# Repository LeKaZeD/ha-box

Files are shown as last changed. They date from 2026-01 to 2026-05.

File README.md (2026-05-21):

# HA Box




**HA Box** is an open-source, modular home automation hub built around a Raspberry Pi 5 and Home Assistant OS. It integrates the main smart home protocols (Zigbee, Thread, 433 MHz) into a single 3D-printed enclosure, with a custom ESP32 interface board providing a local E-Paper display, touch, environmental sensing, and physical controls.

---

## Project overview

HA Box is composed of four independent layers that work together:

```
+---------------------------------------------------------------+
|  3D-printed enclosure  (modular, FDM-printable, upgradeable)  |
|                                                               |
|  +---------------------------+   +-------------------------+  |
|  |  Raspberry Pi 5 stack     |   |  haboxesp PCB + ESP32   |  |
|  |  - Pi 5                   |   |  - E-Paper display      |  |
|  |  - M.2 SSD hat            |   |  - Touch (FT6336U)      |  |
|  |  - HDMI/USB-C extension   |   |  - BME280 sensor        |  |
|  |  - Sonoff Dongle Plus E   |   |  - Temp sensor TMP102   |  |
|  |    (Zigbee + Thread)      |   |  - Fan (PWM)            |  |
|  |  - CC1101 module (planned)|   |  - Buzzer               |  |
|  |    (433 MHz, SPI)         |   |  - Power button + J2    |  |
|  |                           |   |                         |  |
|  |  [ Home Assistant OS ]    |   |                         |  |
|  |  [ HA Box App (py) ]   <--+---+--> UART                 |  |
|  +---------------------------+   +-------------------------+  |
+---------------------------------------------------------------+
```

| Layer | Description | Location |
|---|---|---|
| **Hardware** | Pi 5 stack, haboxesp PCB, Sonoff dongle, connectors | `hardware/` |
| **3D enclosure** | Modular, printable enclosure for all components | `hardware/3D plan/` |
| **ESP32 firmware** | Drives display, sensors, touch, fan, buzzer | `ha-box-esp/` |
| **HA App** | Python app: UART bridge to HA API and Supervisor | `ha-box/` |
| **HA integration** | Custom component: groups all HA Box entities in the device registry | `ha-integration/` |

---

## Hardware

### Raspberry Pi 5 stack

| Component | Description | Protocol |
|---|---|---|
| Raspberry Pi 5 | Main compute unit, runs Home Assistant OS | — |
| M.2 SSD hat | NVMe storage via PCIe | PCIe |
| HDMI + USB-C extension | Rear panel port routing | — |
| Sonoff Zigbee 3.0 USB Dongle Plus E | Zigbee and Thread coordinator | USB |
| CC1101 module | 433 MHz radio (planned) | SPI |

### haboxesp PCB + ESP32

The haboxesp is a custom PCB designed for this project. It hosts an ESP32 module and provides connectors for all user-facing peripherals. The ESP32 communicates with the Pi exclusively over UART.

| Component | Model | Interface |
|---|---|---|
| E-Paper display | GDEY037T03-FT21 (3.7", 240×416) | SPI |
| Touch controller | FT6336U (integrated in display) | I2C |
| Environmental sensor | BME280 (temperature, humidity, pressure) | I2C |
| Case temperature | Additional sensor | I2C / analog |
| Fan | 5V PWM | PWM |
| Buzzer | Haptic feedback | GPIO |
| Power button | Wake + shutdown trigger | GPIO |
| J2 connector | Raspberry Pi J2 header (power control) | — |

PCB design files (KiCad) and manufacturing exports are in `hardware/haboxesp/`.

### 3D-printed enclosure

The enclosure is designed in Fusion 360, modular and FDM-printable. Each part can be reprinted independently to accommodate hardware upgrades.

Printable parts (STL): `Box`, `Top`, `Backplate`, `Support`, `Pied`, `Button`.

| | |
|---|---|
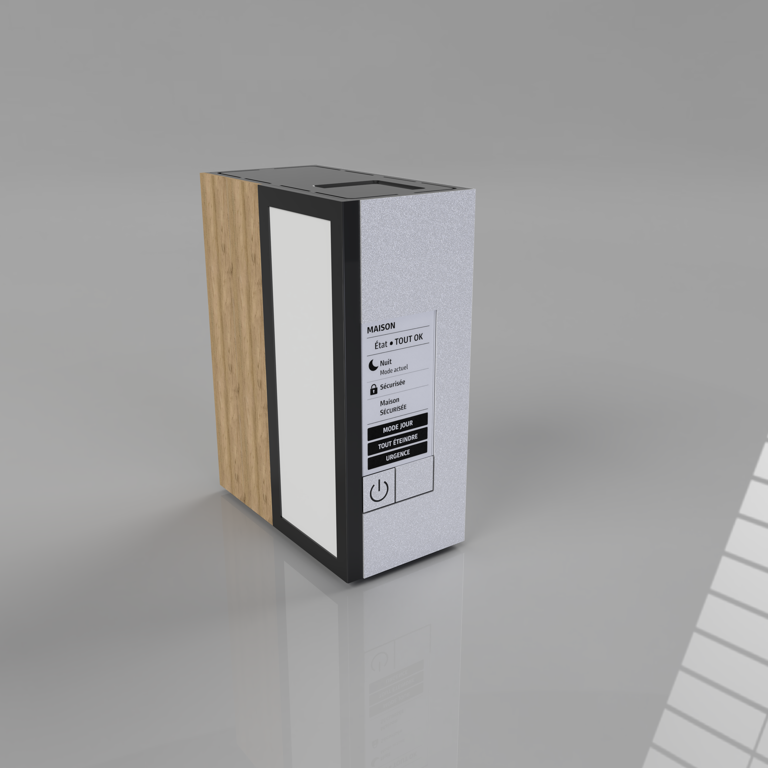
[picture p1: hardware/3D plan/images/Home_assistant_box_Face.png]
Front
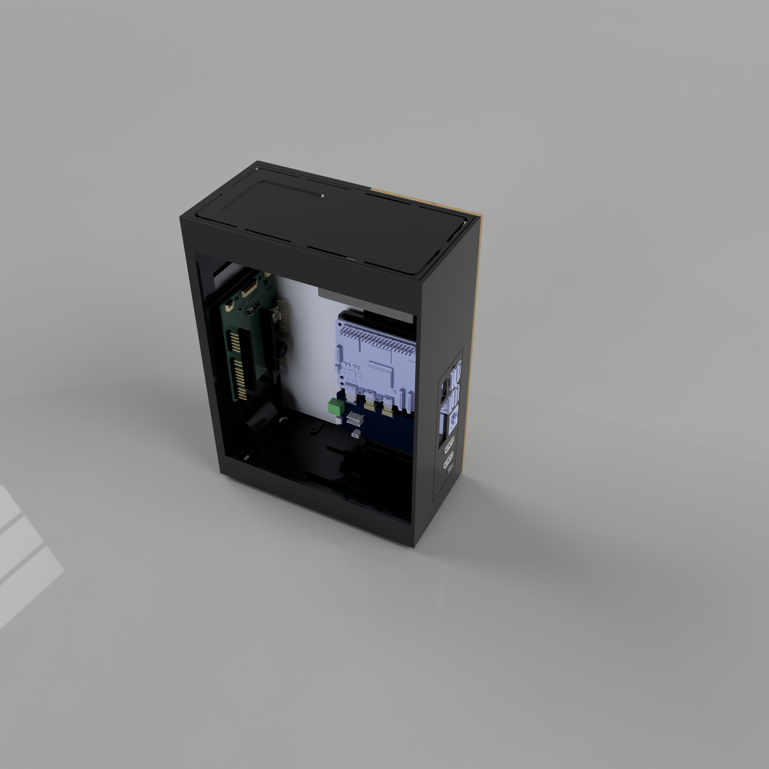
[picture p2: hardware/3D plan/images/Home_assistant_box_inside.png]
Inside
|  |  |

Fusion 360 source and STEP files: `hardware/3D plan/Fusion/`.

---

## ESP32 firmware

The ESP32 firmware (`ha-box-esp-fw/`) is a C++ application that:

- drives the E-Paper display (SPI) and front-light
- reads touch input (I2C, FT6336U)
- reads temperature/humidity/pressure (I2C, BME280)
- controls the fan (PWM, temperature-based)
- manages the power button (wake from deep sleep, shutdown request)
- controls the buzzer for haptic feedback
- communicates with the Pi App over UART using a line-based ASCII protocol

See [ha-box-esp-fw/ESPHOMEASSISTANT/ARCHITECTURE.md](ha-box-esp-fw/ESPHOMEASSISTANT/ARCHITECTURE.md) and [docs/ESP32_RASP_COM.md](docs/ESP32_RASP_COM.md) for the firmware architecture and UART protocol.

---

## HA App

The HA Box App (`ha-box/`) is a Home Assistant OS Supervisor App written in Python. It runs inside a Docker container on the Pi and acts as a bridge between the ESP32 (UART) and Home Assistant (HTTP API + Supervisor API).

It does not access display, sensors, or actuators directly. All peripherals are on the ESP32 side; the App communicates over UART0 and controls two Pi GPIOs (IO0 + EN) for OTA firmware updates.

### Raspberry Pi configuration (UART)

Edit `/mnt/boot/config.txt` physically (keyboard + screen on the Pi, or SD card / NVMe mounted on a computer). See [docs/HARDWARE.md](docs/HARDWARE.md#pi-configtxt-haos) for Pi 4 vs Pi 5 differences and SPI (CC1101) setup. Reboot after: `ha host reboot`.

### Installation

1. Add this repository to your Home Assistant Apps:

   

   Or manually: **Settings** → **App** → **App Store** → **⋮** → **Repositories** → add the URL.

2. Install **HA Box**.
3. Install the **HA Box custom integration**: copy `ha-integration/custom_components/ha_box/` to your HA `config/custom_components/` folder, then restart Home Assistant. This creates the HA Box device in the device registry.
4. Configure options according to your hardware (see below).
5. Start the App.

### Configuration

Configure options in the App UI or directly in YAML. Restart the App to apply changes.

```yaml
general:
  log_level: "info"                         # debug | info | warning | error | critical
  lang: "auto"                              # auto | fr | en

weather:
  weather_entity: "weather.forecast_home"   # HA weather entity
  update_interval: 300                      # seconds (10–3600)

bme280:
  enabled: true
  address: "auto"                           # auto | 0x76 | 0x77
  update_interval: 30                       # seconds

fan:
  enabled: false
  min_temp: 28                              # °C — fan starts
  max_temp: 60                              # °C — fan at full speed

ota:
  io0_gpio: 23                              # Pi BCM GPIO → ESP32 IO0
  en_gpio: 24                               # Pi BCM GPIO → ESP32 EN

daynight:
  update_interval: 60                       # seconds between sun.sun polls (10–3600)

clock:
  update_interval: 60                       # seconds (10–3600)

status:
  update_interval: 30                       # seconds
  exposed_addon_slugs: []                   # slugs that activate the "exposed" icon

uart:
  device: "auto"                            # auto | /dev/serial0 | /dev/ttyAMA0 | /dev/ttyUSB0

connection:
  connected_timeout: 120                    # seconds before switching to reconnecting
  reconnecting_timeout: 60                  # seconds before switching to disconnected
```

Language is auto-detected from the Home Assistant Core configuration (`/api/config` → `language`), with fallback to the container environment (`LANG`) and then English.

Fan and OTA options are sent to the ESP32 on every App startup and persisted in NVS — restart the App to apply changes.

---

## Current status (v0.2.0)

| Feature | Interface | Status |
|---|---|---|
| E-Paper display (Home, Loading, Settings pages) | SPI (ESP32) | Implemented |
| Touch navigation | I2C (ESP32) | Implemented |
| BME280 (temp, humidity, pressure) → HA entities | UART (ESP32 → Pi) | Implemented |
| TMP102 case temperature → HA entity | UART (ESP32 → Pi) | Implemented |
| Fan control (PWM, temperature-based, configurable) | PWM (ESP32) | Implemented |
| Power button (wake, soft shutdown, hard J2 stop) | UART + J2 (ESP32 ↔ Pi) | Implemented |
| Weather + clock display | UART (Pi → ESP32) | Implemented |
| HA status icons (Core, Supervisor, Net, Zigbee, Thread, Matter, External) | UART (Pi → ESP32) | Implemented |
| OTA firmware update (auto version check + flash over UART0) | UART0 + GPIO | Implemented |
| Boot failure recovery (blind OTA flash on ROM boot errors) | UART0 + GPIO | Implemented |
| Day/Night mode sync (sun.sun + manual override, HA event + binary sensor) | UART (Pi ↔ ESP32) | Implemented |
| HA Box integration (device registry, grouped entities) | HA custom component | In progress |
| CC1101 433 MHz | SPI (Pi) | Planned |

---

## Future: Compute Module board

The long-term vision is a custom carrier board built around a Raspberry Pi Compute Module, integrating the Pi, ESP32, radio modules, and all connectors on a single PCB. This would replace the current assembly of off-the-shelf boards and the haboxesp PCB with a more compact, reliable, and user-friendly product.

Early design work is in `hardware/cm5/`.

---

## Repository structure

```
ha-box/
├── hardware/
│   ├── haboxesp/          KiCad PCB project (haboxesp V0.1)
│   ├── 3D plan/           Fusion 360 enclosure + STL parts
│   └── cm5/               Compute Module carrier board (early stage)
├── ha-box-esp/         ESP32 firmware (C++)
├── ha-box/                HA App (Python)
│   ├── rootfs/            App runtime files
│   ├── config.yaml        App manifest
│   └── translations/      UI translations (en, fr)
├── ha-integration/        HA custom integration (device registry, grouped entities)
│   └── custom_components/
│       └── ha_box/
├── docs/                  Technical documentation
└── README.md
```

---

## Documentation

| Document | Description |
|---|---|
| [docs/ARCHITECTURE.md](docs/ARCHITECTURE.md) | App technical architecture |
| [docs/HARDWARE.md](docs/HARDWARE.md) | Hardware specifications (haboxesp PCB + ESP32) |
| [docs/ESP32_RASP_COM.md](docs/ESP32_RASP_COM.md) | UART protocol (Pi ↔ ESP32) |
| [docs/FEATURES_STATUS.md](docs/FEATURES_STATUS.md) | Feature status and timing reference |
| [docs/TECH_STACK.md](docs/TECH_STACK.md) | Libraries and technical stack |
| [docs/I18N.md](docs/I18N.md) | Multilingual support |
| [ROADMAP.md](ROADMAP.md) | Current status and future plans |
| [CONTRIBUTING.md](CONTRIBUTING.md) | Contribution guide |
| [ha-box/SECURITY.md](ha-box/SECURITY.md) | Security policy |
| [TESTING.md](TESTING.md) | Development and testing guide |

---

## Contributing

Contributions are welcome. See [CONTRIBUTING.md](CONTRIBUTING.md) to get started.

---

## License

Apache License 2.0. See [LICENSE](LICENSE).

---

*Project started January 17, 2026*

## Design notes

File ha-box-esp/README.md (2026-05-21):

# ha-box-esp — ESP32 Firmware

C++ firmware for the haboxesp board. Manages the E-Paper display, touch, sensors (BME280, TMP102), fan, buzzer, and power button. Communicates with the Pi App over UART0 using the ASCII protocol defined in [docs/ESP32_RASP_COM.md](../docs/ESP32_RASP_COM.md).

## Build & Flash

Uses [PlatformIO](https://platformio.org). Dependencies (GxEPD2 display driver, etc.) are fetched automatically from `platformio.ini`.

```bash
# Install PlatformIO CLI or open the project in VS Code with the PlatformIO extension
pio run --target upload
```

The OTA update is handled automatically by the App on every startup if the bundled firmware version differs from the ESP32 reported version.

## Releasing a new firmware version

1. Increment `FIRMWARE_VERSION` in [`src/config.h`](src/config.h)
2. Build: `pio run` → binary at `.pio/build/upesy_wroom/firmware.bin`
3. Copy to the App firmware folder with the version in the filename:
   ```
   cp .pio/build/upesy_wroom/firmware.bin ../ha-box/firmware/firmware-{VERSION}.bin
   ```
   The App reads the version from the filename (pattern `firmware-*.bin`) and flashes automatically on startup if it differs from the ESP32-reported version.

## Pin configuration

See [`src/config.h`](src/config.h) for all GPIO assignments and [`docs/HARDWARE.md`](../docs/HARDWARE.md) for the full pinout.

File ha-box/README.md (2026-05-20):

# HA Box – Home Assistant App



Bridges the **haboxesp** ESP32 board with Home Assistant. Drives the E-Paper display, sensors, clock, weather, day/night mode, fan control, and exposes a RFLink-compatible TCP server for the CC1101 433 MHz module.

Requires a Raspberry Pi 4 or 5 running Home Assistant OS with the haboxesp board connected via UART.

See the **Documentation** tab for installation, configuration, and setup.

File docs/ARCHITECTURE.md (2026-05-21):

# Technical Architecture - HA Box

This document describes the technical architecture of the HA Box App and its link to the ESP32 firmware.

## Overview

The HA Box App runs on Home Assistant OS (Raspberry Pi) inside a Supervisor-managed container. It does **not** drive display, sensors, or actuators directly on the Pi. Instead, it talks to an **ESP32** over **UART** (serial). The ESP32 runs the E-Paper display, touch, BME280, fan, and power-button logic; the App provides Home Assistant integration (Supervisor/Core API), status aggregation, and data push/pull over the ASCII protocol.

```
┌─────────────────────────────────────────────────────────────────────────┐
│                        Home Assistant OS (Raspberry Pi)                  │
│  ┌───────────────────────────────────────────────────────────────────┐  │
│  │                         Supervisor                                │  │
│  │  ┌─────────────────────────────────────────────────────────────┐  │  │
│  │  │              HA Box App.  (Container)                       │  │  │
│  │  │                                                              │  │  │
│  │  │  ┌─────────────┐  ┌──────────────────────────────────────┐  │  │  │
│  │  │  │   Handlers  │  │  Communication (UART)                │  │  │  │
│  │  │  │  Weather    │  │  esp32_comm, message_handler,         │  │  │  │
│  │  │  │  Clock      │  │  connection_manager                    │  │  │  │
│  │  │  │  Status     │  └──────────────────┬───────────────────┘  │  │  │
│  │  │  │  Sensor     │                       │                      │  │  │
│  │  │  └──────┬─────┘                       │                      │  │  │
│  │  │         │                             │                      │  │  │
│  │  │  ┌──────┴─────────────────────────────┴──────────────────┐  │  │  │
│  │  │  │  API (Supervisor + Core): config, states, services,    │  │  │  │
│  │  │  │  host shutdown, status fetchers                        │  │  │  │
│  │  │  └────────────────────────────┬───────────────────────────┘  │  │  │
│  │  └───────────────────────────────┼──────────────────────────────┘  │  │
│  └──────────────────────────────────┼──────────────────────────────────┘  │
│                                     │                                      │
│  ┌──────────────────────────────────┼──────────────────────────────────┐  │
│  │  Linux kernel                     │   /dev/serial0, /dev/ttyAMA0      │  │
│  └──────────────────────────────────┼──────────────────────────────────┘  │
└─────────────────────────────────────┼───────────────────────────────────────┘
                                      │ UART (115200 8N1)
                                      ▼
┌─────────────────────────────────────────────────────────────────────────────┐
│                              ESP32                                           │
│  ┌───────────────────────────────────────────────────────────────────────┐  │
│  │  AsciiProto (UART)  ◄──────────────────────────────────────────────►  │  │
│  │  PowerButton (GPIO btn + J2), Model, UI (Loading / Home / Settings)   │  │
│  └───────┬───────────────────────────────────────────────────────────────┘  │
│          │                                                                  │
│  ┌───────┴───────┐  ┌────────┐  ┌────────┐  ┌────────┐  ┌─────┐  ┌──────┐  │
│  │ E-Paper (SPI) │  │ Touch  │  │ BME280 │  │ Fan │  │ J2   │  │
│  │ GDEY037T03    │  │ FT6336 │  │ I2C    │  │ PWM │  │Power │  │
│  └───────────────┘  └────────┘  └────────┘  └────────┘  └─────┘  └──────┘  │
└─────────────────────────────────────────────────────────────────────────────┘
```

See [docs/ESP32_RASP_COM.md](ESP32_RASP_COM.md) for the UART protocol and responsibilities split between Pi and ESP32.

## Main Components (App)

### 1. API Layer (`api/ha_api.py`)

Client for the Supervisor API and Home Assistant Core API.

**Responsibilities:**
- Supervisor: info, network, addons list/info, host shutdown
- Core: config (e.g. language), entity states, services (e.g. `light.turn_off`)
- Aggregation of system status (core, supervisor, network, Zigbee/Thread/Matter via Apps and Core entities) for the STATUS message to the ESP32

**Authentication:** `SUPERVISOR_TOKEN` and `SUPERVISOR_URL` from the environment.

### 2. Communication (`communication/`)

UART link to the ESP32.

**Components:**
- **esp32_comm**: Serial open/close, line framing, parsing of ASCII protocol (`<id> VERB [key=val ...]` and `ACK <id> OK|ERR`), send commands, optional send-with-ACK, background poll thread; detects ROM boot failure patterns (`boot_failure_count`)
- **message_handler**: Routes incoming messages (READY, VERSION, SENS, CASE, STATUS, TOUCH, ALL_OFF, SHUTDOWN_REQUEST); authorizes verbs; triggers host shutdown and sends SHUTDOWN_ACCEPTED; stores `esp32_firmware_version`
- **connection_manager**: State machine (CONNECTING, CONNECTED, RECONNECTING, DISCONNECTED); periodic READY when not connected; relies on StatusHandler for STATUS when connected
- **ota_manager**: Compares bundled firmware version (`ha-box/firmware/VERSION`) with ESP32 reported version; controls IO0/EN GPIOs via `gpiod`; invokes `esptool.main()` in-process to flash `0x10000`; handles blind-flash recovery on boot failure

### 3. Handlers (`handlers/`)

**SensorHandler:** Receives SENS (tC, hum, pPa) and CASE (tC) from the ESP32, fires `ha_box_sensors` and `ha_box_case_temp` events on the HA event bus. The HA Box integration listens to these events and updates entities in the device registry.

**WeatherHandler:** Fetches weather entity from Core, sends WEATHER (code, tOut) to the ESP32 on a timer when connected.

**ClockHandler:** Sends CLOCK (hh, mm, ss) to the ESP32 on a timer when connected.

**StatusHandler:** Uses status fetchers (core, supervisor, network, addons for Zigbee/Thread/Matter, etc.) to build a status dict and sends STATUS with key/values to the ESP32 on a timer when connected. Acts as the heartbeat in CONNECTED state.

**DayNightHandler:** Polls sun.sun periodically and sends DAYMODE (mode=0/1) to the ESP32. Handles manual override when the user touches the day/night switch on the ESP32 (DAYMODE message from ESP32); the override is cleared on the next real sun event. Fires `ha_box_mode_changed` event on every mode change.

### 4. Core (`core/`)

- **config**: Load options from `SUPERVISOR_OPTIONS` (e.g. `/data/options.json`), build `Config` with all `box.*` sections (weather, bme280, fan, ota, daynight, clock, status, uart, connection)
- **i18n**: Translator; language from HA Core config when available, else env (LANG, SUPERVISOR_LANGUAGE), else default English
- **logger**: Logging setup

The App does **not** include a Hardware Abstraction Layer (HAL) for I2C/SPI/GPIO on the Pi. All display, touch, BME280, fan, and power-button handling run on the **ESP32**. Pin and bus details are in [docs/HARDWARE.md](HARDWARE.md) and the ESP32 firmware (e.g. `esp/ESPHOMEASSISTANT/`).

## Communication with Home Assistant

### Supervisor and Core API

The App communicates with the Supervisor and Home Assistant Core via HTTP/REST using the Supervisor proxy:

```
┌─────────────┐     HTTP/REST      ┌─────────────┐
│   HA Box    │ ◄────────────────► │  Supervisor │
│    App      │  SUPERVISOR_TOKEN  │     API     │
└─────────────┘                    └──────┬──────┘
                                           │
                                    ┌──────┴──────┐
                                    │ Core API    │
                                    │ (e.g. /core/api/config, states, services)
                                    └─────────────┘
```

### Endpoints used

| Endpoint | Usage |
|---|---|
| `/core/api/config` | Read Core config (e.g. language for i18n) |
| `/core/api/states` | Read entity states (weather, sun.sun) |
| `/core/api/events/<type>` | Fire events (`ha_box_sensors`, `ha_box_case_temp`, `ha_box_mode_changed`) |
| `/core/api/services/light/turn_off` | Call services (e.g. all lights off) |
| `/host/shutdown` | Request host shutdown (power button short press) |
| `/supervisor/info` | Supervisor status |
| `/network/info` | Network interfaces |
| `/addons`, `/addons/<slug>/info` | App list and options (status, Zigbee/Thread/Matter detection) |

### UART link to ESP32

The App talks to the ESP32 over a serial device (`/dev/serial0` or `/dev/ttyAMA0`) at 115200 8N1. Protocol: ASCII lines `<id> VERB [key=value ...]` with ACK lines `ACK <id> OK|ERR <code>`. See [docs/ESP32_RASP_COM.md](ESP32_RASP_COM.md) for the verb list and responsibilities.

## File structure (App)

```
ha-box/
├── config.yaml           # App configuration (options, schema, devices)
├── build.yaml            # Build configuration (if used)
├── Dockerfile            # Docker image
├── apparmor.txt          # AppArmor profile (when enabled)
├── CHANGELOG.md
├── README.md
├── icon.png
├── logo.png
├── translations/
│   ├── en.yaml
│   └── fr.yaml
└── rootfs/
    ├── etc/
    │   └── services.d/
    │       └── ha-box/
    │           ├── run       # Startup script (s6)
    │           └── finish    # Shutdown script (s6)
    └── usr/
        └── bin/
            └── ha-box/
                ├── main.py              # Entry point
                ├── core/
                │   ├── __init__.py
                │   ├── config.py        # Options, Config
                │   ├── i18n.py          # Translator, language detection
                │   └── logger.py
                ├── api/
                │   ├── __init__.py
                │   └── ha_api.py        # Supervisor + Core API client
                ├── communication/
                │   ├── __init__.py
                │   ├── esp32_comm.py    # UART, protocol, ACK, boot failure detection
                │   ├── message_handler.py
                │   ├── connection_manager.py
                │   └── ota_manager.py   # OTA flash via esptool (GPIO + UART0)
                └── handlers/
                    ├── __init__.py
                    ├── sensor_handler.py
                    ├── weather_handler.py
                    ├── clock_handler.py
                    ├── status_handler.py
                    ├── daynight_handler.py
                    └── status_fetchers/
                        ├── __init__.py
                        ├── core.py
                        ├── supervisor.py
                        ├── network.py
                        ├── addons.py
                        ├── zigbee.py
                        ├── thread.py
                        └── matter.py
```

## Required hardware configuration

### Raspberry Pi (HAOS)

The App uses only **UART** to talk to the ESP32. No I2C, SPI, or GPIO are required on the Pi for the App.

Edit `/mnt/boot/config.txt` per [docs/HARDWARE.md](HARDWARE.md#pi-configtxt-haos), then reboot. The serial device will appear as `/dev/serial0` or `/dev/ttyAMA0`. See [docs/ESP32_RASP_COM.md](ESP32_RASP_COM.md) for wiring and OTA GPIO pin details.

### ESP32 (firmware)

Display (SPI), touch (I2C), BME280 (I2C), fan (PWM), and power button (GPIO + J2) are on the **ESP32** side. Pin assignments, I2C addresses, and bus layout are documented in [docs/HARDWARE.md](HARDWARE.md). Summary:

| Device | Interface | Address / pin (ESP32) | Notes |
|---|---|---|---|
| Touch (FT6336U) | I2C | 0x38 | Integrated in GDEY037T03-FT21 |
| BME280 | I2C | 0x76 or 0x77 | Configurable in App options |
| E-Paper | SPI | CS, DC, RST, BUSY, etc. | See HARDWARE.md and firmware |
| Fan | PWM | Configurable (e.g. GPIO 18) | Local control on ESP32 |
| Power button | GPIO | e.g. GPIO 33 | ext0 wake; J2 pulse (e.g. GPIO 26) for Pi power |

## Startup sequence

```
┌────────────────────────────────────────────────────────────────┐
│ 1. Supervisor starts the container                              │
├────────────────────────────────────────────────────────────────┤
│ 2. s6-overlay runs the 'run' script                             │
├────────────────────────────────────────────────────────────────┤
│ 3. main.py: load options, build Config                          │
├────────────────────────────────────────────────────────────────┤
│ 4. Initialize HA API client (Supervisor URL, token)             │
├────────────────────────────────────────────────────────────────┤
│ 5. Language: get_core_language() or env fallback, get_translator│
├────────────────────────────────────────────────────────────────┤
│ 6. Handlers: SensorHandler, WeatherHandler, ClockHandler,       │
│    StatusHandler; ESP32 comm and connection_manager             │
├────────────────────────────────────────────────────────────────┤
│ 7. Open serial port, start poll thread, set callbacks            │
├────────────────────────────────────────────────────────────────┤
│ 8. Initialization loop: send READY periodically until           │
│    connection_manager.is_connected() (recent message from ESP32) │
│    — if ESP32 sends ROM boot errors (>= 3), trigger blind OTA   │
│      flash (GPIO IO0/EN + esptool) without waiting for VERSION  │
├────────────────────────────────────────────────────────────────┤
│ 9. OTA check: query VERSION from ESP32 (up to 3 retries);       │
│    if bundled version differs, flash via esptool; restart loop  │
├────────────────────────────────────────────────────────────────┤
│10. Once connected: send LANG + FAN config, force               │
│    weather/clock/status update, start periodic timers          │
├────────────────────────────────────────────────────────────────┤
│11. Main loop: connection_manager.update(), send READY/STATUS   │
│    as needed; sensor_handler.update_home_assistant() from SENS  │
│    If connection lost, return to step 8                         │
└────────────────────────────────────────────────────────────────┘
```

## Error handling

### Fallback strategy

| Error | Behavior |
|---|---|
| Core not available at startup | Language falls back to env or default; API calls (e.g. weather, config) fail until Core is up; handlers retry or skip |
| Serial port missing or open failure | App logs error and exits or runs without ESP32 (depending on startup path) |
| ESP32 disconnection (no recent message) | connection_manager moves to RECONNECTING then DISCONNECTED; READY sent periodically; when message received again, CONNECTED and services resume |
| Host shutdown request fails (e.g. 403) | Log warning; ESP32 does not receive SHUTDOWN_ACCEPTED and may use shutdownPendingTimeoutMs then deep sleep |
| Sensor/weather/status API failure | Handlers log and skip or use cached data; next cycle retries |

### Logging

Use `bashio::log.*` for bash scripts and Python `logging` module:

```python
import logging
logging.basicConfig(level=logging.INFO)
logger = logging.getLogger("ha-box")
```

Levels:
- `DEBUG`: Technical details
- `INFO`: Normal events
- `WARNING`: Non-blocking issues
- `ERROR`: Recoverable errors
- `CRITICAL`: Fatal errors

## Security

### Permissions (current)

The App uses serial devices for the ESP32 link and GPIO for OTA:

```yaml
devices:
  - /dev/ttyAMA0
  - /dev/serial0
  - /dev/gpiochip0
gpio: true
```

`gpio: true` and `/dev/gpiochip0` are required for the OTA manager to control the IO0 and EN pins. I2C and SPI are not used on the Pi. If AppArmor is enabled, the profile must allow access to the chosen serial device(s) and to Supervisor/network as used by the API client. See [ha-box/SECURITY.md](../ha-box/SECURITY.md) and [docs/HA_APPS_COMPLIANCE.md](HA_APPS_COMPLIANCE.md).

---

## Multilingual support (i18n)

- **Translation files**: `ha-box/translations/{language}.yaml` (e.g. en, fr) for configuration UI labels/descriptions (used by Home Assistant).
- **Python**: `core/i18n.py` provides a `Translator` and `get_translator()`. Language is chosen in this order: explicit from HA Core config (`/core/api/config` → `language`), then `LANG` or `SUPERVISOR_LANGUAGE` from the environment, then default English.
- **ESP32**: The App sends `LANG` with `id=0` (French) or `id=1` (English) so the firmware can show text in the correct language.

See [docs/I18N.md](I18N.md) for full details if present.

## HA Box integration (custom component)

A companion HA integration (`ha-integration/custom_components/ha_box/`) listens to events fired by the App and exposes all entities under a single **HA Box** device in the HA device registry:

| Event | Entities created |
|---|---|
| `ha_box_sensors` | Temperature, Humidity, Pressure |
| `ha_box_case_temp` | Case Temperature |
| `ha_box_mode_changed` | Mode (Jour / Nuit) |

Install by copying `custom_components/ha_box/` to your HA config folder, restarting HA, then adding the integration via Settings → Devices & Services → Add Integration → HA Box.

## Future evolutions

- Publish integration to HACS
- Additional languages (e.g. DE, ES) in translations and LANG id mapping

---

*Last updated: 2026-04-02*

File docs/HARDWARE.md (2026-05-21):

# Hardware - HA Box

All user-facing peripherals (display, touch, sensors, fan, buzzer, power button) are on the **haboxesp PCB** driven by an **ESP32-WROOM-32**. The Raspberry Pi 5 connects to the ESP32 only via UART0 and two GPIO pins for OTA.

---

## Raspberry Pi 5 stack

| Component | Interface | Notes |
|---|---|---|
| Raspberry Pi 5 | — | Main compute; runs Home Assistant OS |
| M.2 SSD hat | PCIe | NVMe storage |
| HDMI + USB-C extension | — | Rear panel port routing |
| Sonoff Zigbee 3.0 USB Dongle Plus E | USB | Zigbee + Thread coordinator |
| CC1101 module | SPI0 (CE0) | 433 MHz radio — RFLink TCP server on :5557 |

### Pi GPIO used by the App

| BCM GPIO | Direction | Connected to | Purpose |
|---|---|---|---|
| 14 (TXD) | Out | ESP32 GPIO 3 (RX0) | UART0 communication |
| 15 (RXD) | In | ESP32 GPIO 1 (TX0) | UART0 communication |
| 23 | Out | ESP32 IO0 | OTA: pull LOW to enter ROM bootloader |
| 24 | Out | ESP32 EN | OTA: pulse LOW → HIGH to reset chip |
| 3.3V (pin 1) | Power | ESP32 GPIO5 (via 1kΩ) | Pi alive signal: HIGH = Pi on, LOW = Pi off |
| 10 (MOSI) | Out | CC1101 MOSI | SPI0 data out |
| 9 (MISO) | In | CC1101 MISO | SPI0 data in |
| 11 (SCK) | Out | CC1101 SCK | SPI0 clock |
| 8 (CE0) | Out | CC1101 CSN | SPI0 chip select |
| 17 | In | CC1101 GDO0 | RX data / interrupt |
| 27 | In | CC1101 GDO2 | Carrier detect / FIFO threshold |

### Pi config.txt (HAOS)

Edit `/mnt/boot/config.txt` (boot partition — not accessible via SSH; use physical access or mount the SD card/NVMe on a computer). The UART must be freed from Bluetooth to expose `/dev/ttyAMA0` to the App.

**Raspberry Pi 4** — disables Bluetooth entirely:
```ini
enable_uart=1
dtoverlay=disable-bt
```

**Raspberry Pi 5** — Bluetooth coexists; only `enable_uart=1` is required in most HAOS configurations:
```ini
enable_uart=1
```

For CC1101 433 MHz support (SPI), add on any model:
```ini
dtparam=spi=on
```

After editing, reboot: `ha host reboot`.

---

## haboxesp PCB + ESP32

Custom PCB hosting an ESP32-WROOM-32 with connectors for all peripherals.
KiCad project files: `hardware/haboxesp/`.

### ESP32 peripherals

| Component | Model | Interface | ESP32 pins | Notes |
|---|---|---|---|---|
| E-Paper display | GDEY037T03-FT21 (3.7", 240×416) | SPI | See SPI table below | GxEPD2 driver |
| Touch | FT6336U (integrated in display) | I2C | SDA/SCL | Address 0x38 |
| Pi alive | — | GPIO | GPIO5 (VEN pad, via 1kΩ pull-down) | Detects Pi power-off; Pi 3.3V → 1kΩ → GPIO5; `INPUT_PULLDOWN` in firmware |
| Environmental sensor | BME280 | I2C | SDA/SCL | Address 0x76 |
| Case temperature | TMP102 | I2C | SDA/SCL | Address defined in `config.h` |
| Fan | 5 V PWM | PWM | GPIO (config.h) | Temperature-based curve |
| Buzzer | — | GPIO | GPIO (config.h) | 100 ms beep on events |
| Power button | — | GPIO | GPIO 33 (RTC ext0) | Wake from deep sleep |
| J2 connector | — | GPIO | GPIO 26 | Pi power control (pulse = power on/off) |
| UART0 (Pi comm) | — | UART | GPIO 1 (TX) / GPIO 3 (RX) | Pi communication + esptool OTA |
| UART2 (debug) | — | UART | GPIO 17 (TX) / GPIO 16 (RX) | Debug output only; not connected to Pi |

---

## E-Paper display — GDEY037T03-FT21

**Manufacturer**: GooDisplay  
**Controller**: UC8253  
**Datasheet**: `GDEY037T03-FT21.pdf`

| Parameter | Value |
|---|---|
| Size | 3.7" |
| Resolution | 240 × 416 pixels |
| DPI | 130 |
| Active area | 47.04 × 81.54 mm |
| Interface | SPI 4-wire |
| Front-light | 9 LEDs, 2.8 V typical, MOSFET PWM |
| Touch | FT6336U (I2C, address 0x38) |

### SPI wiring (ESP32)

| Signal | ESP32 GPIO |
|---|---|
| CS | GPIO 27 |
| DC | GPIO 14 |
| RST | GPIO 12 |
| BUSY | GPIO 13 |
| SCK | GPIO 18 |
| MOSI | GPIO 23 |
| Colors | 1-bit (black / white) |
| Full refresh | ~2–3 s |
| Partial refresh | ~1 s |
| Standby | 34 µA |
| Deep sleep | 1.1 µA |
| Operating temp | -25 °C to 70 °C |

Front-light: MOSFET default-off (low = off); PWM controls brightness.

---

## BME280 — Environmental sensor

| Parameter | Value |
|---|---|
| Interface | I2C |
| Address | 0x76 (haboxesp default) |
| Temperature | -40 °C to +85 °C, ±1 °C |
| Humidity | 0–100 % RH, ±3 % |
| Pressure | 300–1100 hPa, ±1 hPa |

Polled every 5 s on ESP32; sent to Pi every 30 s via `SENS tC hum pPa`.

---

## TMP102 — Case temperature sensor

| Parameter | Value |
|---|---|
| Interface | I2C |
| Address | Defined in `config.h` |
| Range | -40 °C to +125 °C, ±0.5 °C |

Polled every 5 s by the fan controller; sent to Pi every 30 s via `CASE tC`.

---

## CC1101 — 433 MHz radio module

| Parameter | Value |
|---|---|
| Interface | SPI0, CE0 (GPIO8) |
| Frequency | 433.92 MHz (OOK) |
| GDO0 | GPIO17 (pin 11) — RX data / interrupt |
| GDO2 | GPIO27 (pin 13) — carrier detect / FIFO threshold |
| VCC | 3.3 V (pin 1) |
| GND | GND (pin 6) |

The App exposes a **RFLink-compatible TCP server** on `:5557`.
Point the HA RFLink integration (or any RFLink-compatible client) at `localhost:5557`.

**HA configuration (`configuration.yaml`)**:
```yaml
rflink:
  host: localhost
  port: 5557
```

Enable in the App options:
```yaml
box:
  rf433:
    enabled: true
    tcp_port: 5557   # default
```

---

## 3D-printed enclosure

Designed in Fusion 360, FDM-printable and modular. Each part can be reprinted independently for hardware upgrades.

**Materials**: PLA body + acrylic window panel + steel backplate.  
**Fasteners**: M2.5 inserts (3.5 mm OD).  
**Printable parts** (STL in `hardware/3D plan/`): `Box`, `Top`, `Backplate`, `Support`, `Pied`, `Button`.  
**Source files**: `hardware/3D plan/Fusion/` (Fusion 360 + STEP).

---

*Last updated: 2026-04-03*

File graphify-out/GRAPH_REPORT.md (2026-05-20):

# Graph Report - .  (2026-05-15)

## Corpus Check
- 153 files · ~721,329 words
- Verdict: corpus is large enough that graph structure adds value.

## Summary
- 1261 nodes · 1807 edges · 312 communities detected
- Extraction: 62% EXTRACTED · 38% INFERRED · 0% AMBIGUOUS · INFERRED: 692 edges (avg confidence: 0.65)
- Token cost: 0 input · 0 output

## Community Hubs (Navigation)
- [[_COMMUNITY_Community 0|Community 0]]
- [[_COMMUNITY_Community 1|Community 1]]
- [[_COMMUNITY_Community 2|Community 2]]
- [[_COMMUNITY_Community 3|Community 3]]
- [[_COMMUNITY_Community 4|Community 4]]
- [[_COMMUNITY_Community 5|Community 5]]
- [[_COMMUNITY_Community 6|Community 6]]
- [[_COMMUNITY_Community 7|Community 7]]
- [[_COMMUNITY_Community 8|Community 8]]
- [[_COMMUNITY_Community 9|Community 9]]
- [[_COMMUNITY_Community 10|Community 10]]
- [[_COMMUNITY_Community 11|Community 11]]
- [[_COMMUNITY_Community 12|Community 12]]
- [[_COMMUNITY_Community 13|Community 13]]
- [[_COMMUNITY_Community 14|Community 14]]
- [[_COMMUNITY_Community 15|Community 15]]
- [[_COMMUNITY_Community 16|Community 16]]
- [[_COMMUNITY_Community 17|Community 17]]
- [[_COMMUNITY_Community 18|Community 18]]
- [[_COMMUNITY_Community 19|Community 19]]
- [[_COMMUNITY_Community 20|Community 20]]
- [[_COMMUNITY_Community 21|Community 21]]
- [[_COMMUNITY_Community 22|Community 22]]
- [[_COMMUNITY_Community 23|Community 23]]
- [[_COMMUNITY_Community 24|Community 24]]
- [[_COMMUNITY_Community 25|Community 25]]
- [[_COMMUNITY_Community 26|Community 26]]
- [[_COMMUNITY_Community 27|Community 27]]
- [[_COMMUNITY_Community 28|Community 28]]
- [[_COMMUNITY_Community 29|Community 29]]
- [[_COMMUNITY_Community 30|Community 30]]
- [[_COMMUNITY_Community 31|Community 31]]
- [[_COMMUNITY_Community 32|Community 32]]
- [[_COMMUNITY_Community 33|Community 33]]
- [[_COMMUNITY_Community 34|Community 34]]
- [[_COMMUNITY_Community 35|Community 35]]
- [[_COMMUNITY_Community 36|Community 36]]
- [[_COMMUNITY_Community 37|Community 37]]
- [[_COMMUNITY_Community 38|Community 38]]
- [[_COMMUNITY_Community 39|Community 39]]
- [[_COMMUNITY_Community 40|Community 40]]
- [[_COMMUNITY_Community 41|Community 41]]
- [[_COMMUNITY_Community 42|Community 42]]
- [[_COMMUNITY_Community 43|Community 43]]
- [[_COMMUNITY_Community 44|Community 44]]
- [[_COMMUNITY_Community 45|Community 45]]
- [[_COMMUNITY_Community 46|Community 46]]
- [[_COMMUNITY_Community 47|Community 47]]
- [[_COMMUNITY_Community 48|Community 48]]
- [[_COMMUNITY_Community 49|Community 49]]
- [[_COMMUNITY_Community 50|Community 50]]
- [[_COMMUNITY_Community 51|Community 51]]
- [[_COMMUNITY_Community 52|Community 52]]
- [[_COMMUNITY_Community 53|Community 53]]
- [[_COMMUNITY_Community 54|Community 54]]
- [[_COMMUNITY_Community 55|Community 55]]
- [[_COMMUNITY_Community 56|Community 56]]
- [[_COMMUNITY_Community 57|Community 57]]
- [[_COMMUNITY_Community 58|Community 58]]
- [[_COMMUNITY_Community 59|Community 59]]
- [[_COMMUNITY_Community 60|Community 60]]
- [[_COMMUNITY_Community 61|Community 61]]
- [[_COMMUNITY_Community 62|Community 62]]
- [[_COMMUNITY_Community 63|Community 63]]
- [[_COMMUNITY_Community 64|Community 64]]
- [[_COMMUNITY_Community 65|Community 65]]
- [[_COMMUNITY_Community 66|Community 66]]
- [[_COMMUNITY_Community 67|Community 67]]
- [[_COMMUNITY_Community 68|Community 68]]
- [[_COMMUNITY_Community 69|Community 69]]
- [[_COMMUNITY_Community 70|Community 70]]
- [[_COMMUNITY_Community 71|Community 71]]
- [[_COMMUNITY_Community 72|Community 72]]
- [[_COMMUNITY_Community 73|Community 73]]
- [[_COMMUNITY_Community 74|Community 74]]
- [[_COMMUNITY_Community 75|Community 75]]
- [[_COMMUNITY_Community 76|Community 76]]
- [[_COMMUNITY_Community 77|Community 77]]
- [[_COMMUNITY_Community 78|Community 78]]
- [[_COMMUNITY_Community 79|Community 79]]
- [[_COMMUNITY_Community 80|Community 80]]
- [[_COMMUNITY_Community 81|Community 81]]
- [[_COMMUNITY_Community 82|Community 82]]
- [[_COMMUNITY_Community 83|Community 83]]
- [[_COMMUNITY_Community 84|Community 84]]
- [[_COMMUNITY_Community 85|Community 85]]
- [[_COMMUNITY_Community 86|Community 86]]
- [[_COMMUNITY_Community 87|Community 87]]
- [[_COMMUNITY_Community 88|Community 88]]
- [[_COMMUNITY_Community 89|Community 89]]
- [[_COMMUNITY_Community 90|Community 90]]
- [[_COMMUNITY_Community 91|Community 91]]
- [[_COMMUNITY_Community 92|Community 92]]
- [[_COMMUNITY_Community 93|Community 93]]
- [[_COMMUNITY_Community 94|Community 94]]
- [[_COMMUNITY_Community 95|Community 95]]
- [[_COMMUNITY_Community 96|Community 96]]
- [[_COMMUNITY_Community 97|Community 97]]
- [[_COMMUNITY_Community 98|Community 98]]
- [[_COMMUNITY_Community 99|Community 99]]
- [[_COMMUNITY_Community 100|Community 100]]
- [[_COMMUNITY_Community 101|Community 101]]
- [[_COMMUNITY_Community 102|Community 102]]
- [[_COMMUNITY_Community 103|Community 103]]
- [[_COMMUNITY_Community 104|Community 104]]
- [[_COMMUNITY_Community 105|Community 105]]
- [[_COMMUNITY_Community 106|Community 106]]
- [[_COMMUNITY_Community 107|Community 107]]
- [[_COMMUNITY_Community 108|Community 108]]
- [[_COMMUNITY_Community 109|Community 109]]
- [[_COMMUNITY_Community 110|Community 110]]
- [[_COMMUNITY_Community 111|Community 111]]
- [[_COMMUNITY_Community 112|Community 112]]
- [[_COMMUNITY_Community 113|Community 113]]
- [[_COMMUNITY_Community 114|Community 114]]
- [[_COMMUNITY_Community 115|Community 115]]
- [[_COMMUNITY_Community 116|Community 116]]
- [[_COMMUNITY_Community 117|Community 117]]
- [[_COMMUNITY_Community 118|Community 118]]
- [[_COMMUNITY_Community 119|Community 119]]
- [[_COMMUNITY_Community 120|Community 120]]
- [[_COMMUNITY_Community 121|Community 121]]
- [[_COMMUNITY_Community 122|Community 122]]
- [[_COMMUNITY_Community 123|Community 123]]
- [[_COMMUNITY_Community 124|Community 124]]
- [[_COMMUNITY_Community 125|Community 125]]
- [[_COMMUNITY_Community 126|Community 126]]
- [[_COMMUNITY_Community 127|Community 127]]
- [[_COMMUNITY_Community 128|Community 128]]
- [[_COMMUNITY_Community 129|Community 129]]
- [[_COMMUNITY_Community 130|Community 130]]
- [[_COMMUNITY_Community 131|Community 131]]
- [[_COMMUNITY_Community 132|Community 132]]
- [[_COMMUNITY_Community 133|Community 133]]
- [[_COMMUNITY_Community 134|Community 134]]
- [[_COMMUNITY_Community 135|Community 135]]
- [[_COMMUNITY_Community 136|Community 136]]
- [[_COMMUNITY_Community 137|Community 137]]
- [[_COMMUNITY_Community 138|Community 138]]
- [[_COMMUNITY_Community 139|Community 139]]
- [[_COMMUNITY_Community 140|Community 140]]
- [[_COMMUNITY_Community 141|Community 141]]
- [[_COMMUNITY_Community 142|Community 142]]
- [[_COMMUNITY_Community 143|Community 143]]
- [[_COMMUNITY_Community 144|Community 144]]
- [[_COMMUNITY_Community 145|Community 145]]
- [[_COMMUNITY_Community 146|Community 146]]
- [[_COMMUNITY_Community 147|Community 147]]
- [[_COMMUNITY_Community 148|Community 148]]
- [[_COMMUNITY_Community 149|Community 149]]
- [[_COMMUNITY_Community 150|Community 150]]
- [[_COMMUNITY_Community 151|Community 151]]
- [[_COMMUNITY_Community 152|Community 152]]
- [[_COMMUNITY_Community 153|Community 153]]
- [[_COMMUNITY_Community 154|Community 154]]
- [[_COMMUNITY_Community 155|Community 155]]
- [[_COMMUNITY_Community 156|Community 156]]
- [[_COMMUNITY_Community 157|Community 157]]
- [[_COMMUNITY_Community 158|Community 158]]
- [[_COMMUNITY_Community 159|Community 159]]
- [[_COMMUNITY_Community 160|Community 160]]
- [[_COMMUNITY_Community 161|Community 161]]
- [[_COMMUNITY_Community 162|Community 162]]
- [[_COMMUNITY_Community 163|Community 163]]
- [[_COMMUNITY_Community 164|Community 164]]
- [[_COMMUNITY_Community 165|Community 165]]
- [[_COMMUNITY_Community 166|Community 166]]
- [[_COMMUNITY_Community 167|Community 167]]
- [[_COMMUNITY_Community 168|Community 168]]
- [[_COMMUNITY_Community 169|Community 169]]
- [[_COMMUNITY_Community 170|Community 170]]
- [[_COMMUNITY_Community 171|Community 171]]
- [[_COMMUNITY_Community 172|Community 172]]
- [[_COMMUNITY_Community 173|Community 173]]
- [[_COMMUNITY_Community 174|Community 174]]
- [[_COMMUNITY_Community 175|Community 175]]
- [[_COMMUNITY_Community 176|Community 176]]
- [[_COMMUNITY_Community 177|Community 177]]
- [[_COMMUNITY_Community 178|Community 178]]
- [[_COMMUNITY_Community 179|Community 179]]
- [[_COMMUNITY_Community 180|Community 180]]
- [[_COMMUNITY_Community 181|Community 181]]
- [[_COMMUNITY_Community 182|Community 182]]
- [[_COMMUNITY_Community 183|Community 183]]
- [[_COMMUNITY_Community 184|Community 184]]
- [[_COMMUNITY_Community 185|Community 185]]
- [[_COMMUNITY_Community 186|Community 186]]
- [[_COMMUNITY_Community 187|Community 187]]
- [[_COMMUNITY_Community 188|Community 188]]
- [[_COMMUNITY_Community 189|Community 189]]
- [[_COMMUNITY_Community 190|Community 190]]
- [[_COMMUNITY_Community 191|Community 191]]
- [[_COMMUNITY_Community 192|Community 192]]
- [[_COMMUNITY_Community 193|Community 193]]
- [[_COMMUNITY_Community 194|Community 194]]
- [[_COMMUNITY_Community 195|Community 195]]
- [[_COMMUNITY_Community 196|Community 196]]
- [[_COMMUNITY_Community 197|Community 197]]
- [[_COMMUNITY_Community 198|Community 198]]
- [[_COMMUNITY_Community 199|Community 199]]
- [[_COMMUNITY_Community 200|Community 200]]
- [[_COMMUNITY_Community 201|Community 201]]
- [[_COMMUNITY_Community 202|Community 202]]
- [[_COMMUNITY_Community 203|Community 203]]
- [[_COMMUNITY_Community 204|Community 204]]
- [[_COMMUNITY_Community 205|Community 205]]
- [[_COMMUNITY_Community 206|Community 206]]
- [[_COMMUNITY_Community 207|Community 207]]
- [[_COMMUNITY_Community 208|Community 208]]
- [[_COMMUNITY_Community 209|Community 209]]
- [[_COMMUNITY_Community 210|Community 210]]
- [[_COMMUNITY_Community 211|Community 211]]
- [[_COMMUNITY_Community 212|Community 212]]
- [[_COMMUNITY_Community 213|Community 213]]
- [[_COMMUNITY_Community 214|Community 214]]
- [[_COMMUNITY_Community 215|Community 215]]
- [[_COMMUNITY_Community 216|Community 216]]
- [[_COMMUNITY_Community 217|Community 217]]
- [[_COMMUNITY_Community 218|Community 218]]
- [[_COMMUNITY_Community 219|Community 219]]
- [[_COMMUNITY_Community 220|Community 220]]
- [[_COMMUNITY_Community 221|Community 221]]
- [[_COMMUNITY_Community 222|Community 222]]
- [[_COMMUNITY_Community 223|Community 223]]
- [[_COMMUNITY_Community 224|Community 224]]
- [[_COMMUNITY_Community 225|Community 225]]
- [[_COMMUNITY_Community 226|Community 226]]
- [[_COMMUNITY_Community 227|Community 227]]
- [[_COMMUNITY_Community 228|Community 228]]
- [[_COMMUNITY_Community 229|Community 229]]
- [[_COMMUNITY_Community 230|Community 230]]
- [[_COMMUNITY_Community 231|Community 231]]
- [[_COMMUNITY_Community 232|Community 232]]
- [[_COMMUNITY_Community 233|Community 233]]
- [[_COMMUNITY_Community 234|Community 234]]
- [[_COMMUNITY_Community 235|Community 235]]
- [[_COMMUNITY_Community 236|Community 236]]
- [[_COMMUNITY_Community 237|Community 237]]
- [[_COMMUNITY_Community 238|Community 238]]
- [[_COMMUNITY_Community 239|Community 239]]
- [[_COMMUNITY_Community 240|Community 240]]
- [[_COMMUNITY_Community 241|Community 241]]
- [[_COMMUNITY_Community 242|Community 242]]
- [[_COMMUNITY_Community 243|Community 243]]
- [[_COMMUNITY_Community 244|Community 244]]
- [[_COMMUNITY_Community 245|Community 245]]
- [[_COMMUNITY_Community 246|Community 246]]
- [[_COMMUNITY_Community 247|Community 247]]
- [[_COMMUNITY_Community 248|Community 248]]
- [[_COMMUNITY_Community 249|Community 249]]
- [[_COMMUNITY_Community 250|Community 250]]
- [[_COMMUNITY_Community 251|Community 251]]
- [[_COMMUNITY_Community 252|Community 252]]
- [[_COMMUNITY_Community 253|Community 253]]
- [[_COMMUNITY_Community 254|Community 254]]
- [[_COMMUNITY_Community 255|Community 255]]
- [[_COMMUNITY_Community 256|Community 256]]
- [[_COMMUNITY_Community 257|Community 257]]
- [[_COMMUNITY_Community 258|Community 258]]
- [[_COMMUNITY_Community 259|Community 259]]
- [[_COMMUNITY_Community 260|Community 260]]
- [[_COMMUNITY_Community 261|Community 261]]
- [[_COMMUNITY_Community 262|Community 262]]
- [[_COMMUNITY_Community 263|Community 263]]
- [[_COMMUNITY_Community 264|Community 264]]
- [[_COMMUNITY_Community 265|Community 265]]
- [[_COMMUNITY_Community 266|Community 266]]
- [[_COMMUNITY_Community 267|Community 267]]
- [[_COMMUNITY_Community 268|Community 268]]
- [[_COMMUNITY_Community 269|Community 269]]
- [[_COMMUNITY_Community 270|Community 270]]
- [[_COMMUNITY_Community 271|Community 271]]
- [[_COMMUNITY_Community 272|Community 272]]
- [[_COMMUNITY_Community 273|Community 273]]
- [[_COMMUNITY_Community 274|Community 274]]
- [[_COMMUNITY_Community 275|Community 275]]
- [[_COMMUNITY_Community 276|Community 276]]
- [[_COMMUNITY_Community 277|Community 277]]
- [[_COMMUNITY_Community 278|Community 278]]
- [[_COMMUNITY_Community 279|Community 279]]
- [[_COMMUNITY_Community 280|Community 280]]
- [[_COMMUNITY_Community 281|Community 281]]
- [[_COMMUNITY_Community 282|Community 282]]
- [[_COMMUNITY_Community 283|Community 283]]
- [[_COMMUNITY_Community 284|Community 284]]
- [[_COMMUNITY_Community 285|Community 285]]
- [[_COMMUNITY_Community 286|Community 286]]
- [[_COMMUNITY_Community 287|Community 287]]
- [[_COMMUNITY_Community 288|Community 288]]
- [[_COMMUNITY_Community 289|Community 289]]
- [[_COMMUNITY_Community 290|Community 290]]
- [[_COMMUNITY_Community 291|Community 291]]
- [[_COMMUNITY_Community 292|Community 292]]
- [[_COMMUNITY_Community 293|Community 293]]
- [[_COMMUNITY_Community 294|Community 294]]
- [[_COMMUNITY_Community 295|Community 295]]
- [[_COMMUNITY_Community 296|Community 296]]
- [[_COMMUNITY_Community 297|Community 297]]
- [[_COMMUNITY_Community 298|Community 298]]
- [[_COMMUNITY_Community 299|Community 299]]
- [[_COMMUNITY_Community 300|Community 300]]
- [[_COMMUNITY_Community 301|Community 301]]
- [[_COMMUNITY_Community 302|Community 302]]
- [[_COMMUNITY_Community 303|Community 303]]
- [[_COMMUNITY_Community 304|Community 304]]
- [[_COMMUNITY_Community 305|Community 305]]
- [[_COMMUNITY_Community 306|Community 306]]
- [[_COMMUNITY_Community 307|Community 307]]
- [[_COMMUNITY_Community 308|Community 308]]
- [[_COMMUNITY_Community 309|Community 309]]
- [[_COMMUNITY_Community 310|Community 310]]
- [[_COMMUNITY_Community 311|Community 311]]

## God Nodes (most connected - your core abstractions)
1. `ESP32Comm` - 133 edges
2. `HomeAssistantAPI` - 129 edges
3. `KV` - 70 edges
4. `onMsg()` - 38 edges
5. `main()` - 33 edges
6. `loop()` - 28 edges
7. `OTAManager` - 27 edges
8. `DayNightHandler` - 27 edges
9. `RF433Config` - 26 edges
10. `StatusHandler` - 25 edges

## Surprising Connections (you probably didn't know these)
- `HABoxSensor` --shares_data_with--> `BME280 environmental sensor (temp/humidity/pressure on ESP32 I2C)`  [INFERRED]
  ha-integration/custom_components/ha_box/sensor.py → README.md
- `PowerButton()` --conceptually_related_to--> `UART communication Pi <-> ESP32 (AsciiProto)`  [INFERRED]
  ha-box-esp/src/PowerButton.h → ha-box-esp-fw/ESPHOMEASSISTANT/ARCHITECTURE.md
- `EVENT_SENSORS = ha_box_sensors (tC, hum, pPa)` --rationale_for--> `UART communication protocol (Pi add-on <-> ESP32, ASCII line-based)`  [INFERRED]
  ha-integration/custom_components/ha_box/const.py → README.md
- `EVENT_MODE = ha_box_mode_changed (day|night)` --rationale_for--> `UART communication protocol (Pi add-on <-> ESP32, ASCII line-based)`  [INFERRED]
  ha-integration/custom_components/ha_box/const.py → README.md
- `FT6336U Touch Controller Datasheet` --references--> `FT6336U capacitive touch controller (I2C 0x38)`  [INFERRED]
  hardware/datasheet/epapper-screen/FT6336U-DataSheet-V1.0.pdf → docs/HARDWARE.md

## Hyperedges (group relationships)
- **Periodic handler pattern: ESP32Comm + threading.Timer + ConnectionManager** — weather_handler_weatherhandler, clock_handler_clockhandler, status_handler_statushandler [INFERRED 0.90]
- **ESP32 ASCII protocol core: ESP32Comm + Message + KV** — esp32_comm_esp32comm, esp32_comm_message, esp32_comm_kv [EXTRACTED 1.00]
- **OTA firmware update flow: OTAManager + ESP32Comm + MessageHandler** — ota_manager_otamanager, esp32_comm_esp32comm, message_handler_messagehandler [INFERRED 0.85]
- **Wireless Connectivity Protocol Icons** —  [INFERRED 0.90]
- **Wired/Network Connectivity Icons** —  [INFERRED 0.80]
- **Smart Home Protocol Icons** —  [INFERRED 0.85]
- **UI Control/Navigation Icons** —  [INFERRED 0.90]
- **Power/State Off Icons** —  [INFERRED 0.85]
- **Weather Icon Set** — icon_weather_snowy_rainy, icon_weather_fog, icon_weather_thunder, icon_weather_alert, icon_weather_pouring, icon_weather_day_cloudy, icon_weather_thunder_rain, icon_weather_wind, icon_weather_snowy, icon_weather_moon, icon_weather_sunny, icon_weather_home_temp, icon_weather_cloud, icon_weather_na, icon_weather_hail, icon_weather_humidity, icon_weather_wind_cloudy, icon_weather_rain [EXTRACTED 1.00]
- **Connectivity Protocol Icons** — icon_global_wifi, icon_global_wifi_stop, icon_global_bluetooth, icon_global_bluetooth_stop, icon_global_zigbee, icon_global_z_wave, icon_global_matter, icon_global_thread_net, icon_global_nfc, icon_global_lan, icon_global_infrared, icon_global_433_on, icon_global_433_off [EXTRACTED 1.00]
- **UI Control Icons** — icon_global_add, icon_global_minus, icon_global_arrow_back, icon_global_arrow_back_rounded, icon_global_arrow_forward, icon_global_lets_icons_up, icon_global_settings, icon_global_day_mode, icon_global_night_mode, icon_global_volume_up, icon_global_volume_off, icon_global_timer_sand_up, icon_global_timer_sand_mid, icon_global_sand_complete, icon_global_power_plug_off, icon_global_power_plug_off_72, icon_global_light_off, icon_global_update, icon_global_web [EXTRACTED 1.00]

## Communities

### Community 0 - "Community 0"
Cohesion: 0.02
Nodes (159): Count warnings and errors from Repair Issues + Persistent Notifications.      -, ClockHandler, Clock handler for ESP32.  This module handles sending current time to the ESP32., Send current time to ESP32.                  Returns:             True if update, Update clock (legacy method, kept for compatibility).                  Args:, Handler for clock updates to ESP32., Initialize clock handler.                  Args:             esp32_comm: ESP32 c, Check if clock should be updated.                  Args:             current_tim (+151 more)

### Community 1 - "Community 1"
Cohesion: 0.05
Nodes (79): HA Box AppArmor Profile, Bill of Materials – HA Box V0.1, HA Box Add-on CHANGELOG, CM5 IO Board BOM (KiCad v9), 3D-printed enclosure (PLA/PETG, Fusion 360, FDM parts), AppArmor security profile (restricts container to hardware devices only), Blind OTA recovery (flash without VERSION handshake on >= 3 ROM boot errors), BME280 environmental sensor (temp/humidity/pressure, I2C) (+71 more)

### Community 2 - "Community 2"
Cohesion: 0.06
Nodes (55): begin(), FanController(), mapDuty(), safeMode(), setCurve(), setDuty(), setEnabled(), stop() (+47 more)

### Community 3 - "Community 3"
Cohesion: 0.05
Nodes (56): AsciiProto(), autoAckForMessage(), copyToken(), isDuplicateIncoming(), nextId(), parseAck(), parseMessage(), poll() (+48 more)

### Community 4 - "Community 4"
Cohesion: 0.07
Nodes (29): CC1101 433MHz module configuration (SPI on Pi, RFLink TCP server)., RF433Config, Stop the communication handler.          Closes the serial port and stops the po, Get active persistent notifications via the HA WebSocket API.          In HA 202, _CC1101, _is_noise(), RF433 handler — RFLink-compatible TCP server backed by CC1101 (SPI on Pi).  The, Write register configuration and PA table. (+21 more)

### Community 5 - "Community 5"
Cohesion: 0.06
Nodes (25): _check_url_reachable(), _duckdns_url(), fetch_addons(), _is_tunnel_slug(), Status fetcher: add-ons list (exposed on internet: DuckDNS, Cloudflare tunnel, e, Return True for add-ons that act as tunnel proxies (Cloudflare tunnel variants)., Return True if url responds with 2xx or 3xx (e.g. HA login page or API)., Build DuckDNS URL from add-on options["domains"]. (+17 more)

### Community 6 - "Community 6"
Cohesion: 0.06
Nodes (20): ConnectionManager, ConnectionState, Connection state manager for ESP32 communication.  This module manages the conne, Connection state with ESP32., Manages ESP32 connection state and periodic messaging., Initialize connection manager.                  Args:             esp32_comm: ES, Update connection state based on last message time.                  Args:, Enum (+12 more)

### Community 7 - "Community 7"
Cohesion: 0.07
Nodes (26): fetch_alerts(), Status fetcher: HA warnings and critical errors. Aggregates Repair Issues (sever, Count warnings and errors from Supervisor unhealthy states + Persistent Notifica, UART communication Pi <-> ESP32 (AsciiProto), Get critical system states from the Supervisor Resolution Center (GET /resolutio, get_all_status(), Run all status fetchers and merge into a single status dict.     GET /addons is, onRawLine() (+18 more)

### Community 8 - "Community 8"
Cohesion: 0.07
Nodes (24): _esp32_lang_id(), handle_esp32_ack(), ESP32 lang id: 0 = French, 1 = English., ESP32 lang id: 0 = French, 1 = English., ESP32 lang id: 0 = French, 1 = English., Initialization phase: wait for ESP32 connection.      Actively tries to establis, Initialization phase: wait for ESP32 connection.      Actively tries to establis, Handle ACK from ESP32.      Args:         ack: ACK received from ESP32. (+16 more)

### Community 9 - "Community 9"
Cohesion: 0.1
Nodes (26): BME280Config, _box_options_from_legacy(), BoxConfig, ClockConfig, Config, ConnectionConfig, DayNightConfig, FanConfig (+18 more)

### Community 10 - "Community 10"
Cohesion: 0.1
Nodes (26): HA-Box 3D Render - Front Panel with E-Ink Display, HA Box Action Button Labels on Panel, HA Box Black Frame / Bezel, HA Box Design Language — Wood + Black + Epaper, HA Box Physical Enclosure, HA Box Enclosure Form Factor, HA Box E-Paper Display Panel, HA-Box Front Status Display (E-Ink / LCD) (+18 more)

### Community 11 - "Community 11"
Cohesion: 0.09
Nodes (5): drawDegreeSymbol(), drawFull(), setFont(), OnboardingWidget(), Kind()

### Community 12 - "Community 12"
Cohesion: 0.16
Nodes (19): ESP32 E-Paper Weather Widget, Weather Alert Icon, Cloudy Weather Icon, Partly Cloudy Day Weather Icon, Fog Weather Icon, Hail Weather Icon, Home Temperature Icon, Humidity Weather Icon (+11 more)

### Community 13 - "Community 13"
Cohesion: 0.15
Nodes (16): Black Aluminum/Plastic Frame, E-Ink or LCD Display (Status Screen), Display Status Text: Etat TOUT OK, Display Label: MAISON, Display Button: MODE JOUR, Display Icon: Moon/Night Mode (Nuit - Mode Nuit), Display Icon: Lock/Security (Securite - Maison Securisee), Display Button: TOUT ETEINDRE (+8 more)

### Community 14 - "Community 14"
Cohesion: 0.19
Nodes (8): BME280 environmental sensor (temp/humidity/pressure on ESP32 I2C), async_setup_entry(), HABoxDayModeSensor, HABoxSensor, Sensor platform for HA Box integration., Sensor showing current day/night mode as text., A sensor entity updated by HA Box addon events., SensorEntity

### Community 15 - "Community 15"
Cohesion: 0.22
Nodes (13): Crystal Oscillator / Resonator, ESP PCB Front Side - HA Box v0.1, Left-side GPIO Pin Header (2-row), Right-side GPIO Pin Header (2-row), HA Box ESP32 Hardware Project, SMD IC - Top Right Area, Toroidal Inductor / Ferrite Component, Yellow FR4 PCB Substrate (+5 more)

### Community 16 - "Community 16"
Cohesion: 0.24
Nodes (13): Icon Color Palette, ha-box Addon Icon, Cartoon / Illustrated Icon Style, Desktop Tower PC, Case Fan / Ventilation Grill, Gear / Cog Background, LED Status Indicators, Power Button (+5 more)

### Community 17 - "Community 17"
Cohesion: 0.18
Nodes (12): GDEY037T03-FT21 3.7" E-paper Display Module, GDEY037T03-FT21 Electrical Characteristics, GDEY037T03-FT21 Key Features, GDEY037T03-FT21 Front-light, GDEY037T03-FT21 SPI Interface, GDEY037T03-FT21 Mechanical Specifications, GDEY037T03-FT21 Optical Specifications, GDEY037T03-FT21 Display Resolution 240x416 (+4 more)

### Community 18 - "Community 18"
Cohesion: 0.23
Nodes (12): Medium Blue, Dark Navy / Near-Black, Green, Light Blue, Red, ha-box Logo, Circuit Board Pattern, Gear/Cog Symbol (+4 more)

### Community 19 - "Community 19"
Cohesion: 0.25
Nodes (11): ESP PCB Back Side Photo, PCB Board Outline, Copper Traces Right Side, Copper Traces Top Region, Mounting Hole Bottom-Right, Mounting Hole Top-Left, Pad Row Left Edge, Pad Row Right Edge (+3 more)

### Community 20 - "Community 20"
Cohesion: 0.22
Nodes (10): Black Accent Strip (top edge), Dark Label Block (product info / warning text block), HA-Box Physical Enclosure 3D Render, HA-Box Right Side Panel, Power Button (circular, front-right panel), Status Indicator Icons with Labels (moon/sleep, wifi, lock icons visible), Status / Label Panel with Text Indicators, Top Slot / Opening (ventilation or card slot) (+2 more)

### Community 21 - "Community 21"
Cohesion: 0.29
Nodes (10): Custom PCB (Right Side), GPIO Header / Edge Connector, HA Box Enclosure (Interior), HA Box Interior 3D Render, Internal Mounting Base / Tray, Rear Panel Connectors, Single Board Computer (SBC), Screw Terminal Blocks (+2 more)

### Community 22 - "Community 22"
Cohesion: 0.36
Nodes (10): GPIO / Edge Connector Pin Header, Green Indicator / Component, HA Box Enclosure (Black), HA Box Internal 3D Render (View 1), HA Box Internal 3D Render (View 2), Internal White Diffuser or Mounting Panel, Main PCB (White, Raspberry Pi-like), SD Card Slot (+2 more)

### Community 23 - "Community 23"
Cohesion: 0.25
Nodes (0): 

### Community 24 - "Community 24"
Cohesion: 0.36
Nodes (8): HA-Box Concept Design Image (Jan 2026), Home Appliance Aesthetic Design Concept, Dual Color Variants: Black and White/Silver, Ambient LED Light Strip, Front Power Button, Front Status Display Panel, Vertical Tower Form Factor, Monitored Metrics: CPU, BOX, Fan, Power

### Community 25 - "Community 25"
Cohesion: 0.29
Nodes (0): 

### Community 26 - "Community 26"
Cohesion: 0.29
Nodes (0): 

### Community 27 - "Community 27"
Cohesion: 0.29
Nodes (0): 

### Community 28 - "Community 28"
Cohesion: 0.33
Nodes (1): TMP102()

### Community 29 - "Community 29"
Cohesion: 0.33
Nodes (6): HA-Box UI Concept (Flipped) - January 2026, UI Mode: Absence (Away Mode), UI Mode: Mode Nuit (Night Mode), UI Mode: Tout Eteindre (Turn Everything Off), Monochrome Panel Layout Design, UI Status Display Area

### Community 30 - "Community 30"
Cohesion: 0.4
Nodes (5): ChatGPT Concept Image – ha-box UI Dashboard (Jan 2026), Quick-Action Buttons – Mode Jour / Tout Éteindre / Urgence, Current Mode Indicator – Nuit (Night Mode), Security Status – Maison Sécurisée, Status Display – TOUT OK / System Health

### Community 31 - "Community 31"
Cohesion: 0.5
Nodes (0): 

### Community 32 - "Community 32"
Cohesion: 0.5
Nodes (0): 

### Community 33 - "Community 33"
Cohesion: 0.5
Nodes (3): Logging configuration for HA Box., Setup logging configuration.          Args:         level: Logging level (defaul, setup_logging()

### Community 34 - "Community 34"
Cohesion: 0.5
Nodes (2): Initialize ESP32 communication handler.          Args:             device: Seria, Auto-detect serial device.          Returns:             Device path, or raises

### Community 35 - "Community 35"
Cohesion: 0.5
Nodes (4): EVENT_MODE = ha_box_mode_changed (day|night), EVENT_SENSORS = ha_box_sensors (tC, hum, pPa), UART communication protocol (Pi add-on <-> ESP32, ASCII line-based), Testing workflow: deploy to HAOS via Samba/SSH, no local testing

### Community 36 - "Community 36"
Cohesion: 0.5
Nodes (4): Arrow Back Icon (left-pointing chevron), Arrow Back Rounded Icon (left arrow with rounded style), Arrow Forward Icon (right-pointing chevron), Up Arrow Icon (upward-pointing arrow, rounded)

### Community 37 - "Community 37"
Cohesion: 0.67
Nodes (0): 

### Community 38 - "Community 38"
Cohesion: 0.67
Nodes (0): 

### Community 39 - "Community 39"
Cohesion: 0.67
Nodes (0): 

### Community 40 - "Community 40"
Cohesion: 0.67
Nodes (0): 

### Community 41 - "Community 41"
Cohesion: 0.67
Nodes (0): 

### Community 42 - "Community 42"
Cohesion: 0.67
Nodes (0): 

### Community 43 - "Community 43"
Cohesion: 0.67
Nodes (0): 

### Community 44 - "Community 44"
Cohesion: 1.0
Nodes (3): Sand Complete Icon (hourglass fully elapsed), Timer Sand Mid Icon (hourglass mid-flow, sand in both halves), Timer Sand Up Icon (hourglass, sand at top)

### Community 45 - "Community 45"
Cohesion: 0.67
Nodes (3): 433MHz RF Off Icon (radio wave signal inactive/disabled), 433MHz RF On Icon (radio wave signal active), Infrared Icon (IR signal wave arcs)

### Community 46 - "Community 46"
Cohesion: 1.0
Nodes (0): 

### Community 47 - "Community 47"
Cohesion: 1.0
Nodes (0): 

### Community 48 - "Community 48"
Cohesion: 1.0
Nodes (0): 

### Community 49 - "Community 49"
Cohesion: 1.0
Nodes (0): 

### Community 50 - "Community 50"
Cohesion: 1.0
Nodes (2): get_translator() — global translator singleton, Translator — i18n translation manager

### Community 51 - "Community 51"
Cohesion: 1.0
Nodes (2): HABoxConfigFlow (single-instance config entry, no options), DOMAIN constant = ha_box

### Community 52 - "Community 52"
Cohesion: 1.0
Nodes (2): E-paper display 240x416 UC8253, Full refresh (~2s) vs partial refresh (~300ms) on e-paper

### Community 53 - "Community 53"
Cohesion: 1.0
Nodes (2): Git workflow: main (stable), develop (active), feature/* fix/* docs/*, HA Box project overview (4-layer architecture: hardware/enclosure/esp32fw/ha-addon)

### Community 54 - "Community 54"
Cohesion: 1.0
Nodes (2): WiFi Icon (wireless signal arcs), WiFi Stop Icon (WiFi signal with slash/disabled)

### Community 55 - "Community 55"
Cohesion: 1.0
Nodes (2): Bluetooth Icon (standard Bluetooth symbol), Bluetooth Stop Icon (Bluetooth symbol with slash/X)

### Community 56 - "Community 56"
Cohesion: 1.0
Nodes (2): Volume Off Icon (muted speaker with slash), Volume Up Icon (speaker with sound waves)

### Community 57 - "Community 57"
Cohesion: 1.0
Nodes (2): Power Plug Off Icon (plug with slash, small), Power Plug Off Icon 72px (larger plug with slash)

### Community 58 - "Community 58"
Cohesion: 1.0
Nodes (2): Z-Wave Icon (Z letter with wave), Zigbee Icon (Z letter in circle)

### Community 59 - "Community 59"
Cohesion: 1.0
Nodes (2): Add Icon (plus sign), Minus Icon (horizontal dash/subtract)

### Community 60 - "Community 60"
Cohesion: 1.0
Nodes (2): Day Mode Icon (sun with radiating rays), Night Mode Icon (crescent moon)

### Community 61 - "Community 61"
Cohesion: 1.0
Nodes (0): 

### Community 62 - "Community 62"
Cohesion: 1.0
Nodes (0): 

### Community 63 - "Community 63"
Cohesion: 1.0
Nodes (0): 

### Community 64 - "Community 64"
Cohesion: 1.0
Nodes (0): 

### Community 65 - "Community 65"
Cohesion: 1.0
Nodes (0): 

### Community 66 - "Community 66"
Cohesion: 1.0
Nodes (0): 

### Community 67 - "Community 67"
Cohesion: 1.0
Nodes (0): 

### Community 68 - "Community 68"
Cohesion: 1.0
Nodes (0): 

### Community 69 - "Community 69"
Cohesion: 1.0
Nodes (0): 

### Community 70 - "Community 70"
Cohesion: 1.0
Nodes (0): 

### Community 71 - "Community 71"
Cohesion: 1.0
Nodes (0): 

### Community 72 - "Community 72"
Cohesion: 1.0
Nodes (0): 

### Community 73 - "Community 73"
Cohesion: 1.0
Nodes (0): 

### Community 74 - "Community 74"
Cohesion: 1.0
Nodes (0): 

### Community 75 - "Community 75"
Cohesion: 1.0
Nodes (0): 

### Community 76 - "Community 76"
Cohesion: 1.0
Nodes (0): 

### Community 77 - "Community 77"
Cohesion: 1.0
Nodes (0): 

### Community 78 - "Community 78"
Cohesion: 1.0
Nodes (0): 

### Community 79 - "Community 79"
Cohesion: 1.0
Nodes (0): 

### Community 80 - "Community 80"
Cohesion: 1.0
Nodes (0): 

### Community 81 - "Community 81"
Cohesion: 1.0
Nodes (0): 

### Community 82 - "Community 82"
Cohesion: 1.0
Nodes (0): 

### Community 83 - "Community 83"
Cohesion: 1.0
Nodes (0): 

### Community 84 - "Community 84"
Cohesion: 1.0
Nodes (0): 

### Community 85 - "Community 85"
Cohesion: 1.0
Nodes (0): 

### Community 86 - "Community 86"
Cohesion: 1.0
Nodes (0): 

### Community 87 - "Community 87"
Cohesion: 1.0
Nodes (0): 

### Community 88 - "Community 88"
Cohesion: 1.0
Nodes (0): 

### Community 89 - "Community 89"
Cohesion: 1.0
Nodes (0): 

### Community 90 - "Community 90"
Cohesion: 1.0
Nodes (0): 

### Community 91 - "Community 91"
Cohesion: 1.0
Nodes (0): 

### Community 92 - "Community 92"
Cohesion: 1.0
Nodes (0): 

### Community 93 - "Community 93"
Cohesion: 1.0
Nodes (0): 

### Community 94 - "Community 94"
Cohesion: 1.0
Nodes (0): 

### Community 95 - "Community 95"
Cohesion: 1.0
Nodes (0): 

### Community 96 - "Community 96"
Cohesion: 1.0
Nodes (0): 

### Community 97 - "Community 97"
Cohesion: 1.0
Nodes (0): 

### Community 98 - "Community 98"
Cohesion: 1.0
Nodes (0): 

### Community 99 - "Community 99"
Cohesion: 1.0
Nodes (0): 

### Community 100 - "Community 100"
Cohesion: 1.0
Nodes (0): 

### Community 101 - "Community 101"
Cohesion: 1.0
Nodes (0): 

### Community 102 - "Community 102"
Cohesion: 1.0
Nodes (0): 

### Community 103 - "Community 103"
Cohesion: 1.0
Nodes (0): 

### Community 104 - "Community 104"
Cohesion: 1.0
Nodes (0): 

### Community 105 - "Community 105"
Cohesion: 1.0
Nodes (0): 

### Community 106 - "Community 106"
Cohesion: 1.0
Nodes (0): 

### Community 107 - "Community 107"
Cohesion: 1.0
Nodes (0): 

### Community 108 - "Community 108"
Cohesion: 1.0
Nodes (0): 

### Community 109 - "Community 109"
Cohesion: 1.0
Nodes (0): 

### Community 110 - "Community 110"
Cohesion: 1.0
Nodes (0): 

### Community 111 - "Community 111"
Cohesion: 1.0
Nodes (0): 

### Community 112 - "Community 112"
Cohesion: 1.0
Nodes (0): 

### Community 113 - "Community 113"
Cohesion: 1.0
Nodes (0): 

### Community 114 - "Community 114"
Cohesion: 1.0
Nodes (0): 

### Community 115 - "Community 115"
Cohesion: 1.0
Nodes (0): 

### Community 116 - "Community 116"
Cohesion: 1.0
Nodes (0): 

### Community 117 - "Community 117"
Cohesion: 1.0
Nodes (0): 

### Community 118 - "Community 118"
Cohesion: 1.0
Nodes (0): 

### Community 119 - "Community 119"
Cohesion: 1.0
Nodes (0): 

### Community 120 - "Community 120"
Cohesion: 1.0
Nodes (0): 

### Community 121 - "Community 121"
Cohesion: 1.0
Nodes (0): 

### Community 122 - "Community 122"
Cohesion: 1.0
Nodes (0): 

### Community 123 - "Community 123"
Cohesion: 1.0
Nodes (0): 

### Community 124 - "Community 124"
Cohesion: 1.0
Nodes (0): 

### Community 125 - "Community 125"
Cohesion: 1.0
Nodes (0): 

### Community 126 - "Community 126"
Cohesion: 1.0
Nodes (0): 

### Community 127 - "Community 127"
Cohesion: 1.0
Nodes (0): 

### Community 128 - "Community 128"
Cohesion: 1.0
Nodes (0): 

### Community 129 - "Community 129"
Cohesion: 1.0
Nodes (0): 

### Community 130 - "Community 130"
Cohesion: 1.0
Nodes (0): 

### Community 131 - "Community 131"
Cohesion: 1.0
Nodes (0): 

### Community 132 - "Community 132"
Cohesion: 1.0
Nodes (0): 

### Community 133 - "Community 133"
Cohesion: 1.0
Nodes (0): 

### Community 134 - "Community 134"
Cohesion: 1.0
Nodes (0): 

### Community 135 - "Community 135"
Cohesion: 1.0
Nodes (0): 

### Community 136 - "Community 136"
Cohesion: 1.0
Nodes (0): 

### Community 137 - "Community 137"
Cohesion: 1.0
Nodes (0): 

### Community 138 - "Community 138"
Cohesion: 1.0
Nodes (0): 

### Community 139 - "Community 139"
Cohesion: 1.0
Nodes (0): 

### Community 140 - "Community 140"
Cohesion: 1.0
Nodes (1): True if both GPIO pins are configured.

### Community 141 - "Community 141"
Cohesion: 1.0
Nodes (1): Create Config from Home Assistant options.

### Community 142 - "Community 142"
Cohesion: 1.0
Nodes (1): EVENT_CASE_TEMP = ha_box_case_temp (tC)

### Community 143 - "Community 143"
Cohesion: 1.0
Nodes (1): Key-value pair for message parameters.

### Community 144 - "Community 144"
Cohesion: 1.0
Nodes (1): Get a value by key.          Args:             key: Key to look up.

### Community 145 - "Community 145"
Cohesion: 1.0
Nodes (1): ACK response from ESP32.

### Community 146 - "Community 146"
Cohesion: 1.0
Nodes (1): Initialize ESP32 communication handler.          Args:             device: Seria

### Community 147 - "Community 147"
Cohesion: 1.0
Nodes (1): Auto-detect serial device.          Returns:             Device path, or raises

### Community 148 - "Community 148"
Cohesion: 1.0
Nodes (1): Start the communication handler.          Opens the serial port and starts the p

### Community 149 - "Community 149"
Cohesion: 1.0
Nodes (1): Stop the communication handler.          Closes the serial port and stops the po

### Community 150 - "Community 150"
Cohesion: 1.0
Nodes (1): Reset the boot failure counter (call after a successful OTA or connection).

### Community 151 - "Community 151"
Cohesion: 1.0
Nodes (1): Return the current boot failure counter value.

### Community 152 - "Community 152"
Cohesion: 1.0
Nodes (1): Check if we have ever received a message from ESP32.                  Returns:

### Community 153 - "Community 153"
Cohesion: 1.0
Nodes (1): Set callback for message authorization.          Args:             callback: Fun

### Community 154 - "Community 154"
Cohesion: 1.0
Nodes (1): Set callback for incoming messages.          Args:             callback: Functio

### Community 155 - "Community 155"
Cohesion: 1.0
Nodes (1): Set callback for incoming ACKs.          Args:             callback: Function th

### Community 156 - "Community 156"
Cohesion: 1.0
Nodes (1): Get next message ID.          Returns:             Next unique message ID.

### Community 157 - "Community 157"
Cohesion: 1.0
Nodes (1): Send a command to ESP32.          Args:             verb: Command verb (e.g., "R

### Community 158 - "Community 158"
Cohesion: 1.0
Nodes (1): Send a command and wait for ACK (synchronous, blocking).          Args:

### Community 159 - "Community 159"
Cohesion: 1.0
Nodes (1): Send ACK OK for a message.          Args:             msg_id: Message ID to ackn

### Community 160 - "Community 160"
Cohesion: 1.0
Nodes (1): Send ACK ERR for a message.          Args:             msg_id: Message ID to ack

### Community 161 - "Community 161"
Cohesion: 1.0
Nodes (1): Main polling loop (runs in background thread).

### Community 162 - "Community 162"
Cohesion: 1.0
Nodes (1): Process incoming serial data.          Args:             data: Raw bytes from se

### Community 163 - "Community 163"
Cohesion: 1.0
Nodes (1): Process a complete line.          Args:             line: Complete line string (

### Community 164 - "Community 164"
Cohesion: 1.0
Nodes (1): Parse an ACK line.          Format: "ACK <id> OK" or "ACK <id> ERR <code>"

### Community 165 - "Community 165"
Cohesion: 1.0
Nodes (1): Parse a message line.          Format: "<id> <VERB> [key=value]..."          Arg

### Community 166 - "Community 166"
Cohesion: 1.0
Nodes (1): Automatically send ACK for a message (with authorization check).          Args:

### Community 167 - "Community 167"
Cohesion: 1.0
Nodes (1): Check if message ID is a duplicate.          Args:             msg_id: Message I

### Community 168 - "Community 168"
Cohesion: 1.0
Nodes (1): Remember a message ID for deduplication.          Args:             msg_id: Mess

### Community 169 - "Community 169"
Cohesion: 1.0
Nodes (1): Main configuration class.

### Community 170 - "Community 170"
Cohesion: 1.0
Nodes (1): Create Config from Home Assistant options.

### Community 171 - "Community 171"
Cohesion: 1.0
Nodes (1): Update a sensor state in Home Assistant.                  Args:             enti

### Community 172 - "Community 172"
Cohesion: 1.0
Nodes (1): Get the state of an entity from Home Assistant.                  Args:

### Community 173 - "Community 173"
Cohesion: 1.0
Nodes (1): Set the state of an entity via the Core API (POST /core/api/states/<entity_id>).

### Community 174 - "Community 174"
Cohesion: 1.0
Nodes (1): Get all config entries from Home Assistant Core.         GET /core/api/config/co

### Community 175 - "Community 175"
Cohesion: 1.0
Nodes (1): Get all entity states from Home Assistant Core (GET /core/api/states).         U

### Community 176 - "Community 176"
Cohesion: 1.0
Nodes (1): Get weather data from Home Assistant.                  Args:             entity_

### Community 177 - "Community 177"
Cohesion: 1.0
Nodes (1): Fire ha_box_sensors event with BME280 data.          Args:             temperatu

### Community 178 - "Community 178"
Cohesion: 1.0
Nodes (1): Fire ha_box_case_temp event with TMP102 case temperature.          Args:

### Community 179 - "Community 179"
Cohesion: 1.0
Nodes (1): Get Supervisor info from the Supervisor API (no Core dependency).          Retur

### Community 180 - "Community 180"
Cohesion: 1.0
Nodes (1): Get network interfaces from the Supervisor API.          Returns:             Re

### Community 181 - "Community 181"
Cohesion: 1.0
Nodes (1): Get list of add-ons from the Supervisor API.         Response shape may be {"dat

### Community 182 - "Community 182"
Cohesion: 1.0
Nodes (1): Get add-on info (including options) from Supervisor API.         GET /addons/<sl

### Community 183 - "Community 183"
Cohesion: 1.0
Nodes (1): Get critical system states from the Supervisor Resolution Center (GET /resolutio

### Community 184 - "Community 184"
Cohesion: 1.0
Nodes (1): Get active persistent notifications via the HA WebSocket API.          In HA 202

### Community 185 - "Community 185"
Cohesion: 1.0
Nodes (1): Aggregate system status for the STATUS message to ESP32.         Does not requir

### Community 186 - "Community 186"
Cohesion: 1.0
Nodes (1): Fire a Home Assistant event via the Core API (POST /core/api/events/<event_type>

### Community 187 - "Community 187"
Cohesion: 1.0
Nodes (1): No-op: day/night state is handled by the ha_box_mode_changed event         consu

### Community 188 - "Community 188"
Cohesion: 1.0
Nodes (1): Call Home Assistant service light.turn_off with entity_id "all"         to turn

### Community 189 - "Community 189"
Cohesion: 1.0
Nodes (1): True if both GPIO pins are configured.

### Community 190 - "Community 190"
Cohesion: 1.0
Nodes (1): Day/night mode synchronisation configuration.

### Community 191 - "Community 191"
Cohesion: 1.0
Nodes (1): Clock synchronisation configuration.

### Community 192 - "Community 192"
Cohesion: 1.0
Nodes (1): Status handler configuration.

### Community 193 - "Community 193"
Cohesion: 1.0
Nodes (1): UART serial configuration.

### Community 194 - "Community 194"
Cohesion: 1.0
Nodes (1): ESP32 connection state-machine timeouts.

### Community 195 - "Community 195"
Cohesion: 1.0
Nodes (1): CC1101 433MHz module configuration (SPI on Pi, RFLink TCP server).

### Community 196 - "Community 196"
Cohesion: 1.0
Nodes (1): Box / ESP32 stack: language, weather, sensors, fan, OTA.

### Community 197 - "Community 197"
Cohesion: 1.0
Nodes (1): Main configuration class.

### Community 198 - "Community 198"
Cohesion: 1.0
Nodes (1): Create Config from Home Assistant options.

### Community 199 - "Community 199"
Cohesion: 1.0
Nodes (1): Client for Home Assistant Supervisor API.

### Community 200 - "Community 200"
Cohesion: 1.0
Nodes (1): Initialize Home Assistant API client.

### Community 201 - "Community 201"
Cohesion: 1.0
Nodes (1): Check if Home Assistant Core is available.                  Returns:

### Community 202 - "Community 202"
Cohesion: 1.0
Nodes (1): Get Home Assistant Core configuration (GET /core/api/config).         Contains l

### Community 203 - "Community 203"
Cohesion: 1.0
Nodes (1): Get the default language from Home Assistant Core config.         This is the la

### Community 204 - "Community 204"
Cohesion: 1.0
Nodes (1): Request host shutdown via Supervisor API (POST /host/shutdown).         Used whe

### Community 205 - "Community 205"
Cohesion: 1.0
Nodes (1): Make a request to Home Assistant Supervisor API.                  Args:

### Community 206 - "Community 206"
Cohesion: 1.0
Nodes (1): Update a sensor state in Home Assistant.                  Args:             enti

### Community 207 - "Community 207"
Cohesion: 1.0
Nodes (1): Get the state of an entity from Home Assistant.                  Args:

### Community 208 - "Community 208"
Cohesion: 1.0
Nodes (1): Set the state of an entity via the Core API (POST /core/api/states/<entity_id>).

### Community 209 - "Community 209"
Cohesion: 1.0
Nodes (1): Get all config entries from Home Assistant Core.         GET /core/api/config/co

### Community 210 - "Community 210"
Cohesion: 1.0
Nodes (1): Get all entity states from Home Assistant Core (GET /core/api/states).         U

### Community 211 - "Community 211"
Cohesion: 1.0
Nodes (1): Get weather data from Home Assistant.                  Args:             entity_

### Community 212 - "Community 212"
Cohesion: 1.0
Nodes (1): Fire ha_box_sensors event with BME280 data.          Args:             temperatu

### Community 213 - "Community 213"
Cohesion: 1.0
Nodes (1): Fire ha_box_case_temp event with TMP102 case temperature.          Args:

### Community 214 - "Community 214"
Cohesion: 1.0
Nodes (1): Get Supervisor info from the Supervisor API (no Core dependency).          Retur

### Community 215 - "Community 215"
Cohesion: 1.0
Nodes (1): Get network interfaces from the Supervisor API.          Returns:             Re

### Community 216 - "Community 216"
Cohesion: 1.0
Nodes (1): Get list of add-ons from the Supervisor API.         Response shape may be {"dat

### Community 217 - "Community 217"
Cohesion: 1.0
Nodes (1): Get add-on info (including options) from Supervisor API.         GET /addons/<sl

### Community 218 - "Community 218"
Cohesion: 1.0
Nodes (1): Get repair issues from Home Assistant Core (GET /core/api/repairs/issues).

### Community 219 - "Community 219"
Cohesion: 1.0
Nodes (1): Get persistent notifications from Home Assistant Core         (GET /core/api/per

### Community 220 - "Community 220"
Cohesion: 1.0
Nodes (1): Aggregate system status for the STATUS message to ESP32.         Does not requir

### Community 221 - "Community 221"
Cohesion: 1.0
Nodes (1): Fire a Home Assistant event via the Core API (POST /core/api/events/<event_type>

### Community 222 - "Community 222"
Cohesion: 1.0
Nodes (1): No-op: day/night state is handled by the ha_box_mode_changed event         consu

### Community 223 - "Community 223"
Cohesion: 1.0
Nodes (1): Call Home Assistant service light.turn_off with entity_id "all"         to turn

### Community 224 - "Community 224"
Cohesion: 1.0
Nodes (1): Weather entity and polling (data sent to ESP32 display).

### Community 225 - "Community 225"
Cohesion: 1.0
Nodes (1): BME280 sensor configuration.

### Community 226 - "Community 226"
Cohesion: 1.0
Nodes (1): NFC sensor configuration.

### Community 227 - "Community 227"
Cohesion: 1.0
Nodes (1): Fan control configuration (sent to ESP32 on connection via FAN verb).

### Community 228 - "Community 228"
Cohesion: 1.0
Nodes (1): OTA firmware update configuration (GPIO pins for bootloader entry).

### Community 229 - "Community 229"
Cohesion: 1.0
Nodes (1): True if both GPIO pins are configured.

### Community 230 - "Community 230"
Cohesion: 1.0
Nodes (1): Day/night mode synchronisation configuration.

### Community 231 - "Community 231"
Cohesion: 1.0
Nodes (1): Clock synchronisation configuration.

### Community 232 - "Community 232"
Cohesion: 1.0
Nodes (1): Status handler configuration.

### Community 233 - "Community 233"
Cohesion: 1.0
Nodes (1): UART serial configuration.

### Community 234 - "Community 234"
Cohesion: 1.0
Nodes (1): ESP32 connection state-machine timeouts.

### Community 235 - "Community 235"
Cohesion: 1.0
Nodes (1): CC1101 433MHz module configuration (SPI on Pi, RFLink TCP server).

### Community 236 - "Community 236"
Cohesion: 1.0
Nodes (1): Box / ESP32 stack: language, weather, sensors, fan, OTA.

### Community 237 - "Community 237"
Cohesion: 1.0
Nodes (1): Main configuration class.

### Community 238 - "Community 238"
Cohesion: 1.0
Nodes (1): Create Config from Home Assistant options.

### Community 239 - "Community 239"
Cohesion: 1.0
Nodes (1): Convert a level name string to a logging level int. Defaults to INFO.

### Community 240 - "Community 240"
Cohesion: 1.0
Nodes (1): Setup logging configuration.          Args:         level: Logging level (defaul

### Community 241 - "Community 241"
Cohesion: 1.0
Nodes (1): Internationalization (i18n) module for HA Box App.  This module provides transla

### Community 242 - "Community 242"
Cohesion: 1.0
Nodes (1): Translation manager for HA Box App.

### Community 243 - "Community 243"
Cohesion: 1.0
Nodes (1): Initialize the translator.          Args:             language: Language code (e

### Community 244 - "Community 244"
Cohesion: 1.0
Nodes (1): Detect the language to use.          Args:             language: Explicit langua

### Community 245 - "Community 245"
Cohesion: 1.0
Nodes (1): Load translation file for the current language.

### Community 246 - "Community 246"
Cohesion: 1.0
Nodes (1): Find the App root directory (translations, etc.).          Returns:

### Community 247 - "Community 247"
Cohesion: 1.0
Nodes (1): Get a translated message.          Args:             key: Translation key (e.g.,

### Community 248 - "Community 248"
Cohesion: 1.0
Nodes (1): Get the current language code.

### Community 249 - "Community 249"
Cohesion: 1.0
Nodes (1): Get the global translator instance.      Args:         language: Optional langua

### Community 250 - "Community 250"
Cohesion: 1.0
Nodes (1): Convenience function to translate a key.      Args:         key: Translation key

### Community 251 - "Community 251"
Cohesion: 1.0
Nodes (1): Aggregate system status for the STATUS message to ESP32.         Does not requir

### Community 252 - "Community 252"
Cohesion: 1.0
Nodes (1): Fire a Home Assistant event via the Core API (POST /core/api/events/<event_type>

### Community 253 - "Community 253"
Cohesion: 1.0
Nodes (1): No-op: day/night state is handled by the ha_box_mode_changed event         consu

### Community 254 - "Community 254"
Cohesion: 1.0
Nodes (1): Call Home Assistant service light.turn_off with entity_id "all"         to turn

### Community 255 - "Community 255"
Cohesion: 1.0
Nodes (1): Key-value pair for message parameters.

### Community 256 - "Community 256"
Cohesion: 1.0
Nodes (1): Incoming message from ESP32.

### Community 257 - "Community 257"
Cohesion: 1.0
Nodes (1): Initialize kv_count from kv list.

### Community 258 - "Community 258"
Cohesion: 1.0
Nodes (1): Get a value by key.          Args:             key: Key to look up.

### Community 259 - "Community 259"
Cohesion: 1.0
Nodes (1): ACK response from ESP32.

### Community 260 - "Community 260"
Cohesion: 1.0
Nodes (1): ESP32 communication handler using ASCII protocol over UART.      This class mana

### Community 261 - "Community 261"
Cohesion: 1.0
Nodes (1): Initialize ESP32 communication handler.          Args:             device: Seria

### Community 262 - "Community 262"
Cohesion: 1.0
Nodes (1): Auto-detect serial device.          Returns:             Device path, or raises

### Community 263 - "Community 263"
Cohesion: 1.0
Nodes (1): Start the communication handler.          Opens the serial port and starts the p

### Community 264 - "Community 264"
Cohesion: 1.0
Nodes (1): Stop the communication handler.          Closes the serial port and stops the po

### Community 265 - "Community 265"
Cohesion: 1.0
Nodes (1): Reset the boot failure counter (call after a successful OTA or connection).

### Community 266 - "Community 266"
Cohesion: 1.0
Nodes (1): Return the current boot failure counter value.

### Community 267 - "Community 267"
Cohesion: 1.0
Nodes (1): Get time since last valid message (in seconds).          Returns:             Ti

### Community 268 - "Community 268"
Cohesion: 1.0
Nodes (1): Check if we have ever received a message from ESP32.                  Returns:

### Community 269 - "Community 269"
Cohesion: 1.0
Nodes (1): Set callback for message authorization.          Args:             callback: Fun

### Community 270 - "Community 270"
Cohesion: 1.0
Nodes (1): Set callback for incoming ACKs.          Args:             callback: Function th

### Community 271 - "Community 271"
Cohesion: 1.0
Nodes (1): Get next message ID.          Returns:             Next unique message ID.

### Community 272 - "Community 272"
Cohesion: 1.0
Nodes (1): Send a command to ESP32.          Args:             verb: Command verb (e.g., "R

### Community 273 - "Community 273"
Cohesion: 1.0
Nodes (1): Send a command and wait for ACK (synchronous, blocking).          Args:

### Community 274 - "Community 274"
Cohesion: 1.0
Nodes (1): Send ACK OK for a message.          Args:             msg_id: Message ID to ackn

### Community 275 - "Community 275"
Cohesion: 1.0
Nodes (1): Send ACK ERR for a message.          Args:             msg_id: Message ID to ack

### Community 276 - "Community 276"
Cohesion: 1.0
Nodes (1): Main polling loop (runs in background thread).

### Community 277 - "Community 277"
Cohesion: 1.0
Nodes (1): Process incoming serial data.          Args:             data: Raw bytes from se

### Community 278 - "Community 278"
Cohesion: 1.0
Nodes (1): Process a complete line.          Args:             line: Complete line string (

### Community 279 - "Community 279"
Cohesion: 1.0
Nodes (1): Parse an ACK line.          Format: "ACK <id> OK" or "ACK <id> ERR <code>"

### Community 280 - "Community 280"
Cohesion: 1.0
Nodes (1): Parse a message line.          Format: "<id> <VERB> [key=value]..."          Arg

### Community 281 - "Community 281"
Cohesion: 1.0
Nodes (1): Automatically send ACK for a message (with authorization check).          Args:

### Community 282 - "Community 282"
Cohesion: 1.0
Nodes (1): Check if message ID is a duplicate.          Args:             msg_id: Message I

### Community 283 - "Community 283"
Cohesion: 1.0
Nodes (1): Remember a message ID for deduplication.          Args:             msg_id: Mess

### Community 284 - "Community 284"
Cohesion: 1.0
Nodes (1): RF433 status fetcher — probes CC1101 via SPI to check if it is reachable.

### Community 285 - "Community 285"
Cohesion: 1.0
Nodes (1): Probe CC1101 PARTNUM register via SPI.      The CC1101 PARTNUM register (address

### Community 286 - "Community 286"
Cohesion: 1.0
Nodes (1): A sensor entity updated by HA Box addon events.

### Community 287 - "Community 287"
Cohesion: 1.0
Nodes (1): Sensor showing current day/night mode as text.

### Community 288 - "Community 288"
Cohesion: 1.0
Nodes (1): Constants for HA Box integration.

### Community 289 - "Community 289"
Cohesion: 1.0
Nodes (1): Config flow for HA Box integration.

### Community 290 - "Community 290"
Cohesion: 1.0
Nodes (1): Handle the config flow for HA Box.

### Community 291 - "Community 291"
Cohesion: 1.0
Nodes (1): Dirty tracking rationale: avoid unnecessary e-paper refreshes

### Community 292 - "Community 292"
Cohesion: 1.0
Nodes (1): Budget system: max 2 partial refreshes per update to avoid ghosting

### Community 293 - "Community 293"
Cohesion: 1.0
Nodes (1): ESP32 firmware project directory layout

### Community 294 - "Community 294"
Cohesion: 1.0
Nodes (1): UIManager lifecycle documentation

### Community 295 - "Community 295"
Cohesion: 1.0
Nodes (1): E-Paper display GDEY037T03-FT21 (3.7", 240x416, SPI)

### Community 296 - "Community 296"
Cohesion: 1.0
Nodes (1): HA custom integration (device registry, grouped entities)

### Community 297 - "Community 297"
Cohesion: 1.0
Nodes (1): Planned: NFC PN7161 tag detection forwarded to HA automations

### Community 298 - "Community 298"
Cohesion: 1.0
Nodes (1): Planned: Compute Module 5 single-board integration

### Community 299 - "Community 299"
Cohesion: 1.0
Nodes (1): Known gaps: resetJ2 never called, heartbeat timeout mismatch, button long-press off state

### Community 300 - "Community 300"
Cohesion: 1.0
Nodes (1): UART troubleshooting: enable_uart=1, dtoverlay=minimal-bt in config.txt

### Community 301 - "Community 301"
Cohesion: 1.0
Nodes (1): Code conventions: Python PEP8/black/type hints, Bash shellcheck, YAML 2-space indent

### Community 302 - "Community 302"
Cohesion: 1.0
Nodes (1): CM5 IO Board README (KiCad v9 notice)

### Community 303 - "Community 303"
Cohesion: 1.0
Nodes (1): HA-Box Product Render – Customized View 18560868933

### Community 304 - "Community 304"
Cohesion: 1.0
Nodes (1): Update Icon (two circular arrows)

### Community 305 - "Community 305"
Cohesion: 1.0
Nodes (1): Settings Icon (gear/cog wheel)

### Community 306 - "Community 306"
Cohesion: 1.0
Nodes (1): NFC Icon (NFC logo in rounded square)

### Community 307 - "Community 307"
Cohesion: 1.0
Nodes (1): Light Off Icon (lightbulb with slash/off state)

### Community 308 - "Community 308"
Cohesion: 1.0
Nodes (1): Thread Network Icon (Thread protocol logo)

### Community 309 - "Community 309"
Cohesion: 1.0
Nodes (1): Matter Icon (Matter smart home protocol logo, asterisk/snowflake style)

### Community 310 - "Community 310"
Cohesion: 1.0
Nodes (1): Web Icon (globe/grid sphere)

### Community 311 - "Community 311"
Cohesion: 1.0
Nodes (1): LAN Icon (network hierarchy/tree diagram)
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

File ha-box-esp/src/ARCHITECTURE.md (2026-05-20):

# Architecture — ESP32 HA Box

## Overview

```
┌─────────────────────────────────────────────────────────────┐
│                         ESP32                                │
├─────────────────────────────────────────────────────────────┤
│                                                               │
│  ┌──────────┐      ┌──────────┐      ┌──────────┐          │
│  │  UART0   │ ───> │  Model   │ ───> │    UI    │          │
│  │ (Pi→ESP) │      │ (Shared) │      │ Manager  │          │
│  └──────────┘      └──────────┘      └──────────┘          │
│       │                  │                  │                │
│       │                  │                  ▼                │
│       │                  │         ┌────────────────┐       │
│       │                  │         │  Pages (5)     │       │
│       │                  │         ├────────────────┤       │
│       │                  │         │ - Onboarding   │       │
│       │                  │         │ - Loading      │       │
│       │                  │         │ - Home         │       │
│       │                  │         │ - Settings     │       │
│       │                  │         │ - Shutdown     │       │
│       │                  │         └────────────────┘       │
│       │                  │                  │                │
│       │                  │                  ▼                │
│       │                  │         ┌────────────────┐       │
│       │                  ▼         │ Widgets (11)   │       │
│       │         ┌──────────────┐   ├────────────────┤       │
│       │         │   Sensors    │   │ - StatusIcons  │       │
│       │         │              │   │ - Clock        │       │
│       │         │ - BME280     │   │ - Weather      │       │
│       │         │ - TMP102     │   │ - TempIn       │       │
│       │         │ - PowerBtn   │   │ - DayNight     │       │
│       │         │ - Fan        │   │ - Alerts       │       │
│       │         │ - Touch      │   │ - Button       │       │
│       │         └──────────────┘   │ - Brightness   │       │
│       │                             │ - Sound        │       │
│       │                             │ - Loading      │       │
│       │                             │ - Onboarding   │       │
│       │                             └────────────────┘       │
│       │                                      │                │
│       │                                      ▼                │
│       │                             ┌────────────────┐       │
│       └──────────────────────────> │   E-paper      │       │
│                                     │   240x416      │       │
│                                     │   UC8253       │       │
│                                     └────────────────┘       │
│                                                               │
└───────────────────────────────────────────────────────────────┘
```

## Components

### 1. Model (Shared state)

**Files**: `model/model.h`, `model/model.cpp`

**States**:
- `OnboardingState` — Initial setup (QR code, link)
- `LoadingState` — Loading screen (reason string, animation frame)
- `HomeState` — Dashboard (connectivity flags, weather, temperatures, clock, alerts)
- `SettingsState` — User preferences (brightness 0–4, sound enabled, language 0=FR/1=EN)

**Dirty tracking**:
- Each setter marks dirty flags (`DK_HM_TempIn`, `DK_HM_Clock`, etc.)
- Optimised for e-paper: avoids unnecessary refreshes

### 2. UIManager (Page lifecycle manager)

**File**: `ui/ui_manager.h`

**Responsibilities**:
- Page management (navigation, lifecycle hooks)
- Automatic rendering (full + partial refresh)
- Budget system (max 2 partial refreshes per update cycle)

**Lifecycle**: on navigation — `onExit()` → `onEnter()` → `drawFull()`; each loop — `tick()` → `applyDirty()` → `renderPartials()`.

### 3. Pages

**Files**: `ui/page_*.h`

- **PageOnboarding** — QR code + link for first-time setup
- **PageLoading** — Animated spinner + loading reason string
- **PageHome** — Main dashboard: status icons, clock, weather, temperature, day/night switch, alerts, buttons
- **PageSettings** — User preferences: brightness slider, sound toggle, language selection
- **PageShutdown** — Power-off screen shown during graceful shutdown sequence

**Methods**:
- `onEnter()` — Page init (called on entry)
- `onExit()` — Cleanup (called on exit)
- `tick()` — Local logic (animations, timers)
- `drawFull()` — Full render (full e-paper refresh)
- `applyDirty()` — Mark widgets dirty from model flags
- `renderPartials()` — Partial render (fast e-paper partial refresh)

### 4. Widgets

**Files**: `ui/widgets/widget_*.h`

**List**:
- `StatusIconsWidget` — Row of protocol icons (WiFi, LAN, web, Zigbee, Thread, Matter, 433MHz)
- `ClockWidget` — HH:MM display
- `WeatherWidget` — Weather icon + outdoor temperature
- `TempWidget` — Indoor temperature
- `DayNightSwitchWidget` — Touchable day/night mode toggle
- `AlertsWidget` — Warnings and errors count
- `ButtonWidget` — Touchable button with icon + label (All Off, Settings)
- `BrightnessSliderWidget` — 5-level brightness slider (Settings page)
- `SoundSwitchWidget` — Sound on/off toggle (Settings page)
- `LoadingWidget` — Animated spinner + reason text
- `OnboardingWidget` — QR code + link text

Each widget extends `WidgetBase` (CRTP template): holds a `Rect`, a `dirty` flag, and implements `renderFull()`, `renderPartial()`, and `applyDirty()`.

### 5. UART communication (Pi ↔ ESP32)

**Protocol**: ASCII (`AsciiProto`) — one message per line, ACK-based, deduplication, retry.

**Pi → ESP32**:
```
READY                           → Pi is up and running
HALTED                          → Pi is shutting down
SHUTDOWN_ACCEPTED               → Pi accepted shutdown, ESP32 may sleep
WEATHER code=2 tOut=245         → Weather update (code + outdoor temp in tenths °C)
CLOCK hh=14 mm=32 ss=07         → Clock sync
STATUS core=1 sup=1 wifi=1 ...  → Heartbeat + status icons
DAYMODE mode=0                  → Day/night mode (0=day, 1=night)
LANG id=1                       → Language (0=FR, 1=EN); persisted in NVS
FAN en=1 tOn=28 tFull=60        → Fan configuration; persisted in NVS
VERSION                         → Query firmware version
OTA                             → Firmware flash about to start (show update screen)
```

**ESP32 → Pi**:
```
READY              → ESP32 booted and ready
VERSION ver=0.1.4  → Firmware version (proactive + reply to query)
SENS tC=21.77 hum=48.71 pPa=97759  → BME280 sensor data (every 30 s)
CASE tC=38.2       → TMP102 case temperature (every 30 s)
DAYMODE mode=1     → Manual day/night override from touch switch
SHUTDOWN_REQUEST   → User pressed power button (short press)
ALL_OFF            → User pressed All Off on screen
```

**Callbacks**:
- `authorizeIncoming()` — Whitelist of accepted verbs
- `onMsg()` — Receives message → updates `Model`
- `onAck()` — Receives ACK → resets heartbeat timer

### 6. Sensors & Control

**BME280** (custom driver, `BME280.h`):
- Temperature, humidity, pressure
- I2C (SDA=21, SCL=22)
- Polled every 5 s; model updated directly; aggregated data sent to Pi every 30 s via `SENS`

**TMP102** (custom driver, `TMP102.h`):
- Case (internal) temperature
- I2C; read every 5 s; sent to Pi every 30 s as `CASE`; drives fan PWM curve

**Touch FT6336** (custom driver, `touch_ft6336.h`):
- Capacitive touch controller integrated in the display (I2C, address 0x38)
- Coordinates forwarded to the active page via `uiManager.handleTouch(x, y)`

**PowerButton** (`PowerButton.h`):
- GPIO33 (button input, RTC-capable for deep sleep wake)
- J2 pulse for Pi power control (short pulse = wake/soft-stop, long hold = hard stop)
- Heartbeat timeout: 300 000 ms (5 min) → deep sleep
- Shutdown pending timeout: 60 000 ms → deep sleep fallback

**FanController** (`FanController.h`):
- PWM on GPIO26
- Temperature curve: configurable `tOn` / `tFull` from Pi via `FAN` verb; persisted in NVS
- Safe mode (100% duty) if TMP102 read fails

**i18n** (`i18n.h`, `lang/en.h`, `lang/fr.h`):
- Language selected by the Pi via `LANG id=0|1`; persisted in NVS
- All UI strings accessed through the active language file

**settings_persistence** (`settings_persistence.h`):
- NVS (flash) storage for fan curve, brightness, sound, and language
- Settings survive deep sleep and power cycles

---

## Data flows

### 1. Boot sequence

```
ESP32 boots
  │
  ├─> Init hardware (UART, I2C, Display, Touch, Fan)
  │
  ├─> Restore NVS settings (fan config, brightness, language)
  │
  ├─> UIManager.begin(PageId::Loading)  →  "Waiting for Pi…"
  │
  ├─> Send VERSION to Pi (proactive)
  │
  ├─> Send READY to Pi
  │
  └─> loop()
       │
       ├─> Poll UART → receives READY from Pi
       │                └─> navigateTo(PageId::Home)
       │
       └─> Home page displayed
```

### 2. Sensor data (ESP32 → Pi)

```
loop()
  │
  ├─> BME280.read()  →  tC, hPct, pPa
  │
  ├─> Model.setTempInX10(tC * 10)
  │    └─> dirty |= DK_HM_TempIn
  │
  ├─> proto.sendWithAck("SENS", ...)   (every 30 s)
  │    └─> Pi replies "ACK 2 OK"
  │         └─> touchHeartbeat()
  │
  └─> UIManager.update()
       └─> renderPartials()
            └─> TempWidget partial refresh
```

### 3. Weather data (Pi → ESP32)

```
Pi sends: "5 WEATHER code=2 tOut=245"
  │
  └─> onMsg() callback
       │
       ├─> Model.setWeather(2)      →  dirty |= DK_HM_Weather
       ├─> Model.setTempOutX10(245) →  dirty |= DK_HM_TempOut
       │
       └─> UIManager.update()
            └─> WeatherWidget partial refresh
```

---

## E-paper optimisations

### Full vs Partial refresh

**Full refresh** (slow, ~2 s):
- Page navigation
- Display reset

**Partial refresh** (fast, ~300 ms):
- Widget updates (temperature, clock, etc.)
- Budget: max 2 per update cycle to prevent ghosting

### Dirty tracking

The model marks dirty flags when data changes; the UI consumes the flags and marks only the affected widgets for refresh.

**Flags** (bitmask, defined in `model/dirty_key.h`): `DK_OB_QRPayload`, `DK_OB_Link`, `DK_HM_Status`, `DK_HM_TempIn`, `DK_HM_TempOut`, `DK_HM_Weather`, `DK_HM_Humidity`, `DK_HM_Clock`, and more — one bit per updatable UI element.

### Budget system

`renderPartials()` accepts a budget (default 2). Widgets render in priority order — status icons → clock → weather → temperature — stopping when the budget is exhausted. This prevents multiple slow partial refreshes from blocking the main loop.

---

## Main loop

See `main.cpp` for the full implementation. In summary: `proto.poll()` → sensor reads → send SENS/CASE to Pi every 30 s → `uiManager.update()`.

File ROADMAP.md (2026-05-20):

# Roadmap - HA Box

## What works today (v0.2.0)

### App (Add-on) infrastructure
- Python App running on Home Assistant OS (Docker, s6-overlay)
- Supervisor + Core API client with retry logic
- AppArmor security profile (custom, least privilege)
- Configuration via App options (`config.yaml`)
- Multilingual support (FR/EN): auto-detected from HA Core config

### ESP32 ↔ Pi communication
- ASCII UART protocol over UART0 (115200 8N1)
- Connection management: READY handshake, reconnect on timeout
- OTA firmware update: automatic version check on connect, flash via esptool over UART0, boot failure recovery (ESP32 stuck in reset loop auto-reflashed)

### ESP32 features
- E-Paper display (3.7" GDEY037T03-FT21): Loading, Home, Settings pages
- Touch input (FT6336U): navigation, page switching
- BME280: temperature, humidity, pressure — sent to Pi every 30 s
- TMP102: case temperature — sent to Pi every 30 s
- Fan (PWM, temperature-based curve, configurable from App options, persisted in NVS)
- Power button: wake Pi (J2 pulse), graceful shutdown request, hard J2 stop on long press
- Deep sleep: heartbeat timeout (5 min), shutdown fallback (60 s)

### Pi App features
- Weather + outdoor temperature on E-Paper (configurable entity, updated every 5 min)
- Clock sync to ESP32 (every 60 s)
- HA status icons (Core, Supervisor, LAN, Wi-Fi, external access, Zigbee, Thread, Matter)
- Sensor entities in HA: BME280 × 3, TMP102 case temperature
- Shutdown host on button press (Supervisor API)
- "All Off" relay (light.turn_off on HA)

---

## Planned

### Pi App
- CC1101 433 MHz *(experimental)*: SPI driver + RFLink TCP server exist; HA events/entities not yet published

### Hardware / product
- Compute Module 5 carrier board: integrate Pi, ESP32, radios, and connectors on a single PCB for a cleaner, more reliable product

---

## Known gaps / to review

| Issue | Location | Notes |
|---|---|---|
| Button long press when Pi is OFF: no action | `PowerButton` | `handleLongPress()` has no else branch for Pi OFF state |
| Heartbeat timeout mismatch | `config.h` vs `.ino` | Default in `.h` is 5000 ms; overridden in `.ino` to 300 000 ms |
| Buzzer trigger points not reviewed | ESP32 firmware | 100 ms beep on event; exact triggers unverified |

---

## Dropped features

- **NFC (PN7161)**: Removed from scope. Users can use their smartphone's built-in NFC to pair new devices directly — a dedicated on-device NFC reader adds hardware cost and complexity without a clear advantage.

---

*Last updated: 2026-04-17*

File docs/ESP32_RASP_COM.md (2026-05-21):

# ESP32 ↔ Raspberry Pi UART Link

This document describes how the ESP32 firmware and the Raspberry Pi (running Home Assistant OS and the HA Box App) communicate over UART, and which responsibilities live on each side.

## High-level responsibilities

| Function | Owner (side) | Link (ESP32 ↔ Pi) | Direction | Notes |
|---|---|---|---|---|
| Front “Power” push button | ESP32 reads button | **J2 (power button)** | ESP32 → Pi | ESP32 simulates a power-button press on J2 (pulse ~150 ms). Short press = 120 ms–2 s, long press ≥ 5 s. |
| Graceful shutdown (PC-like) | Pi / HAOS | **UART** (short press) + **J2** (long press) | ESP32 → Pi | **Short press**: ESP32 sends `SHUTDOWN_REQUEST` → App calls Supervisor host shutdown API (see HA docs) → App sends `SHUTDOWN_ACCEPTED` → ESP32 enters deep sleep. **Long press**: ESP32 pulses J2 for a hard shutdown. |
| Wake / power on (without cutting power) | Pi wakes | **J2 (power button)** | ESP32 → Pi | ESP32 is woken by `ext0` on the button, then `powerBtn.begin()` triggers `pulseJ2()` to power on the Pi. |
| Reboot / maintenance | Pi / HAOS | UART | ESP32 → Pi | Reserved for future: ESP32 sends a whitelisted command (for example `REBOOT`), App triggers `ha host reboot` or equivalent. Not implemented yet. |
| E‑Paper display (SPI) | ESP32 drives display | UART | Pi → ESP32 | Pi sends **data** (`WEATHER`, `CLOCK`, `STATUS`, `LANG`, …). ESP32 updates the model and renders the UI pages (Loading, Home, Settings). |
| Touch (I2C) | ESP32 reads touch | UART | ESP32 → Pi | ESP32 sends `TOUCH` and high‑level actions (Home / All Off / Settings). The App can convert these into automations or service calls. |
| Onboarding “add device” | HA logic, ESP32 UI | UART | Bidirectional | HA decides the flow; ESP32 displays steps and collects inputs (touch). Planned, not fully implemented yet. |
| Temperature / humidity / pressure (BME280) | ESP32 | UART | ESP32 → Pi | ESP32 sends `SENS` (tC, hum, pPa); the App publishes values as sensors in Home Assistant. |
| Case temperature (TMP102) | ESP32 | UART | ESP32 → Pi | ESP32 sends `CASE` (tC) every 30 s; the App publishes it as `sensor.ha_box_case_temperature`. |
| Fan PWM (cooling) | ESP32 | UART | Pi → ESP32 | App sends `FAN` (en, tOn, tFull) once on connection; ESP32 applies the curve and persists it in NVS. Fan runs autonomously using TMP102 temperature. |
| Core / Supervisor / Network / Zigbee / Thread / Matter status | Pi / HA (source of truth) | UART | Pi → ESP32 | Implemented: the App sends `STATUS` with key/value fields (`core`, `sup`, `net`, `lan`, `wifi`, `ext`, `zigbee`, `thread`, `matter`); ESP32 maps these to icons. |
| Health check of Apps (Zigbee2MQTT, etc.) | Pi / Supervisor + HA | UART | Pi → ESP32 | The App queries Supervisor and Core entities; results are aggregated into the same `STATUS` payload. |

See `docs/HA_STATUS_TO_ESP32.md` for a deeper description of the status payload and fetchers.

## Hardware wiring

- **UART0** (Pi <-> ESP32 communication + OTA flashing):
  - Pi TXD (BCM 14) -> ESP32 RX0 (GPIO 3)
  - Pi RXD (BCM 15) -> ESP32 TX0 (GPIO 1)
  - GND -> GND (required for a common reference)

- **OTA GPIO** (bootloader entry, wired on haboxesp PCB):
  - Pi BCM 23 -> ESP32 IO0 (pull LOW before reset to enter ROM bootloader)
  - Pi BCM 24 -> ESP32 EN (pulse LOW then HIGH to reset the chip)

- **UART2** (ESP32 debug output only — not connected to Pi):
  - GPIO 17 (TX2) / GPIO 16 (RX2) — use a USB-serial adapter for debug if needed

## UART protocol (summary)

The protocol is ASCII-based, with one message per line:

- Command format:  
  `<id> VERB [key=value ...]`
- ACK format:  
  `ACK <id> OK` or `ACK <id> ERR <code>`

### Verbs from Pi -> ESP32

- `READY` - Pi is up and the App is running.
- `HALTED` - Pi / App is shutting down or going offline.
- `SHUTDOWN_ACCEPTED` - The App accepted a shutdown request; ESP32 can enter deep sleep immediately.
- `STATUS` - Heartbeat + key/values: `core`, `sup`, `net`, `lan`, `wifi`, `ext`, `zigbee`, `thread`, `matter`, `mhz433` (all `0` or `1`); `warn` and `err` (integers — HA warning/error counts).
- `WEATHER` - Weather code and outdoor temperature.
- `CLOCK` - Time sync (`hh`, `mm`, `ss`).
- `LANG` - UI language: `id=0` (French), `id=1` (English).
- `FAN` - Fan configuration: `en=0/1`, `tOn=<C>`, `tFull=<C>`. Sent once on connection; ESP32 persists in NVS.
- `DAYMODE` - Day/night mode: `mode=0` (day) or `mode=1` (night). Sent on sun.sun state change; also sent by ESP32 on manual override (bidirectional).
- `OTA` - Announces that a firmware flash is about to start. ESP32 switches to the firmware-update loading screen. Sent just before esptool begins flashing.
- `VERSION` - Query ESP32 firmware version. ESP32 replies with `VERSION ver=X.Y.Z`.
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

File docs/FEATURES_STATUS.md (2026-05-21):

# Features status

What HA Box does, organized by responsibility.
Update status when a feature changes: `done` | `partial` | `planned`
`optional` = not required for basic operation.
`[not reviewed]` = behavior not verified in code; check before optimizing.

---

## ESP32 only

| Feature | Status | When | UART from Pi | UART to Pi | Notes / to review |
|---|---|---|---|---|---|
| Display the time (clock, local auto-advance) | done | Continuous (~1 s local); synced on `CLOCK` receipt | `CLOCK hh mm ss` | — | Clock interval hardcoded to 60 s on Pi side |
| Display indoor temperature | done | On BME280 read (every 5 s) | — | — | Read directly from sensor on ESP32 |
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

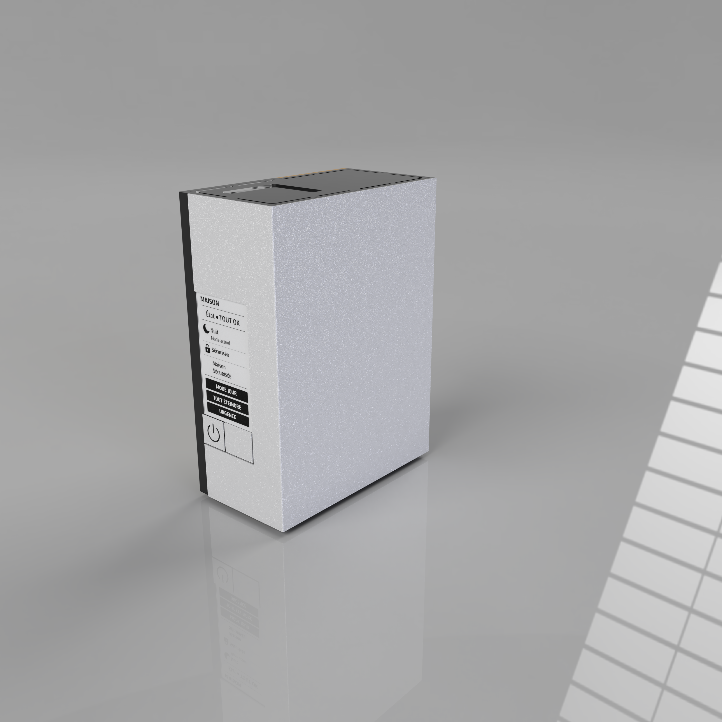
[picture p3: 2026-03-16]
hardware/3D plan/images/Home_assistant_box_Right.png

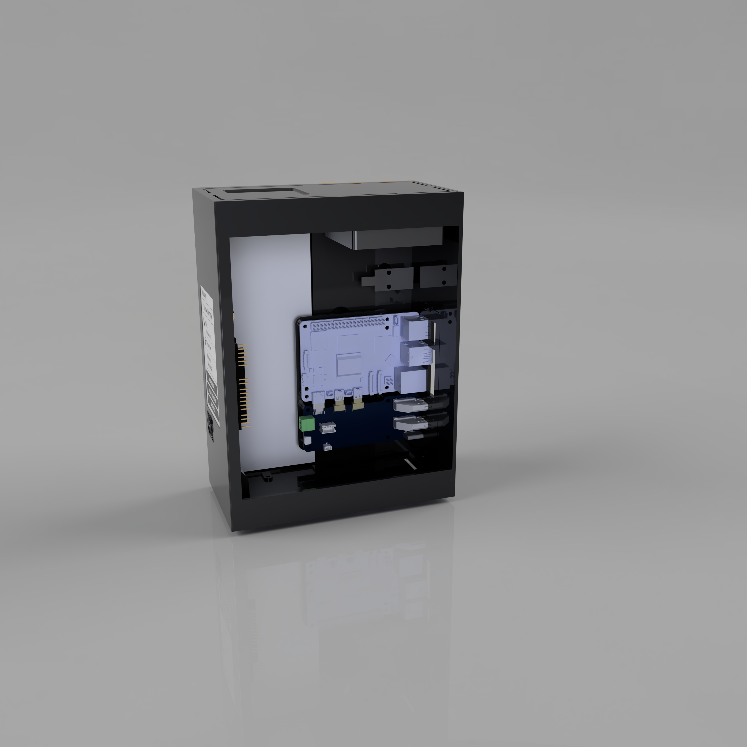
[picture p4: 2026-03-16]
hardware/3D plan/images/Home_assistant_box_inside2.png

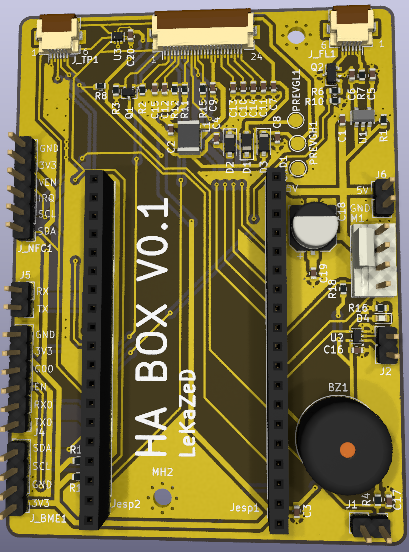
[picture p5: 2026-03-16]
hardware/haboxesp/images/espPcbFront.png

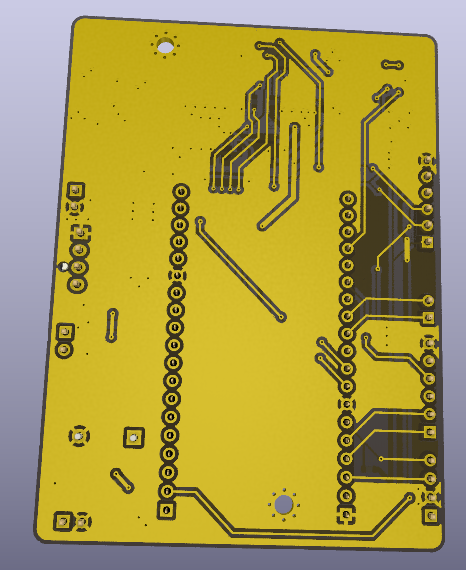
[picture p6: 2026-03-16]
hardware/haboxesp/images/espPcbBack.png

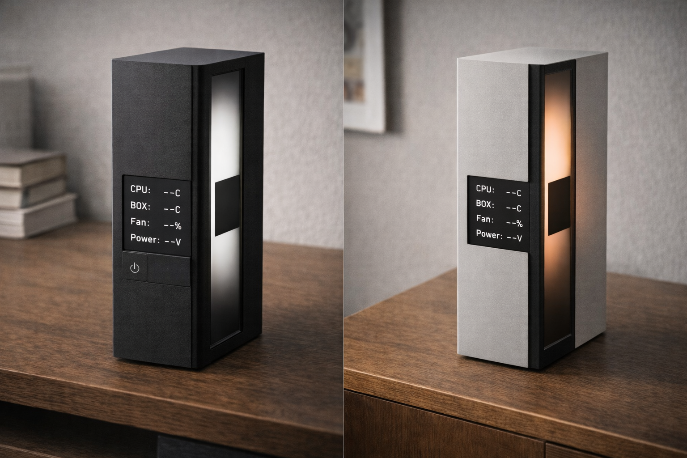
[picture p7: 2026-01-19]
hardware/visuel/ChatGPT Image 12 janv. 2026, 12_51_38.png

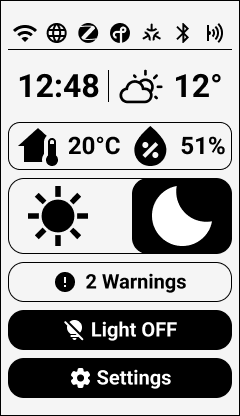
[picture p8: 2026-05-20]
hardware/visuel/Epaperscreen.png

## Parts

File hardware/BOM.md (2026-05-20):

# Bill of Materials – HA Box V0.1

This document lists all components required to build the HA Box V0.1.

Prices are indicative and based on Amazon France at time of writing. Links may
change; always verify the reference/model before ordering.

---

## 1. Raspberry Pi 5 stack

| Component | Model / Reference | Qty | Unit price | Link |
|---|---|-----|---|---|
| Raspberry Pi 5 | Pi 5 – 8 GB *(recommended)* | 1 | €108 | [Amazon](https://amazon.fr/dp/B0CK2FCG1K/) |
| *(alternative)* | Pi 5 – 16 GB | 1 | €170 | [Amazon](https://www.amazon.fr/dp/B0DSPYPKRG/) |
| Active cooler | Raspberry Pi Active Cooler (official) | 1 | €11 | [Amazon](https://www.amazon.fr/dp/B0CLXZBR5P/) |
| Power supply | Official Raspberry Pi 5 USB-C PSU – 27 W | 1 | €17 | [Amazon](https://www.amazon.fr/dp/B0CN3MRV16/) |
| M.2 + port extension hat | Waveshare PCIe to M.2 Multifunctional Adapter | 1 | €17 | [Amazon](https://www.amazon.fr/dp/B0G2SFFDTR/) |
| NVMe SSD | M.2 NVMe 128 GB (2280) | 1 | €32 | [Amazon](https://www.amazon.fr/dp/B0DPPRV85Q/) |
| Internal USB hub | Waveshare PCIe to USB 3.2 / 2.5G ETH / M.2 NVMe Adapter | 1 | €58 | [Amazon](https://www.amazon.fr/dp/B0FD6QHTQV/) |

**Notes:**
- The **Waveshare Multifunctional Adapter** routes the Pi's HDMI and USB-C ports to the rear of the enclosure and provides the M.2 NVMe slot.
- The **Waveshare USB / ETH / NVMe Adapter** adds an internal USB port used to host the Sonoff dongle inside the enclosure.
- The official active cooler replaces the standard heatsink; it mounts on the Pi 5 GPIO header side.

**Subtotal (8 GB config): ~€243**

---

## 2. haboxesp PCB + interface

The haboxesp is the custom PCB for this project. It hosts an ESP32 module and
connects the display, sensors, fan, and button. The PCB is available for
purchase (link coming soon).

| Component | Model / Reference | Qty | Unit price | Link |
|---|---|-----|---|---|
| haboxesp PCB (assembled) | haboxesp V0.1 | 1 | TBD | Coming soon |
| ESP32 module | ESP32-WROOM-32 (38-pin) | 1 | ~€10 | — |
| E-Paper display | GDEY037T03-FT21 (3.7", 240×416, integrated FT6336U touch) | 1 | €19 | [buyepaper.com](https://buyepaper.com/products/gdey037t03-ft21) |
| Environmental sensor | BME280 (temperature, humidity, pressure) | 1 | ~€3 | [Amazon](https://www.amazon.fr/dp/B0BJF3L9CS/) |
| Fan | Noctua NF-A6x15 5V PWM | 1 | €17 | [Amazon](https://www.amazon.fr/dp/B0DJP3987K/) |
| Push button | 4-pin tact switch (momentary) | 1 | ~€2 | [Amazon](https://www.amazon.fr/dp/B09WYRHPDL/) |

**Notes:**
- The **haboxesp PCB** includes the buzzer (HYT-1205), TMP102 case temperature sensor, FPC connectors for the display and front-light, I2C connectors for BME280, and all passive components. No additional PCB components need to be sourced separately.
- The **BME280** module must include humidity support. Do not substitute with BMP280 (no humidity).
- The **LED strip** (WS2812B) was evaluated but is **not used in V0.1**. The haboxesp PCB retains the connector for future use.

**Subtotal: ~€51 + PCB price TBD**

---

## 3. Radio modules

| Component | Model / Reference | Qty | Unit price | Link |
|---|---|-----|---|---|
| Zigbee + Thread coordinator | Sonoff ZigBee 3.0 USB Dongle Plus (EFR32MG21) | 1 | €23 | [Amazon](https://www.amazon.fr/dp/B09KXTCMSC/) |
| 433 MHz transceiver | CC1101 module (SPI) | 1 | ~€5 | TBD – driver experimental (SPI + RFLink TCP server implemented) |

**Notes:**
- The **Sonoff dongle** is plugged into the internal USB port provided by the Waveshare USB adapter, keeping it inside the enclosure.
- The **CC1101** module connects to the Pi 5 via SPI. The SPI driver and RFLink-compatible TCP server are implemented (experimental); HA entity/event publishing is not yet done.

**Subtotal: ~€28**

---

## 4. Enclosure

The enclosure combines 3D-printed structural parts with three finishing materials:
a wood side panel, a plexiglass front window (display area), and a steel front panel.

| | |
|---|---|
| Front | Inside |

*Left: assembled front view (wood side panel, plexiglass window, steel front panel). Right: inside view (3D-printed frame, haboxesp PCB, Raspberry Pi).*

### 4a. 3D-printed parts

All printed parts use the STL files in `hardware/3D plan/Box parts/`.

| Component | Reference | Qty | Unit price | Link |
|---|---|-----|---|---|
| Threaded heat inserts (M2.5, OD 3.5 mm) | Assorted kit – 300 pcs | 1 | €12 | [Amazon](https://www.amazon.fr/dp/B0CVVFRMRH/) |
| M2.5 standoffs and screws | Hex standoff assortment – 486 pcs | 1 | €17 | [Amazon](https://www.amazon.fr/dp/B0C1FY87PY/) |
| 3D print filament | PLA or PETG – 1 kg | 1 | ~€20 | — |

**STL parts to print:**

| File | Role | Qty | Notes |
|---|---|-----|---|
| `Box.stl` | Main structural frame | 1 | Largest part; holds all components |
| `Top.stl` | Top cover | 1 | Fan exhaust slot |
| `Backplate.stl` | Rear panel | 1 | HDMI / USB-C cutouts |
| `Support.stl` | Internal mounting bracket | 1 | PCB and Pi mounting |
| `Pied.stl` | Stand / base | 1 | Single base piece |
| `Button.stl` | Power button cap | 1 | |

**Notes:**
- Recommended material: **PETG** (better heat resistance near fan). PLA is acceptable for prototyping.
- Layer height: 0.2 mm. Infill: 20–30% (see `TODO_GETTING_STARTED.md` for per-part settings).
- Threaded inserts used are **M2.5, OD 3.5 mm**. The entire model is designed around this dimension. Do not substitute with a different OD.

### 4b. Finishing materials

| Material | Role | Dimensions | Notes |
|---|---|---|---|
| Wood panel | Left side panel – structural and decorative | TBD (from Fusion 360 model) | Thin veneer or solid wood sheet; has a cutout for the plexiglass window |
| Plexiglass / acrylic sheet | Window inset in the wood panel | TBD (from Fusion 360 model) | Transparent or frosted; sits inside the wood cutout on the left side panel |
| Steel sheet | Front face panel | TBD (from Fusion 360 model) | Matte finish; laser-cut or cut-to-size |

The wood panel and the plexiglass window are on the **same side** (left panel): the wood forms the surround and the acrylic fills the cutout as a window. The steel sheet covers the **front face** separately.

**Note:** Exact dimensions for all three materials are derived from the Fusion 360 source file (`hardware/3D plan/Fusion/Home assistant box.f3z`). Refer to the model or the assembly video for cutting dimensions.

**Subtotal: ~€49 + finishing materials (TBD)**

---

## Total (V0.1 – Pi 5 8 GB)

| Section | Subtotal |
|---|---|
| Raspberry Pi 5 stack | ~€243 |
| haboxesp PCB + interface | ~€51 + PCB TBD |
| Radio modules | ~€28 |
| 3D enclosure hardware | ~€49 |
| **Total (excl. PCB)** | **~€371** |

---

## Not included

- **WS2812B LED strip** – evaluated, not used in V0.1. Supported by haboxesp PCB connector for future use. [Amazon](https://www.amazon.fr/dp/B0D5CJK1YS/)
- **CC1101 module** – SPI driver + RFLink TCP server experimental; HA entity publishing not yet done.
- Tools (soldering iron, screwdrivers, calipers, 3D printer).

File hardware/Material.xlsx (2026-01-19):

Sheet: Feuil1
 | Nom | Prix | Lien | Commentaire
Raspberry Pi kit | Raspberry Pi 5 8go | 108.03 € | https://amazon.fr/dp/B0CK2FCG1K/?coliid=I3BJO1ZEMPHWGM&colid=3TPY2TASCROU9
 | Raspberry Pi® Ventilateur Actif | 10.75 € | https://www.amazon.fr/dp/B0CLXZBR5P/?coliid=I2N8E7SZ11DO1G&colid=3TPY2TASCROU9
 | Bloc d'alimentation Officiel Raspberry Pi 5 USB-C 27 W | 16.83 € | https://www.amazon.fr/dp/B0CN3MRV16/?coliid=IOECF3FIPP3AJ&colid=3TPY2TASCROU9
Sous Total |  | 135.61 €
Extentions Raspberry Pi | Waveshare PCIe to M.2 Multifunctional Adapter | 16.99 € | https://www.amazon.fr/Waveshare-Multifunctional-Compatible-Raspberry-Supports/dp/B0G2SFFDTR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 | Permet de deporter les prise HDMI et USB C (Alimentation)
 | SSD m.2 nvme 128go | 31.99 € | https://www.amazon.fr/dp/B0DPPRV85Q/?coliid=I3OCTQYNZHPYYY&colid=3TPY2TASCROU9 | Stockage de la machine en 2280
 | Waveshare PCIe to USB 3.2 Gen1 / 2.5G ETH/M.2 NVMe Adapter | 57.99 € | https://www.amazon.fr/dp/B0FD6QHTQV/?coliid=I2O6DFX5G30TMU&colid=3TPY2TASCROU9 | Prise interne pour sonoff
Sous Total |  | 106.97 €
Quincaillerie | 300 Pièces Insert Fileté | 11.99 € | https://www.amazon.fr/dp/B0CVVFRMRH/?coliid=IHHCGDJM1NAOU&colid=3TPY2TASCROU9 | Insert pour impression 3D
 | Lot de 486 entretoises hexagonales M2.5 | 16.99 € | https://www.amazon.fr/dp/B0C1FY87PY/?coliid=I2GT1ZJJVSK5UZ&colid=3TPY2TASCROU9 | visserie de fixation carte
Sous Total |  | 28.98 €
Protocoles | SONOFF ZigBee 3.0 USB Dongle Plus | 22.79 € | https://www.amazon.fr/SONOFF-Coordinator-Universelle-Passerelle-Assistant-dp-B09KXTCMSC/dp/B09KXTCMSC
Sous Total |  | 22.79 €
TOTAL |  | 294.35 €

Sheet: BOM
Home connect box
Part | Subpart | Title | Ref | Description | Link | Qty | Units | Units cost | Cost
Electonique | Raspberry Pi kit | Raspberry Pi 5 8go |  |  | https://amazon.fr/dp/B0CK2FCG1K/?coliid=I3BJO1ZEMPHWGM&colid=3TPY2TASCROU9 | 1 | 1 | 108.03 € | 108.03 €
 |  | Raspberry Pi® Ventilateur Actif |  |  | https://www.amazon.fr/dp/B0CLXZBR5P/?coliid=I2N8E7SZ11DO1G&colid=3TPY2TASCROU9 | 1 | 1 | 10.75 € | 10.75 €
 |  | Bloc d'alimentation Officiel Raspberry Pi 5 USB-C 27 W |  |  | https://www.amazon.fr/dp/B0CN3MRV16/?coliid=IOECF3FIPP3AJ&colid=3TPY2TASCROU9 | 1 | 1 | 16.83 € | 16.83 €
 | Sub Total |  |  |  |  |  |  |  | 135.61 € | 135.61 €
 | Extentions Raspberry Pi | Waveshare PCIe to M.2 Multifunctional Adapter |  | Permet de deporter les prise HDMI et USB C (Alimentation) | https://www.amazon.fr/Waveshare-Multifunctional-Compatible-Raspberry-Supports/dp/B0G2SFFDTR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 | 1 | 1 | 16.99 € | 16.99 €
 |  | SSD m.2 nvme 128go |  | Stockage de la machine en 2280 | https://www.amazon.fr/dp/B0DPPRV85Q/?coliid=I3OCTQYNZHPYYY&colid=3TPY2TASCROU9 | 1 | 1 | 31.99 € | 31.99 €
 |  | Waveshare PCIe to USB 3.2 Gen1 / 2.5G ETH/M.2 NVMe Adapter |  | Prise interne pour sonoff | https://www.amazon.fr/dp/B0FD6QHTQV/?coliid=I2O6DFX5G30TMU&colid=3TPY2TASCROU9 | 1 | 1 | 57.99 € | 57.99 €
 | Sub Total |  |  |  |  |  |  |  | 106.97 €
 | Protocoles | SONOFF ZigBee 3.0 USB Dongle Plus | EFR32MG21 |  | https://www.amazon.fr/SONOFF-Coordinator-Universelle-Passerelle-Assistant-dp-B09KXTCMSC/dp/B09KXTCMSC | 1 | 1 | 22.79 € | 22.79 €
 | Sub Total |  |  |  |  |  |  |  | 22.79 € | 22.79 €
 | Composant divers | 3.7Inch Front Lit With E Ink | GDEY037T03-FT21 | Screen for basic info display | https://buyepaper.com/products/gdey037t03-ft21 | 1 | 1 | 19.00 € | 19.00 €
 |  | Adaptateur SPI pour écran e-paper | ESP32-FTS02 | Connection card screen | https://buyepaper.com/products/esp32-fts02 | 1 | 1 | 10.00 € | 10.00 €
 |  | PN532 | PN532 | Capteur NFC | https://www.amazon.fr/Lecteur-Communication-Ultralight-IEC14443-4-Raspberry/dp/B0FB95HMMC?adgrpid=55184149614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 | 1 | 2 | 6.50 € | 13.00 € | 13.00 €
 |  | Fayrimi BMP280 | BMP280 | Capteur de temperature interne | https://www.amazon.fr/Fayrimi-BMP280-capteurs-temp%C3%A9rature-num%C3%A9rique/dp/B0BJF3L9CS | 1 | 3 | 3.15 € | 9.45 € | 9.45 €
 |  | ESP 32 | ESP32 | Controller de led |  |  |  |  | 10.00 €
 |  | Noctua NF-A6x15 5V PWM, | NF-A6x15 | Ventilateur de la boite | https://www.amazon.fr/dp/B0DJP3987K/?coliid=I33BL9KV6KKYW5&colid=3TPY2TASCROU9 | 1 | 1 | 16.99 € | 16.99 € | 16.99 €
 |  | SEZO WS2812B ECO Ruban LED 1M 144 LEDs DC5V | SEZO WS2812B ECO | Bande led | https://www.amazon.fr/dp/B0D5CJK1YS/?coliid=IQJD6AI77IXKL&colid=3TPY2TASCROU9 | 1 | 1 | 20.99 € | 20.99 €
 |  | Bouton Poussoir Electronique |  | Selection bouton 4 broches | https://www.amazon.fr/AUKENIEN-Interrupteurs-Electronique-Momentan%C3%A9s-dassortiment/dp/B09WYRHPDL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 | 1 | 1 | 9.99 € | 9.99 €
 | Sub Total |  |  |  |  |  |  |  | 109.42 € | 39.44 €
Total |  |  |  |  |  |  |  |  | 374.79 € | 197.84 €

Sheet: BOM (2)
Home connect box
Part | Subpart | Title | Ref | Description | Link | Qty | Units | Units cost | Cost
Electonique | Raspberry Pi kit | Raspberry Pi 5 16go |  |  | https://www.amazon.fr/-/en/SC1113-Raspberry-Pi-5-16GB/dp/B0DSPYPKRG (https://amazon.fr/dp/B0CK2FCG1K/?coliid=I3BJO1ZEMPHWGM&colid=3TPY2TASCROU9) | 1 | 1 | 169.96 € | 169.96 €
 |  | Raspberry Pi® Ventilateur Actif |  |  | https://www.amazon.fr/dp/B0CLXZBR5P/?coliid=I2N8E7SZ11DO1G&colid=3TPY2TASCROU9 | 1 | 1 | 10.75 € | 10.75 €
 |  | Bloc d'alimentation Officiel Raspberry Pi 5 USB-C 27 W |  |  | https://www.amazon.fr/dp/B0CN3MRV16/?coliid=IOECF3FIPP3AJ&colid=3TPY2TASCROU9 | 1 | 1 | 16.83 € | 16.83 €
 | Sub Total |  |  |  |  |  |  |  | 197.54 € | 197.54 €
 | Extentions Raspberry Pi | Waveshare PCIe to M.2 Multifunctional Adapter |  | Permet de deporter les prise HDMI et USB C (Alimentation) | https://www.amazon.fr/Waveshare-Multifunctional-Compatible-Raspberry-Supports/dp/B0G2SFFDTR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 | 1 | 1 | 16.99 € | 16.99 €
 |  | SSD m.2 nvme 128go |  | Stockage de la machine en 2280 | https://www.amazon.fr/dp/B0DPPRV85Q/?coliid=I3OCTQYNZHPYYY&colid=3TPY2TASCROU9 | 1 | 1 | 31.99 € | 31.99 €
 |  | Waveshare PCIe to USB 3.2 Gen1 / 2.5G ETH/M.2 NVMe Adapter |  | Prise interne pour sonoff | https://www.amazon.fr/dp/B0FD6QHTQV/?coliid=I2O6DFX5G30TMU&colid=3TPY2TASCROU9 | 1 | 1 | 57.99 € | 57.99 €
 | Sub Total |  |  |  |  |  |  |  | 106.97 €
 | Protocoles | SONOFF ZigBee 3.0 USB Dongle Plus | EFR32MG21 |  | https://www.amazon.fr/SONOFF-Coordinator-Universelle-Passerelle-Assistant-dp-B09KXTCMSC/dp/B09KXTCMSC | 1 | 1 | 22.79 € | 22.79 €
 | Sub Total |  |  |  |  |  |  |  | 22.79 € | 22.79 €
 | Composant divers | 3.7Inch Front Lit With E Ink | GDEY037T03-FT21 | Screen for basic info display | https://buyepaper.com/products/gdey037t03-ft21 | 1 | 1 | 19.00 € | 19.00 €
 |  | Adaptateur SPI pour écran e-paper | ESP32-FTS02 | Connection card screen | https://buyepaper.com/products/esp32-fts02 | 1 | 1 | 10.00 € | 10.00 €
 |  | PN532 | PN532 | Capteur NFC | https://www.amazon.fr/Lecteur-Communication-Ultralight-IEC14443-4-Raspberry/dp/B0FB95HMMC?adgrpid=55184149614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 | 1 | 2 | 6.50 € | 13.00 € | 13.00 €
 |  | Fayrimi BMP280 | BMP280 | Capteur de temperature interne | https://www.amazon.fr/Fayrimi-BMP280-capteurs-temp%C3%A9rature-num%C3%A9rique/dp/B0BJF3L9CS | 1 | 3 | 3.15 € | 9.45 € | 9.45 €
 |  | ESP 32 | ESP32 | Controller de led |  |  |  |  | 10.00 €
 |  | Noctua NF-A6x15 5V PWM, | NF-A6x15 | Ventilateur de la boite | https://www.amazon.fr/dp/B0DJP3987K/?coliid=I33BL9KV6KKYW5&colid=3TPY2TASCROU9 | 1 | 1 | 16.99 € | 16.99 € | 16.99 €
 |  | SEZO WS2812B ECO Ruban LED 1M 144 LEDs DC5V | SEZO WS2812B ECO | Bande led | https://www.amazon.fr/dp/B0D5CJK1YS/?coliid=IQJD6AI77IXKL&colid=3TPY2TASCROU9 | 1 | 1 | 20.99 € | 20.99 €
 |  | Bouton Poussoir Electronique |  | Selection bouton 4 broches | https://www.amazon.fr/AUKENIEN-Interrupteurs-Electronique-Momentan%C3%A9s-dassortiment/dp/B09WYRHPDL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 | 1 | 1 | 9.99 € | 9.99 €
 | Sub Total |  |  |  |  |  |  |  | 109.42 € | 39.44 €
Total |  |  |  |  |  |  |  |  | 436.72 € | 259.77 € | 366.74 €

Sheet: dataV2
Fonction | RefDes | Qty | Description | MPN/Type | Interface | Connecteur externe | Notes
CM5 Base | J_CM5A | 1 | Mezzanine CM5 A | TBD | CM5 bus | Non | Selon Raspberry Pi CM5 HW guide
CM5 Base | J_CM5B | 1 | Mezzanine CM5 B | TBD | CM5 bus | Non | Selon Raspberry Pi CM5 HW guide
Stockage | J_M2 | 1 | Slot NVMe M.2 Key M | M.2 Key M 2242/2280 | PCIe | Non | PCIe x1 du CM5
Stockage | H_M2 | 1 | Fixation mécanique | Insert+vis M2 | Mécanique | Non
Power | J_PWR | 1 | Entrée 5V | Bornier 2P / XT30 | Power | Oui | Alimentation 5V
Power | F1 | 1 | Polyfuse 2–5A | Polyfuse | Power | Non | Protection courant
Power | D_TVS5V | 1 | TVS 5V | SMBJ5.0A | Power | Non | Sur rail 5V
Power | Q_INV | 1 | Anti-inversion PMOS | Si2302 | Power | Non | Protection entrée
Power | U_Buck33 | 1 | Buck 5V→3.3V | MP1584EN | Power | Non | 3.3V logiques
Power | L_Buck33 | 1 | Inductance buck | 4.7µH | Power | Non
Power | C_IN33 | 2 | Condensateurs entrée | 22µF | Power | Non
Power | C_OUT33 | 2 | Condensateurs sortie | 22µF | Power | Non
ESP32 IO | U_ESP32 | 1 | Module ESP32 (ESP32-WROOM) | ESP32-WROOM | UART/ESPHome | Non | Pilote écran, boutons, LEDs, NFC events (si PN532 en I2C)
ESP32 IO | J_ESP32_PWR | 1 | Alim ESP32 3V3 | Header | Power | Oui | 3.3V + GND
E-ink Screen | J_EINK | 1 | Connecteur écran e-ink | FPC/FFC selon nappe | SPI+GPIO | Oui | Affichage + BUSY/DC/RST/CS
E-ink Screen | Q_FL | 1 | MOSFET frontlight | AO3400 | GPIO | Non | PWM backlight
E-ink Screen | R_FL | 1 | Res gate/frontlight | 330Ω | GPIO | Non
Touch | J_TOUCH | 1 | Connecteur tactile | Header 6 pins | I2C+GPIO | Oui | SCL/SDA/INT/RST/3V3/GND
I2C sensors | U_BMP | 1 | Capteur BMP280 | BMP280 | I2C | Non | Temp/pressure sensor
I2C sensors | U_PN532 | 1 | NFC PN532 | PN532 | I2C | Non | NFC reader
I2C sensors | R_I2C1 | 1 | Pull-up SDA | 2.2k | I2C | Non
I2C sensors | R_I2C2 | 1 | Pull-up SCL | 2.2k | I2C | Non
Buttons | SW1 | 1 | Bouton user | Tact switch | GPIO | Oui | User input
Buttons | SW2 | 1 | Bouton user | Tact switch | GPIO | Oui
LEDs | J_LED_PWR | 1 | Power LED strip | Header 3 pins | 5V/DI/GND | Oui | 5V + data + GND
LEDs | U_LS | 1 | Level shifter for WS2812 | 74AHCT125 | GPIO | Non
LEDs | R_LED | 1 | Series resistor WS2812 | 330Ω | GPIO | Non
LEDs | C_LED_BULK | 1 | Bulk cap for LED | 1000µF | Power | Non
Ventilation | J_FAN | 1 | Fan header 4 pins | Header 1x4 | 5V/PWM/TACH | Oui
Ventilation | Q_FANPWM | 1 | MOSFET fan PWM | 2N7002 | GPIO | Non
Zigbee/Thread | U_RF2_4 | 1 | 802.15.4 multiprotocol radio | MGM210P | UART | Non | 1 antenne interne 2.4GHz
Zigbee/Thread | J_UFL24 | 1 | U.FL 2.4GHz | U.FL-R-SMT | RF | Oui | Antenne 2.4GHz
Z-Wave EU | U_ZW | 1 | Z-Wave radio module | ZGM230S | UART | Non
Z-Wave EU | J_UFL868 | 1 | U.FL 868MHz | U.FL-R-SMT | RF | Oui | Antenne EU 868
433 MHz | U_433 | 1 | 433MHz transceiver | CC1101-mod | SPI | Non
433 MHz | J_UFL433 | 1 | U.FL 433MHz | U.FL-R-SMT | RF | Oui | Antenne 433MHz
Debug | TP_5V | 1 | TP 5V | Test point | Test | Non
Debug | TP_3V3 | 1 | TP 3V3 | Test point | Test | Non
Debug | TP_GND | 1 | TP GND | Test point | Test | Non

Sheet: data
Fonction | RefDes | Qté | Description | MPN / Type conseillé | Interface CM5 | Connecteur externe | Symbol KiCad | Footprint KiCad | Driver à écrire
BASE CM5 | J_CM5A | 1 | Connecteur mezzanine CM5 A | Selon Raspberry Pi CM5 HW guide | CM5 bus | Non | Connector_Generic:Conn_02xXX_Odd_Even | TBD_CM5_Mezzanine | Non
BASE CM5 | J_CM5B | 1 | Connecteur mezzanine CM5 B | Selon Raspberry Pi CM5 HW guide | CM5 bus | Non | Connector_Generic:Conn_02xXX_Odd_Even | TBD_CM5_Mezzanine | Non
BASE CM5 | U_EEP | 1 | EEPROM ID carte | AT24C32 / AT24C64 | I2C | Non | Memory_EEPROM:24LCxx | Package_SO:SOIC-8_3.9x4.9mm_P1.27mm | Non
STOCKAGE | J_M2 | 1 | Slot NVMe M.2 Key M | M.2 Key M 2242 ou 2280 | PCIe | Non | Connector:Conn_M.2 | Connector_M.2:M.2_Key_M | Non
STOCKAGE | H_M2 | 1 | Fixation mécanique NVMe | Insert + vis M2 | Mécanique | Non | Mechanical:MountingHole | MountingHole:MountingHole_2.2mm_M2 | Non
ALIMENTATION | J_PWR | 1 | Entrée alimentation 5V | Bornier 2P / XT30 | Power | Oui | Connector:Screw_Terminal_01x02 | TerminalBlock:TerminalBlock_2pin | Non
ALIMENTATION | F1 | 1 | Protection sur 5V | Polyfuse 2–5A | Power | Non | Device:Polyfuse | Fuse:Fuse_1206_3216Metric | Non
ALIMENTATION | D_TVS5V | 1 | TVS protection 5V | SMBJ5.0A | Power | Non | Device:D_TVS | Diode_SMD:D_SMB | Non
ALIMENTATION | Q_INV | 1 | Anti-inversion polarité | PMOS ideal diode | Power | Non | Device:Q_PMOS_GDS | Package_TO_SOT_SMD:SOT-23 | Non
ALIMENTATION | U_Buck33 | 1 | Buck 5V → 3.3V 3A | MP1584 / TPS5430 | Power | Non | Regulator_Switching:MP1584EN | Package_SO:SOIC-8_EP | Non
ALIMENTATION | L_Buck33 | 1 | Inductance buck | 2.2–4.7µH | Power | Non | Device:L | Inductor_SMD:L_XXXX | Non
ALIMENTATION | C_IN33 | 2 | Condensateurs entrée buck | 22–47µF | Power | Non | Device:C | Capacitor_SMD:C_1206_3216Metric | Non
ALIMENTATION | C_OUT33 | 2 | Condensateurs sortie buck | 22–47µF | Power | Non | Device:C | Capacitor_SMD:C_1206_3216Metric | Non
ÉCRAN E-INK | J_EINK | 1 | Connecteur écran e-ink | Selon nappe GDEY037T03 | SPI + GPIO | Oui | Connector_Generic:Conn_01xXX | Connector_FFC-FPC:FFC_0.5mm_XX | Non (userspace)
ÉCRAN E-INK | Q_FL | 1 | MOSFET frontlight | AO3400 / 2N7002 | PWM GPIO | Non | Device:Q_NMOS_GSD | Package_TO_SOT_SMD:SOT-23 | Non
ÉCRAN E-INK | R_FL | 1 | Résistance gate / courant | Selon schéma | PWM GPIO | Non | Device:R | Resistor_SMD:R_0603_1608Metric | Non
CAPTEURS | U_BMP | 1 | Capteur température/pression | BMP280 | I2C | Non | Sensor_Pressure:BMP280 | Package_LGA:LGA-8_2x2mm_P0.5mm | Non
CAPTEURS | R_I2C1 | 1 | Pull-up I2C SDA | 2.2k–4.7k | I2C | Non | Device:R | Resistor_SMD:R_0603_1608Metric | Non
CAPTEURS | R_I2C2 | 1 | Pull-up I2C SCL | 2.2k–4.7k | I2C | Non | Device:R | Resistor_SMD:R_0603_1608Metric | Non
NFC | U_PN | 1 | Contrôleur NFC | PN532 | UART recommandé | Antenne NFC | RF:NFC_PN532 | Package_QFN:QFN-40 | Non
NFC | J_NFC | 1 | Connecteur antenne NFC | Antenne 13.56 MHz | NFC | Oui | Connector_Generic:Conn_01x02 | PinHeader_1x02_P2.54mm | Non
LED WS2812 | J_LED | 1 | Sortie ruban LED | Bornier 3P | GPIO + 5V | Oui | Connector:Screw_Terminal_01x03 | TerminalBlock_1x03 | Oui
LED WS2812 | U_LS | 1 | Level shifter data | 74AHCT125 | GPIO | Non | 74xx:74AHCT125 | Package_SO:TSSOP-14 | Non
LED WS2812 | R_LED | 1 | Résistance série data | 330Ω | GPIO | Non | Device:R | Resistor_SMD:R_0603_1608Metric | Non
LED WS2812 | C_LED_BULK | 1 | Condensateur bulk 5V | 1000–2200µF | Power | Non | Device:CP | Capacitor_SMD:CP_Elec_10mm | Non
VENTILATION | J_FAN | 1 | Connecteur ventilateur 5V PWM | Header 1x4 | GPIO + 5V | Oui | Connector_Generic:Conn_01x04 | PinHeader_1x04_P2.54mm | Non
VENTILATION | Q_FANPWM | 1 | MOSFET PWM fan | 2N7002 | GPIO | Non | Device:Q_NMOS_GSD | Package_TO_SOT_SMD:SOT-23 | Non
INFRAROUGE | U_IRRX | 1 | Récepteur IR | TSOPxxxx | GPIO | Façade | Device:IRReceiver | Package_TO_SOT_THT:TO-92 | Non
INFRAROUGE | D_IR | 1 | LED IR émetteur | 940nm | PWM GPIO | Façade | Device:LED | LED_SMD:LED_1206_3216Metric | Non
INFRAROUGE | Q_IR | 1 | Driver LED IR | NMOS | PWM GPIO | Non | Device:Q_NMOS_GSD | Package_TO_SOT_SMD:SOT-23 | Non
ZIGBEE / THREAD | U_154 | 1 | Module radio 802.15.4 | Module UART certifié | UART | Non | RF_Module:RF_Module | RF_Module:Module_Castellated | Non
ZIGBEE / THREAD | J_UFL24 | 1 | Connecteur antenne 2.4GHz | u.FL | RF | Oui | Connector_Coaxial:Conn_Coaxial | Connector_Coaxial:U.FL_Hirose | Non
Z-WAVE | U_ZW | 1 | Module Z-Wave EU 868 | Module UART | UART | Non | RF_Module:RF_Module | RF_Module:Module_Castellated | Non
Z-WAVE | J_UFL868 | 1 | Connecteur antenne 868MHz | u.FL | RF | Oui | Connector_Coaxial:Conn_Coaxial | Connector_Coaxial:U.FL_Hirose | Non
RADIO 433 | U_433 | 1 | Transceiver 433MHz | CC1101-like | SPI | Non | RF:Transceiver | Package_QFN | Souvent oui
RADIO 433 | J_UFL433 | 1 | Connecteur antenne 433MHz | u.FL | RF | Oui | Connector_Coaxial:Conn_Coaxial | Connector_Coaxial:U.FL_Hirose | Non
IHM | SW1 | 1 | Bouton utilisateur | tact switch | GPIO | Façade | Switch:SW_Push | Button_Switch_SMD:SW_SPST_TACT | Non
IHM | SW2 | 1 | Bouton utilisateur | tact switch | GPIO | Façade | Switch:SW_Push | Button_Switch_SMD:SW_SPST_TACT | Non
DEBUG | TP_5V | 1 | Test point 5V | Pad | Test | Non | TestPoint:TestPoint | TestPoint:TestPoint_Pad_D1.0mm | Non
DEBUG | TP_3V3 | 1 | Test point 3.3V | Pad | Test | Non | TestPoint:TestPoint | TestPoint:TestPoint_Pad_D1.0mm | Non
DEBUG | TP_GND | 1 | Test point GND | Pad | Test | Non | TestPoint:TestPoint | TestPoint:TestPoint_Pad_D1.0mm | Non

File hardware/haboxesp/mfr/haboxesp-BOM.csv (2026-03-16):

Designator | Quantity | Value | Manufacturer | MFR.Part | LCSC
D4 | 1 | LED | LED_SMD:LED_0603_1608Metric | Hubei KENTO Elec | KT-0603R | C2286
C16,C17,C19,C20 | 4 | 100nF | Capacitor_SMD:C_0603_1608Metric | YAGEO | CC0603KRX7R9BB104 | C14663
U1 | 1 | RT9193-33GB | RT9193-33GB:SOT-23-5_RIT | RICHTEK | RT9193-33GB | C15651
C1,C6,C10,C11,C13 | 5 | 1uF/50V | Capacitor_SMD:C_0603_1608Metric | Samsung Electro-Mechanics | CL10A105KB8NNNC | C15849
C3 | 1 | 10uF | Capacitor_SMD:C_0603_1608Metric | Samsung Electro-Mechanics | CL10A106KP8NNNC | C19702
Q2 | 1 | AO3400A | Package_TO_SOT_SMD:SOT-23 | Alpha & Omega Semicon | AO3400A | C20917
C5 | 1 | 22nF/50V | Capacitor_SMD:C_0603_1608Metric | Samsung Electro-Mechanics | CL10B223KB8NNNC | C21122
R12,R15 | 2 | 0R | Resistor_SMD:R_0603_1608Metric | UNI-ROYAL(Uniroyal Elec) | 0603WAF0000T5E | C21189
R2 | 1 | 1M | Resistor_SMD:R_0603_1608Metric | UNI-ROYAL(Uniroyal Elec) | 0603WAF1004T5E | C22935
R6,R16 | 2 | 220 | Resistor_SMD:R_0603_1608Metric | UNI-ROYAL(Uniroyal Elec) | 0603WAF2200T5E | C22962
R3 | 1 | 0.47 | Resistor_SMD:R_0603_1608Metric | UNI-ROYAL(Uniroyal Elec) | 0603WAF470LT5E | C23411
R7 | 1 | 5 | Resistor_SMD:R_0603_1608Metric | UNI-ROYAL(Uniroyal Elec) | 0603WAF510KT5E | C25197
R1 | 1 | 100k | Resistor_SMD:R_0603_1608Metric | UNI-ROYAL(Uniroyal Elec) | 0603WAF1003T5E | C25803
R4,R8,R10,R11,R13,R14,R18 | 7 | 10k | Resistor_SMD:R_0603_1608Metric | UNI-ROYAL(Uniroyal Elec) | 0603WAF1002T5E | C25804
C2,C4,C7,C8,C9,C12,C14,C15 | 8 | 4.7uF/25V | Capacitor_SMD:C_0603_1608Metric | Samsung Electro-Mechanics | CL10A475KA8NQNC | C69335
D1,D2,D3 | 3 | MBR0530 | Diode_SMD:D_SOD-123 | Jiangsu Changjing Electronics Technology Co., Ltd. | MBR0530 | C77336
U3 | 1 | TMP102xxDRL | Package_TO_SOT_SMD:SOT-563 | Texas Instruments | TMP102AIDRLR | C99269
J_FL1 | 1 | FPC6-FL | Connector_FFC-FPC:Hirose_FH12-6S-0.5SH_1x06-1MP_P0.50mm_Horizontal | Shenzhen Kinghelm Elec | KH-FPC0.5-H2.0SMT-6P-QCHF | C3249990
J_TP1 | 1 | FPC6-TP | Connector_FFC-FPC:Hirose_FH12-6S-0.5SH_1x06-1MP_P0.50mm_Horizontal | Shenzhen Kinghelm Elec | KH-FPC0.5-H2.0SMT-6P-QCHF | C3249990
J_EP1 | 1 | FPC24-EP (0.5mm) | Connector_FFC-FPC:Hirose_FH12-24S-0.5SH_1x24-1MP_P0.50mm_Horizontal | Shenzhen Kinghelm Elec | KH-FPC0.5-H2.0SMT-24P-QCHF | C3249999
Q1 | 1 | Si1308EDL | Package_TO_SOT_SMD:SOT-323_SC-70 | VBsemi Elec | SI1308EDL-VB | C4355112
C18 | 1 | 100uF | Capacitor_SMD:CP_Elec_6.3x5.4 | FOSAN | FVH016ADA101M0654 | C7469977
U2 | 1 | 74LVC1G66 | Package_TO_SOT_SMD:SOT-353_SC-70-5 | UTC(Unisonic Tech) | U74LVC1G66G | C7509611
BZ1 | 1 | Buzzer | Buzzer_Beeper:Buzzer_12x9.5RM7.6 | HYDZ | HYT-1205 IC | C7544833
L1 | 1 | 47 uH 500mA(Max) | Inductor_SMD:L_1812_4532Metric | ABC | ACC4532470K2B | C22469103

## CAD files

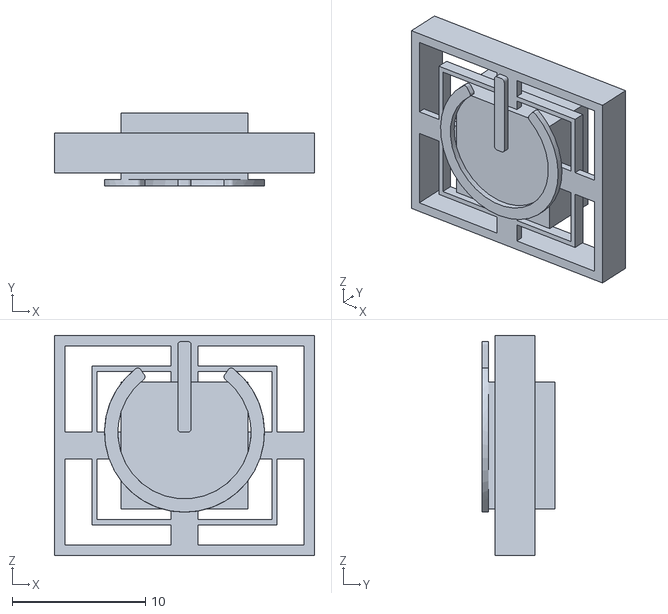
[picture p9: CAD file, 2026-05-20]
hardware/3D plan/Box parts/Button_power.stl
19.5 x 5.50 x 16.5

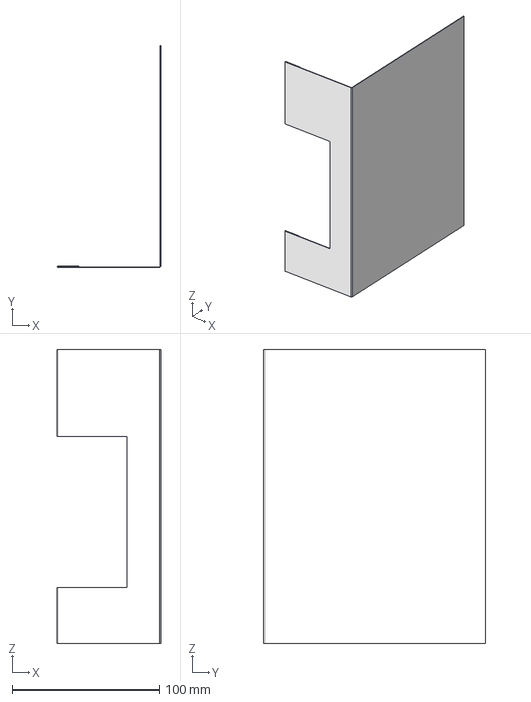
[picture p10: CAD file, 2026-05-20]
hardware/3D plan/Box parts/Steels/Cover.step
70.5 x 151.0 x 200.0 mm

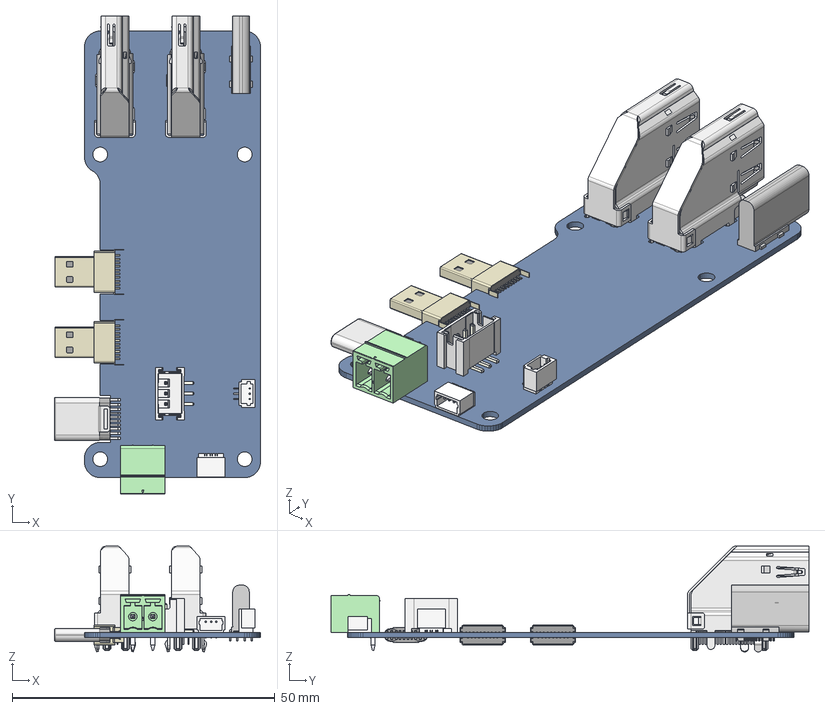
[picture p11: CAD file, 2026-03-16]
hardware/3D plan/Fusion/Pi5-Connector-Adapter.stp
39.2 x 91.0 x 20.1 mm
HDMI_TYPE_C_ADAPTER_PCB-240308
HDMI-MICRO--19P000 x 2
TYPEC-16P--H0001
HDMI_90D-SIDE x 2
TYPE-C_CY-JTF4-14PA-900
USER_LIBRARY-DS1066-04-3MSV6_1
KEFA_3_81MM_2PIN_MALE_RA
PITCH1MM-3PIN-SMT-WO
PITCH1MM-3PIN-SMT-L

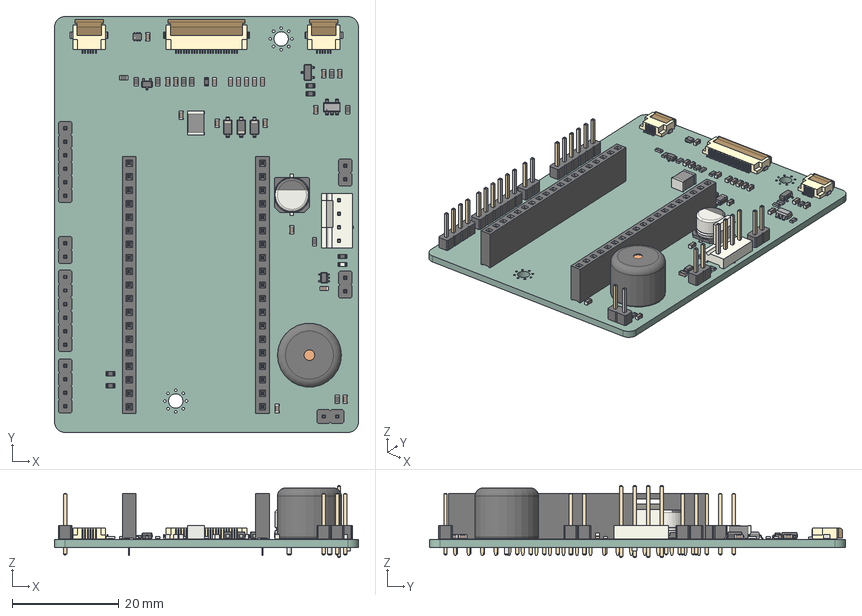
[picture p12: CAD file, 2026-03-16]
hardware/haboxesp/haboxesp.step
57.0 x 78.0 x 13.5 mm
PinHeader_1x02_P2.54mm_Vertical x 4
C_0603_1608Metric x 19
lock x 3
pins x 3
SOT-323_SC-70
R_0603_1608Metric x 15
D_SOD-123 x 3
SOT-353_SC-70-5
LED_0603_1608Metric
PinHeader_1x06_P2.54mm_Vertical x 2
FanPinHeader_1x04_P2.54mm_Vertical
SOT-563
SOT-23-5_RIT
PinSocket_1x19_P2.54mm_Vertical x 2
Buzzer_12x9.5RM7.6
SOT-23
PinHeader_1x04_P2.54mm_Vertical
L_1812_4532Metric
CP_Elec_6.3x5.4
haboxesp_PCB

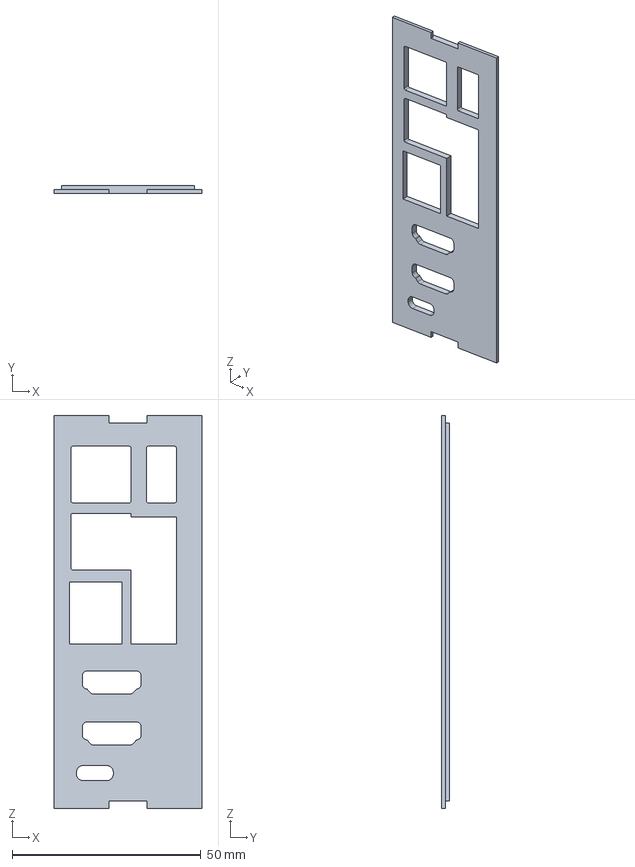
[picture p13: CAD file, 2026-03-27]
hardware/3D plan/Box parts/Backplate.step
39.2 x 2.00 x 104.2 mm

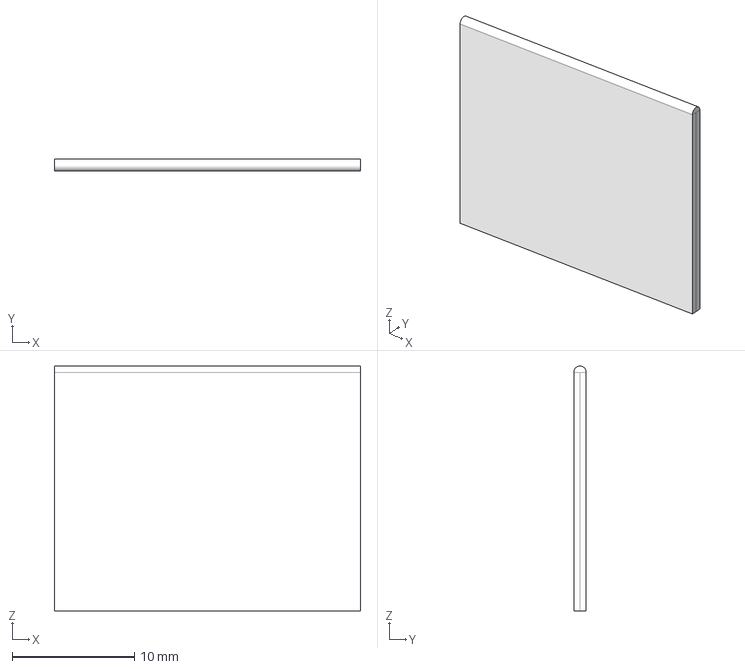
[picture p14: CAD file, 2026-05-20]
hardware/3D plan/Box parts/Steels/BOUTONPLEIN_FLAT.step
25.0 x 1.02 x 20.0 mm

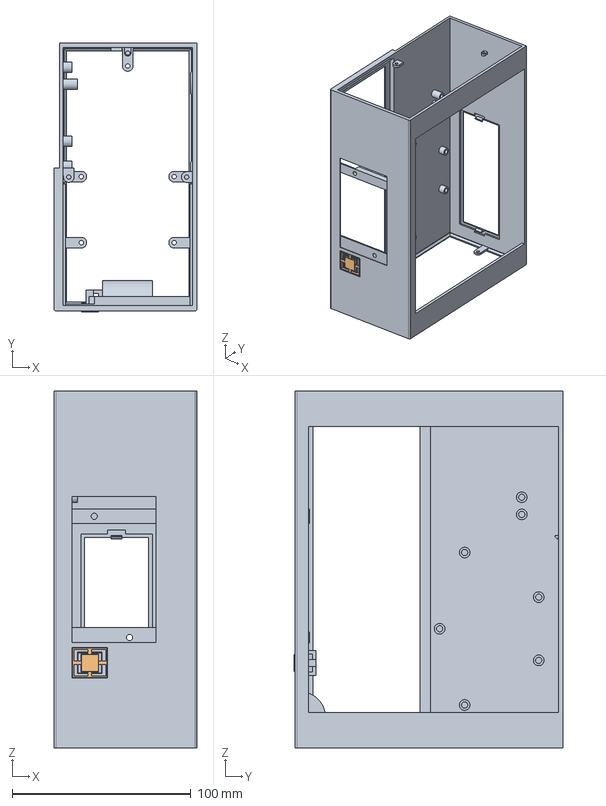
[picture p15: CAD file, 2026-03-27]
hardware/3D plan/Box parts/Box.step
80.0 x 150.5 x 200.0 mm

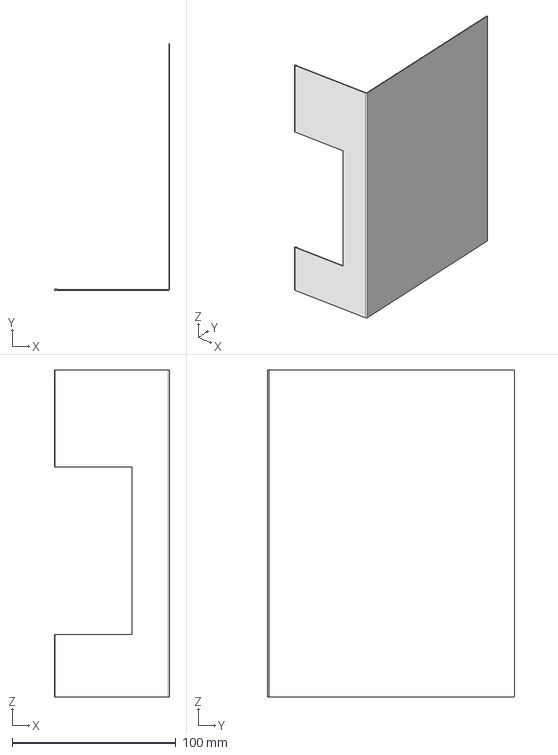
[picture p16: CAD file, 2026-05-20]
hardware/3D plan/Box parts/Steels/Cover_flat.step
70.5 x 151.0 x 200.0 mm

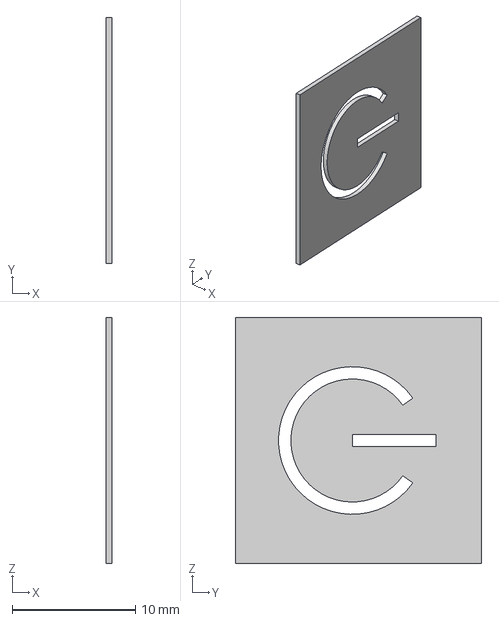
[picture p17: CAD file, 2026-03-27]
hardware/3D plan/Box parts/Steels/BOUTON.step
0.5 x 20.0 x 20.0 mm

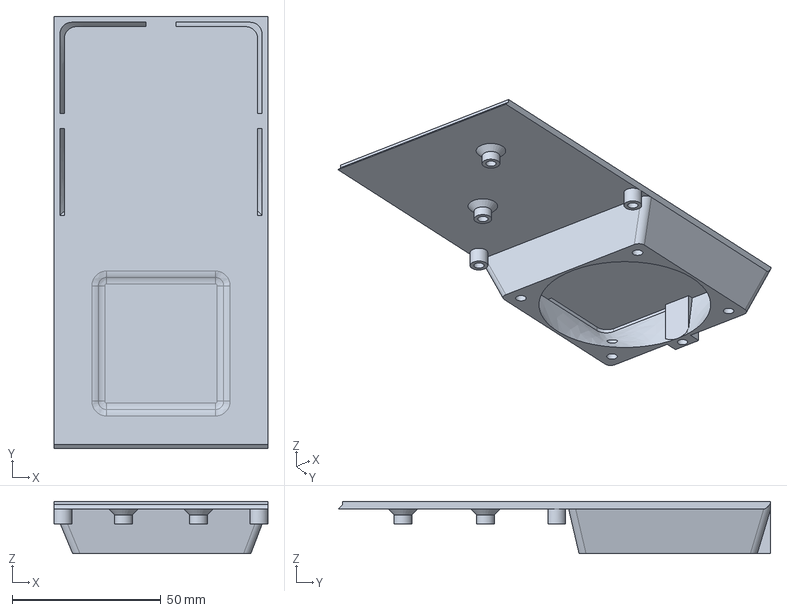
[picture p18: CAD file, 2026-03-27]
hardware/3D plan/Box parts/Top.step
72.0 x 145.5 x 17.5 mm

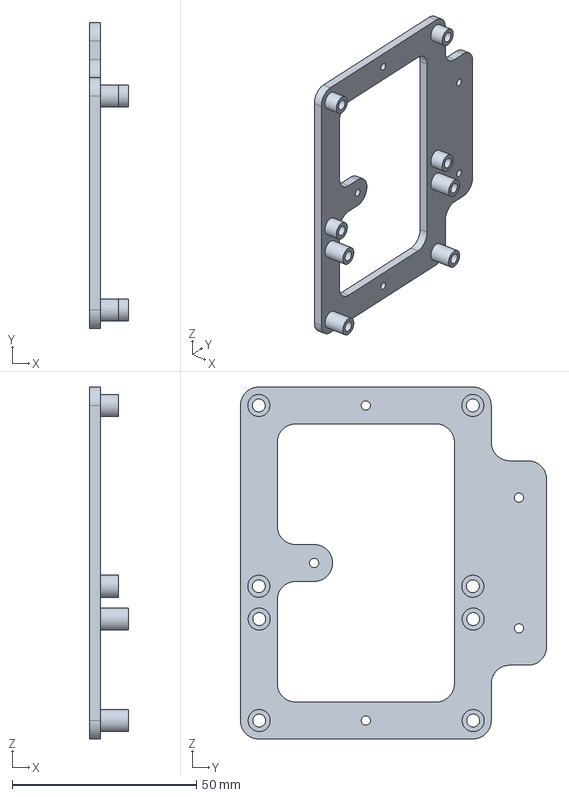
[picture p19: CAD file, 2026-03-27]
hardware/3D plan/Box parts/Support.step
10.6 x 83.0 x 95.4 mm

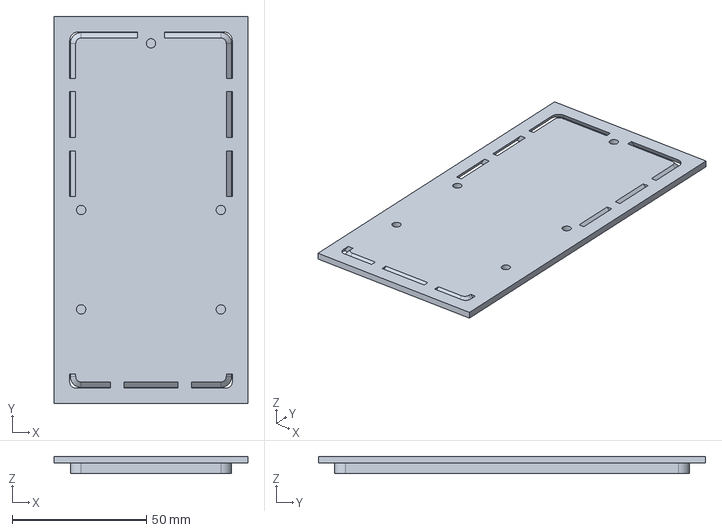
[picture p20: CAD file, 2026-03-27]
hardware/3D plan/Box parts/Foot.step
72.0 x 144.0 x 6.50 mm

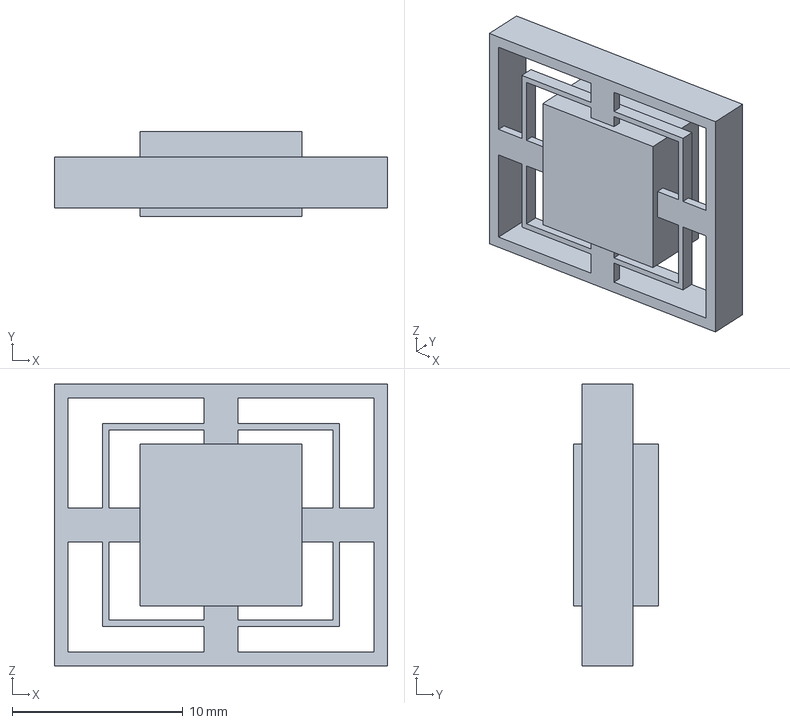
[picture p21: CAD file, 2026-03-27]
hardware/3D plan/Box parts/Button.step
19.5 x 5.00 x 16.5 mm

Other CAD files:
hardware/3D plan/Box parts/Steels/BOUTONPLEIN.step
hardware/3D plan/Box parts/Backplate.stl
hardware/3D plan/Box parts/Button.stl
hardware/3D plan/Box parts/Foot.stl
hardware/3D plan/Box parts/Support.stl
hardware/3D plan/Box parts/Top.stl
hardware/3D plan/Box parts/box.stl
hardware/3D plan/Fusion/Home assistant box.f3z

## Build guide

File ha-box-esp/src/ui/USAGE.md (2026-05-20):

# UIManager — Page lifecycle

## Architecture

```
UIManager
  ├─ Model (shared state)
  ├─ Display (e-paper)
  └─ Pages
      ├─ PageOnboarding (QR code + link)
      ├─ PageLoading (reason + animation)
      ├─ PageHome (dashboard)
      ├─ PageSettings (brightness / sound / language)
      └─ PageShutdown (power-off screen)
```

## Page lifecycle

Navigation calls `onExit()` on the current page, switches to the new page, calls `onEnter()`, then `drawFull()` for a full e-paper refresh.

Each `update()` call runs `tick()` (animations, timers), then — if the model has dirty flags — `applyDirty()` to mark affected widgets followed by `renderPartials()` with a budget of 2 partial refreshes.

## Model → UI flow

UART messages are received by `proto.poll()`, dispatched to handlers in `main.cpp`, which call model setters (e.g. `model.setWeather()`, `model.setClock(hh, mm, ss, receivedAtMs)`). Each setter marks a dirty flag. On the next `uiManager.update()`, dirty widgets render via fast partial refresh.

Humidity is NOT received via UART. It comes from the BME280 sensor read directly by the ESP32 every 5 s and is set in the model locally.

## Key properties

- **Simple main loop**: `proto.poll()` → sensors → `uiManager.update()`
- **Clear navigation**: `navigateTo(PageId::Home|Settings|Loading|…)`
- **Lifecycle hooks**: `onEnter()`, `onExit()`, `tick()`
- **Automatic dirty tracking**: optimised for e-paper — no unnecessary refreshes
- **Partial refresh budget**: max 2 partial refreshes per update cycle to prevent ghosting
- **Model/View separation**: UART handler → model setter → dirty flag → widget refresh

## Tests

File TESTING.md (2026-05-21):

# Testing HA Box App on Home Assistant OS

This guide explains how to test the HA Box App on Home Assistant OS.

## Prerequisites

1. **Home Assistant OS** installed on Raspberry Pi 4 or 5
2. **SSH access** to your Home Assistant instance
3. **Samba** or **SSH & Web Terminal** App enabled (for file transfer)
4. **Git** installed on your development machine

## Method 1: Local App (Recommended for Development)

### Step 1: Prepare Your App

1. **Create icon and logo** (optional but recommended):
   - Create `ha-box/icon.png` (256x256 pixels)
   - Create `ha-box/logo.png` (256x256 pixels)
   - Or use placeholder images for now

### Step 2: Transfer Files to Home Assistant

#### Option A: Using Samba Share

1. Enable the **Samba share** App in Home Assistant
2. Access the share from your computer (usually `\\homeassistant\config` or `smb://homeassistant.local`)
3. Navigate to `addons/` (or `addons/local/`, create if it does not exist)
4. Copy the entire `ha-box` folder to `addons/ha-box/` (or `addons/local/ha-box/`)

#### Option B: Using SSH

1. Enable the **SSH & Web Terminal** App in Home Assistant
2. SSH into your Home Assistant instance:
   ```bash
   ssh root@homeassistant.local
   # or
   ssh root@<your-ha-ip>
   ```
3. Create the local Apps directory:
   ```bash
   mkdir -p /config/addons
   ```
4. Transfer files using `scp` from your development machine:
   ```bash
   scp -r ha-box root@homeassistant.local:/config/addons/
   ```

### Step 3: Refresh App Store

1. In Home Assistant, go to **Settings** → **Apps** → **App Store**
2. Click the **⋮** (three dots) menu in the top right
3. Click **Check for updates**
4. Wait a few seconds and refresh the page (F5)

### Step 4: Install the App

1. You should now see "HA Box" in the App store
2. Click on **HA Box**
3. Click **Install**
4. Wait for installation to complete
5. Go to **Configuration** tab and configure options
6. Click **Start**

### Optional: Local Development on VM (amd64, No GPIO)

When running on a Home Assistant OS VM without real hardware (no UART, no GPIO, no SPI):

1. Edit `ha-box/config.yaml`:
   - Ensure architectures include both:
     ```yaml
     arch:
       - aarch64
       - amd64
     ```
   - Disable GPIO and kernel modules to avoid VM crashes:
     ```yaml
     gpio: false
     kernel_modules: false
     ```
   - For local builds, comment out the `image` line so the Supervisor builds from the local `Dockerfile`:
     ```yaml
     #image: "ghcr.io/YOUR_USERNAME/{arch}-addon-ha-box"
     ```
2. Copy the updated `ha-box` folder to the HAOS VM as described above.
3. Use **Check for updates** in the App Store, then install and start **HA Box**.

## Method 2: Git Repository (For Production)

### Step 1: Push to GitHub

1. Create a GitHub repository
2. Push your code:
   ```bash
   git remote add origin https://github.com/LeKaZeD/ha-box.git
   git push -u origin main
   ```

### Step 2: Add Repository to Home Assistant

1. In Home Assistant, go to **Settings** → **Apps** → **App Store**
2. Click the **⋮** menu → **Repositories**
3. Add repository URL: `https://github.com/LeKaZeD/ha-box`
4. Click **Add**
5. Refresh the page

### Step 3: Install the App

1. Find **HA Box** in the App store
2. Click **Install**
3. Configure and start

## Method 3: Direct Build and Test (Advanced)

### Step 1: Build the Docker Image Locally

```bash
cd ha-box
docker build -t ha-box:local --build-arg BUILD_ARCH=aarch64 .
```

### Step 2: Test the Container

```bash
docker run --rm -it \
  --device=/dev/ttyAMA0 \
  --device=/dev/serial0 \
  --device=/dev/gpiochip0 \
  ha-box:local \
  python3 /usr/bin/ha-box/main.py
```

## Troubleshooting

### App Not Appearing

- Check that `repository.yaml` is in the correct location
- Verify the `ha-box` folder structure matches the expected format
- Check Home Assistant logs: **Settings** → **System** → **Logs**
- Restart Home Assistant Supervisor

### Installation Fails

- Check Docker logs: `docker logs <container-id>`
- Verify all required files are present
- Check `config.yaml` syntax is valid YAML
- Ensure `Dockerfile` is correct

### App Crashes on Start

- Check App logs: **HA Box** → **Logs** tab
- Verify hardware permissions in `config.yaml`
- If RF433 is enabled: verify SPI is enabled in `/mnt/boot/config.txt` (`dtparam=spi=on`)
- Verify Python dependencies are installed correctly

### ESP32 Not Detected / UART Not Working

1. **Enable UART** on Raspberry Pi (HAOS):

   `/mnt/boot/config.txt` cannot be edited via SSH or the web terminal. Edit it physically — connect a keyboard and screen to the Pi, or mount the SD card / NVMe on a computer. See [docs/HARDWARE.md](docs/HARDWARE.md#pi-configtxt-haos) for the exact lines to add (differs between Pi 4 and Pi 5).

2. **Verify UART device exists**:
   ```bash
   ls -l /dev/serial0 /dev/ttyAMA0
   ```

3. **Verify GPIO chardev**:
   ```bash
   ls -l /dev/gpiochip0
   ```

## Development Workflow

1. **Make changes** to your code
2. **Transfer files** to Home Assistant (Method 1, Step 2)
3. **Restart the App** in Home Assistant
4. **Check logs** for errors
5. **Repeat** as needed

## Initial ESP32 Firmware Flash

The App bundles an ESP32 firmware binary and flashes it automatically via OTA when the version differs. However, for a **brand-new ESP32** (no firmware yet), you need to flash it manually once via USB.

### Requirements

- Arduino IDE 2.x with ESP32 board package installed
- USB-to-Serial adapter (or direct USB connection if supported by your board)
- GxEPD2 library installed via Library Manager
- `gdey/` subfolder copied from the GxEPD2 library into `ESPHOMEASSISTANT/` (see `ha-box-esp-fw/README.md`)

### Steps

1. Open `ha-box-esp-fw/ESPHOMEASSISTANT/ESPHOMEASSISTANT.ino` in Arduino IDE
2. Set board to `ESP32 Dev Module`, upload speed `115200`, partition scheme `Default 4MB with spiffs`
3. Connect the ESP32 via USB and select the correct port
4. Click **Upload**
5. Once flashed, disconnect USB and reconnect the ESP32 to the Pi via UART

From this point on, the App will handle firmware updates automatically (OTA via UART0 when the bundled version differs from what is running).

## Next Steps

Once the App is running:

1. Check logs to verify startup and ESP32 connection (`READY` handshake)
2. Verify sensor entities appear in Home Assistant (BME280 × 3, TMP102)
3. Check OTA: if ESP32 firmware version differs from bundled, flash should trigger automatically
4. Test configuration changes (fan curve, OTA GPIO pins)

---

*For more information, see the [Home Assistant Apps Documentation](https://developers.home-assistant.io/docs/apps/)*

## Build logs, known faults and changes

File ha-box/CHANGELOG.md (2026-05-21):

<!-- https://developers.home-assistant.io/docs/apps/presentation#keeping-a-changelog -->

## 0.2.0

### Added

- **OTA firmware update**: app automatically flashes the ESP32 when the bundled firmware version differs from the reported ESP32 version; controlled via `box.ota.io0_gpio` and `box.ota.en_gpio` config options; VERSION verb retry (up to 3 attempts), partial response salvage, and blind OTA recovery on ROM boot errors (up to 3 attempts)
- **Shutdown detection**: STATUS heartbeat accelerates to 5 s when the Pi receives a shutdown request from the ESP32; ESP32 transitions to `HALTING` state and enters deep sleep only when heartbeat silence is detected, or when the Pi 3.3V rail (GPIO5 via 1 kΩ) drops — whichever comes first
- **Pi alive hardware signal**: Pi 3.3V rail → 1 kΩ → ESP32 GPIO5 (VEN pad); gives a reliable ~10 s hardware warning before full Pi shutdown
- **CC1101 433 MHz module** *(experimental)*: SPI0/CE0 driver (no external library) exposing a RFLink-compatible TCP server on port 5557; the HA RFLink integration connects to `<pi-ip>:5557` to control any 433 MHz device; fires `ha_box_rf433_received` event on signal reception
- **Day/night mode sync**: polls `sun.sun` entity and sends `DAYMODE mode=0/1` to the ESP32 (0 = day, 1 = night); configurable via `daynight.update_interval`
- **Custom HA integration** (`ha_box`): groups all HA Box entities under a single device in the device registry
- **HA alerts widget** (E-Paper): Home page now shows warning and error counts from Home Assistant; driven by the `warn` and `err` keys in the `STATUS` verb
- **Zigbee / Thread / Matter detection**: now uses the HA config entries API for reliable detection, replacing heuristic-based checks
- **Configurable log level**: `box.log_level` option (trace / debug / info / warning / error / critical)
- **Extended config structure**: all options grouped by section: `general`, `weather`, `bme280`, `fan`, `ota`, `daynight`, `clock`, `status`, `uart`, `connection`, `rf433`

### ESP32 firmware (bundled v0.1.1)

- `PiState::HALTING`: new state between SHUTDOWN_ACCEPTED and deep sleep; waits for heartbeat silence or Pi 3.3V GPIO drop
- Pi alive GPIO (GPIO5 / VEN pad): `INPUT_PULLDOWN`; LOW = Pi off → triggers deep sleep
- HA alerts widget: displays `warn` and `err` counts received via `STATUS` verb
- 433 MHz icon (`MHZ433_ON/OFF_24x24`) shown in status bar based on `mhz433` STATUS key
- New icons: `check_circle`, `error_circle`, `warning_circle`, `update`, `433_on`, `433_off`
- WiFi and Bluetooth disabled at boot to reduce power consumption and RF interference
- Project migrated to PlatformIO (`ha-box-esp/`); dependencies managed via `platformio.ini`

---

## 0.1.45 (2026-03-31)

### Added

- Fan control configurable from App options (`esp32.fan.enabled`, `esp32.fan.min_temp`, `esp32.fan.max_temp`): values are sent to the ESP32 on every connection via the new `FAN` UART verb and persisted in ESP32 NVS so they survive deep sleep
- Case temperature sensor: ESP32 forwards TMP102 readings to the App every 30 s via the new `CASE` UART verb; exposed in Home Assistant as `sensor.ha_box_case_temperature`

### Changed

- Config section `control` renamed to `esp32` to clearly identify options that are pushed to the ESP32 firmware
- `esp32.fan`: removed unused `pin` and `auto_control` fields; default `min_temp` aligned to 28 °C (matches ESP32 firmware default)
- External access detection: Cloudflare tunnel Apps now trust the Supervisor running state instead of attempting an outbound HTTP check (which failed inside the container with Zero Trust enabled)
- Added Cloudflare App slug `9b69fd20_cloudflared` (brenner-tobias) to the default exposed App list

---
<!-- Versions 0.1.1 – 0.1.44 not yet documented. -->
---

## 0.1.0 (2026-01-20)

### Added

- Initial release
- Complete base infrastructure
- HAL (Hardware Abstraction Layer) for I2C, SPI, GPIO
- Home Assistant API client with retry logic
- Configuration management
- s6-overlay scripts for startup/shutdown
- Modular Python structure
- Configuration support via options.json
- Custom AppArmor security profile
- Security documentation (SECURITY.md)
- Presentation assets (icon.png, logo.png)
- Development setup for amd64 (gitignored)
- Optimized Dockerfile (build dependencies cleanup)
- Multilingual support infrastructure (translations/ folder, i18n.py module)
- Translation files for English and French (config.yaml labels/descriptions)

### Security

- Security rating: 6/6 (maximum)
- Custom AppArmor profile restricting to hardware devices only
- No privileged mode, no host network
- Minimal permissions following least privilege principle

### Known Issues

- Hardware drivers (BME280, E-Paper, NFC) are not yet implemented
- User interface on E-Paper display is not yet developed

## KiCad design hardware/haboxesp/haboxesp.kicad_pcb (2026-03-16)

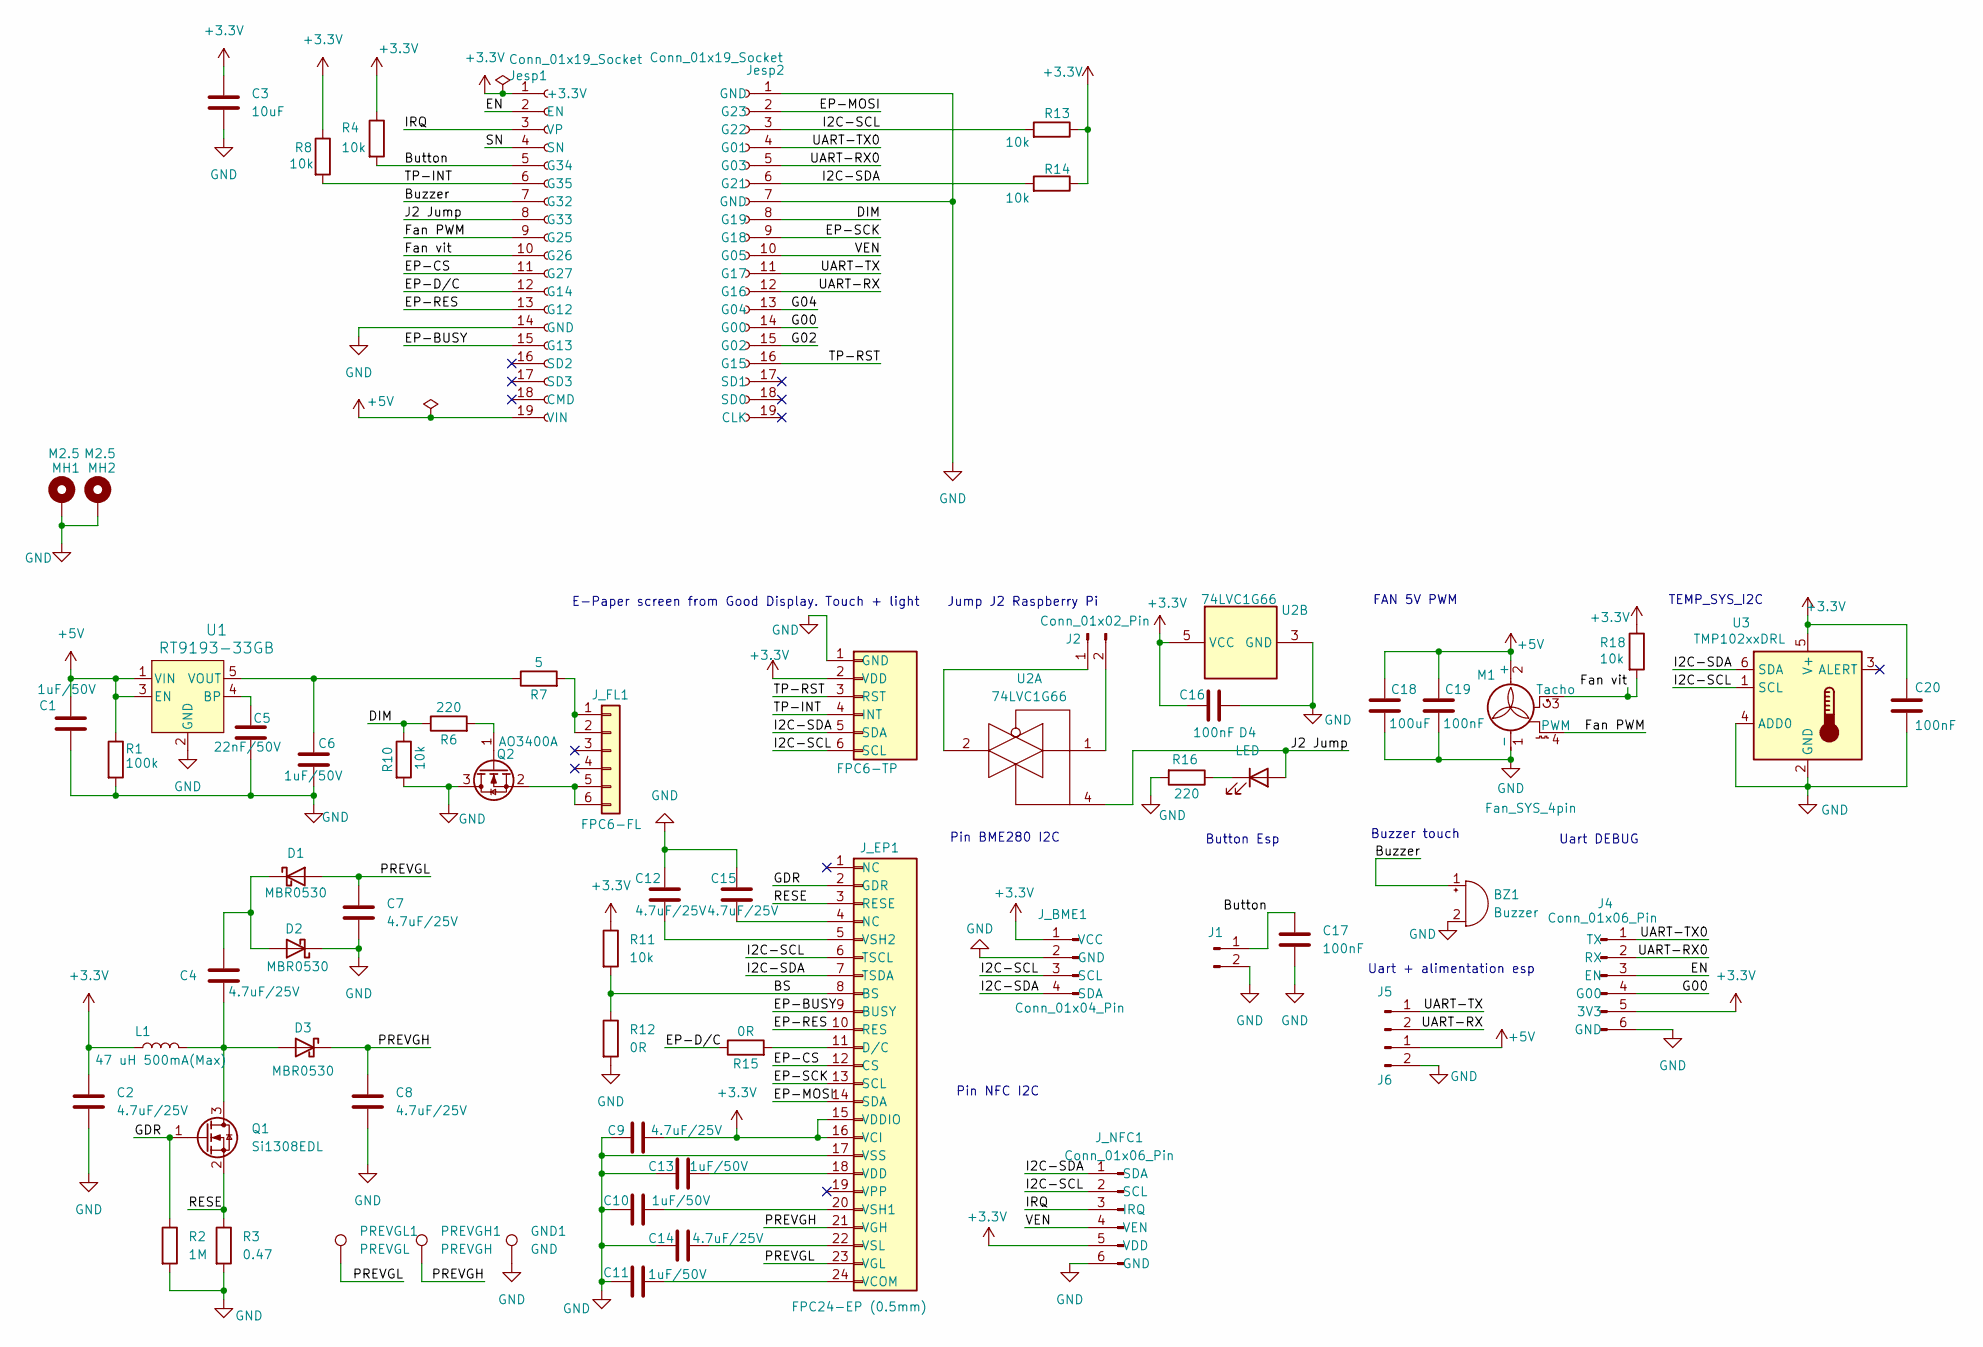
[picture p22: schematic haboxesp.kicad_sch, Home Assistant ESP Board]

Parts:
BZ1: Buzzer; Buzzer_12x9.5RM7.6; MFR.Part HYT-1205 IC; LCSC C7544833
C1, C6, C10, C11, C13: 1uF/50V; C_0603_1608Metric; MFR.Part CL10A105KB8NNNC; LCSC C15849
C2, C4, C7, C8, C9, C12, C14, C15: 4.7uF/25V; C_0603_1608Metric; MFR.Part CL10A475KA8NQNC; LCSC C69335
C3: 10uF; C_0603_1608Metric; MFR.Part CL10A106KP8NNNC; LCSC C19702
C5: 22nF/50V; C_0603_1608Metric; MFR.Part CL10B223KB8NNNC; LCSC C21122
C16, C17, C19, C20: 100nF; C_0603_1608Metric; MFR.Part CC0603KRX7R9BB104; LCSC C14663
C18: 100uF; CP_Elec_6.3x5.4; MFR.Part FVH016ADA101M0654; LCSC C7469977
D1, D2, D3: MBR0530; D_SOD-123; MFR.Part MBR0530; LCSC C77336
D4: LED; LED_0603_1608Metric; MFR.Part KT-0603R; LCSC C2286
GND1: GND; TestPoint_Pad_D2.0mm
J1, J2, J5, J6: Conn_01x02_Pin; PinHeader_1x02_P2.54mm_Vertical
J4: Conn_01x06_Pin; PinHeader_1x06_P2.54mm_Vertical
J_BME1: Conn_01x04_Pin; PinHeader_1x04_P2.54mm_Vertical
J_EP1: FPC24-EP (0.5mm); Hirose_FH12-24S-0.5SH_1x24-1MP_P0.50mm_Horizontal; MFR.Part KH-FPC0.5-H2.0SMT-24P-QCHF; LCSC C3249999
J_FL1: FPC6-FL; Hirose_FH12-6S-0.5SH_1x06-1MP_P0.50mm_Horizontal; MFR.Part KH-FPC0.5-H2.0SMT-6P-QCHF; LCSC C3249990
J_NFC1: Conn_01x06_Pin; PinHeader_1x06_P2.54mm_Vertical
J_TP1: FPC6-TP; Hirose_FH12-6S-0.5SH_1x06-1MP_P0.50mm_Horizontal; MFR.Part KH-FPC0.5-H2.0SMT-6P-QCHF; LCSC C3249990
Jesp1, Jesp2: Conn_01x19_Socket; PinSocket_1x19_P2.54mm_Vertical
L1: 47 uH 500mA(Max); L_1812_4532Metric; MFR.Part ACC4532470K2B; LCSC C22469103
M1: Fan_SYS_4pin; FanPinHeader_1x04_P2.54mm_Vertical
MH1, MH2: M2.5; MountingHole_2.7mm_M2.5_Pad_Via
PREVGH1: PREVGH; TestPoint_Pad_D2.0mm
PREVGL1: PREVGL; TestPoint_Pad_D2.0mm
Q1: Si1308EDL; SOT-323_SC-70; MFR.Part SI1308EDL-VB; LCSC C4355112
Q2: AO3400A; SOT-23; MFR.Part AO3400A; LCSC C20917
R1: 100k; R_0603_1608Metric; MFR.Part 0603WAF1003T5E; LCSC C25803
R2: 1M; R_0603_1608Metric; MFR.Part 0603WAF1004T5E; LCSC C22935
R3: 0.47; R_0603_1608Metric; MFR.Part 0603WAF470LT5E; LCSC C23411
R4, R8, R10, R11, R13, R14, R18: 10k; R_0603_1608Metric; MFR.Part 0603WAF1002T5E; LCSC C25804
R6, R16: 220; R_0603_1608Metric; MFR.Part 0603WAF2200T5E; LCSC C22962
R7: 5; R_0603_1608Metric; MFR.Part 0603WAF510KT5E; LCSC C25197
R12, R15: 0R; R_0603_1608Metric; MFR.Part 0603WAF0000T5E; LCSC C21189
U1: RT9193-33GB; SOT-23-5_RIT; MFR.Part RT9193-33GB; LCSC C15651
U2: 74LVC1G66; SOT-353_SC-70-5; MFR.Part U74LVC1G66G; LCSC C7509611
U3: TMP102xxDRL; SOT-563; MFR.Part TMP102AIDRLR; LCSC C99269

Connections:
+3.3V: C2.1, C3.1, C9.2, C16.1, C20.1, J4.5 (3V3), J_BME1.1 (VCC), J_EP1.15 (VDDIO), J_EP1.16 (VCI), J_NFC1.5 (VDD), J_TP1.2 (VDD), Jesp1.1 (+3.3V), L1.1, R4.1, R8.1, R11.1, R13.1, R14.1, R18.1, U2.5 (VCC), U3.5 (V+)
+5V: C1.1, C18.1, C19.1, J6.1, Jesp1.19 (VIN), M1.2 (+), R1.1, U1.1 (VIN), U1.3 (EN)
/BS: J_EP1.8 (BS), R11.2, R12.1
/Button: C17.1, J1.1, Jesp1.5 (G34), R4.2
/Buzzer: BZ1.1 (+), Jesp1.7 (G32)
/DIM: Jesp2.8 (G19), R6.1, R10.1
/EN: J4.3 (EN), Jesp1.2 (EN)
/EP-BUSY: J_EP1.9 (BUSY), Jesp1.15 (G13)
/EP-CS: J_EP1.12 (CS), Jesp1.11 (G27)
/EP-D/C: Jesp1.12 (G14), R15.1
/EP-MOSI: J_EP1.14 (SDA), Jesp2.2 (G23)
/EP-RES: J_EP1.10 (RES), Jesp1.13 (G12)
/EP-SCK: J_EP1.13 (SCL), Jesp2.9 (G18)
/Fan PWM: Jesp1.9 (G25), M1.4 (PWM)
/Fan vit: Jesp1.10 (G26), M1.3 (Tacho), R18.2
/G00: J4.4 (G00), Jesp2.14 (G00)
/G02: Jesp2.15 (G02)
/G04: Jesp2.13 (G04)
/GDR: J_EP1.2 (GDR), Q1.1 (G), R2.1
/I2C-SCL: J_BME1.3 (SCL), J_EP1.6 (TSCL), J_NFC1.2 (SCL), J_TP1.6 (SCL), Jesp2.3 (G22), R13.2, U3.1 (SCL)
/I2C-SDA: J_BME1.4 (SDA), J_EP1.7 (TSDA), J_NFC1.1 (SDA), J_TP1.5 (SDA), Jesp2.6 (G21), R14.2, U3.6 (SDA)
/IRQ: J_NFC1.3 (IRQ), Jesp1.3 (VP)
/J2 Jump: D4.2 (A), Jesp1.8 (G33), U2.4
/PREVGH: C8.1, D3.1 (K), J_EP1.21 (VGH), PREVGH1.1
/PREVGL: C7.1, D1.2 (A), J_EP1.23 (VGL), PREVGL1.1
/RESE: J_EP1.3 (RESE), Q1.2 (S), R3.1
/SN: Jesp1.4 (SN)
/TP-INT: J_TP1.4 (INT), Jesp1.6 (G35), R8.2
/TP-RST: J_TP1.3 (RST), Jesp2.16 (G15)
/UART-RX: J5.2, Jesp2.12 (G16)
/UART-RX0: J4.2 (RX), Jesp2.5 (G03)
/UART-TX: J5.1, Jesp2.11 (G17)
/UART-TX0: J4.1 (TX), Jesp2.4 (G01)
/VEN: J_NFC1.4 (VEN), Jesp2.10 (G05)
GND: BZ1.2 (-), C1.2, C2.2, C3.2, C5.2, C6.2, C7.2, C8.2, C9.1, C10.1, C11.1, C12.1, C13.1, C14.2, C15.1, C16.2, C17.2, C18.2, C19.2, C20.2, D2.1 (K), GND1.1, J1.2, J4.6 (GND), J6.2, J_BME1.2 (GND), J_EP1.17 (VSS), J_NFC1.6 (GND), J_TP1.1 (GND), Jesp1.14 (GND), Jesp2.1 (GND), Jesp2.7 (GND), M1.1 (-), MH1.1, MH2.1, Q2.3 (D), R1.2, R2.2, R3.2, R10.2, R12.2, R16.2, U1.2 (GND), U2.3 (GND), U3.2 (GND), U3.4 (ADD0)
unnamed: C15.2, J_EP1.4 (NC)
unnamed: C4.1, D1.1 (K), D2.2 (A)
unnamed: C4.2, D3.2 (A), L1.2, Q1.3 (D)
unnamed: D4.1 (K), R16.1
unnamed: J2.1, U2.2
unnamed: J2.2, U2.1
unnamed: J_EP1.11 (D/C), R15.2
unnamed: C11.2, J_EP1.24 (VCOM)
unnamed: C13.2, J_EP1.18 (VDD)
unnamed: C10.2, J_EP1.20 (VSH1)
unnamed: C12.2, J_EP1.5 (VSH2)
unnamed: C14.1, J_EP1.22 (VSL)
unnamed: J_FL1.1, J_FL1.2, R7.2
unnamed: J_FL1.5, J_FL1.6, Q2.2 (S)
unnamed: Q2.1 (G), R6.2
unnamed: C5.1, U1.4 (BP)
unnamed: C6.1, R7.1, U1.5 (VOUT)

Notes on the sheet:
FAN 5V PWM
TEMP_SYS_I2C
Pin BME280 I2C
E-Paper screen from Good Display. Touch + light
Uart + alimentation esp
Uart DEBUG
Jump J2 Raspberry Pi
Button Esp
Pin NFC I2C
Buzzer touch

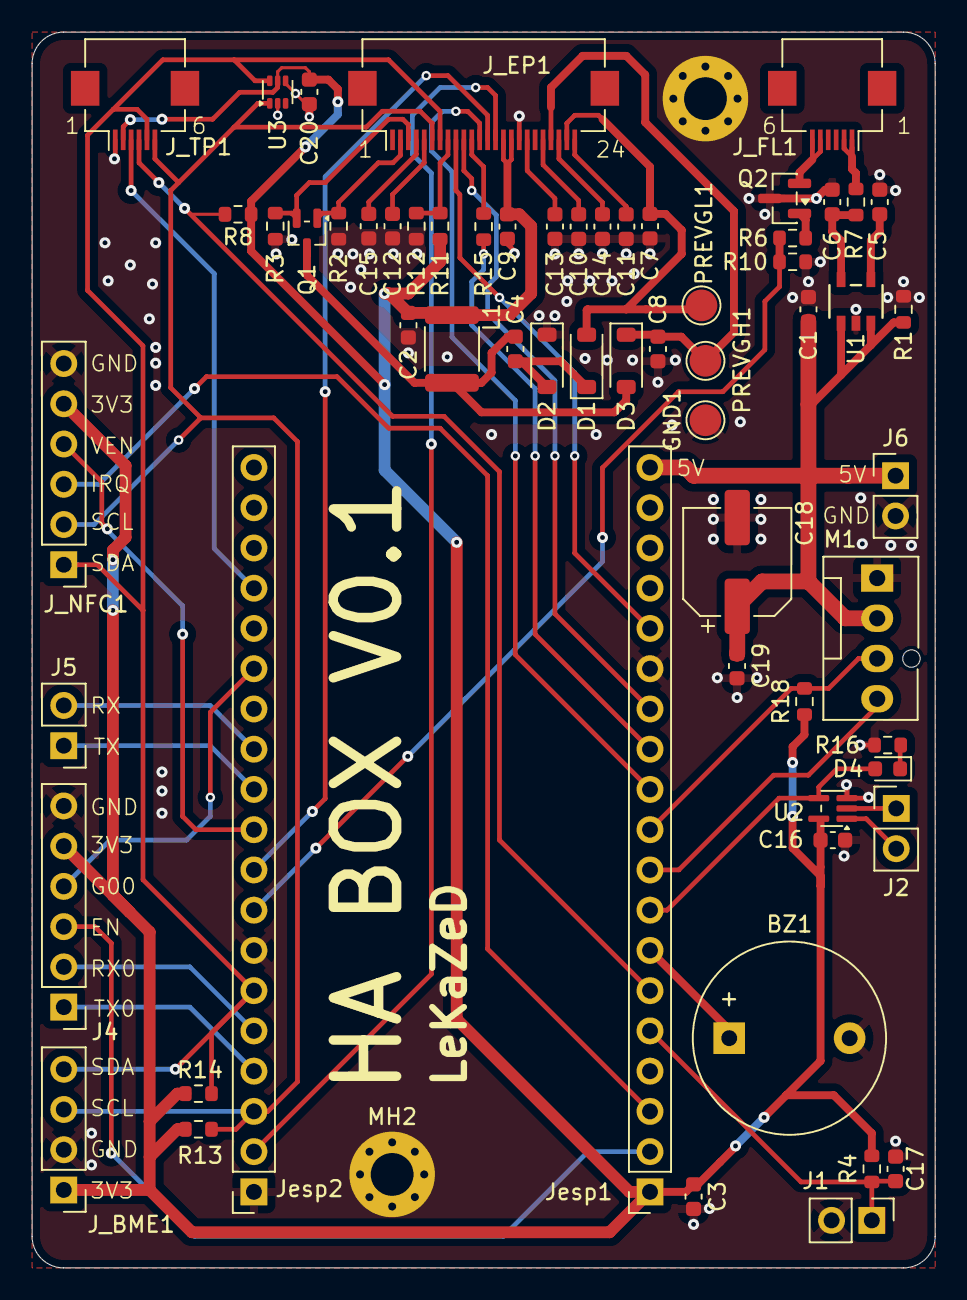
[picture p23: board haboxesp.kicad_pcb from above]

Board: 2 copper layers, 57.0 x 78.0 mm, 64 parts (0 on the bottom side), 49 nets.

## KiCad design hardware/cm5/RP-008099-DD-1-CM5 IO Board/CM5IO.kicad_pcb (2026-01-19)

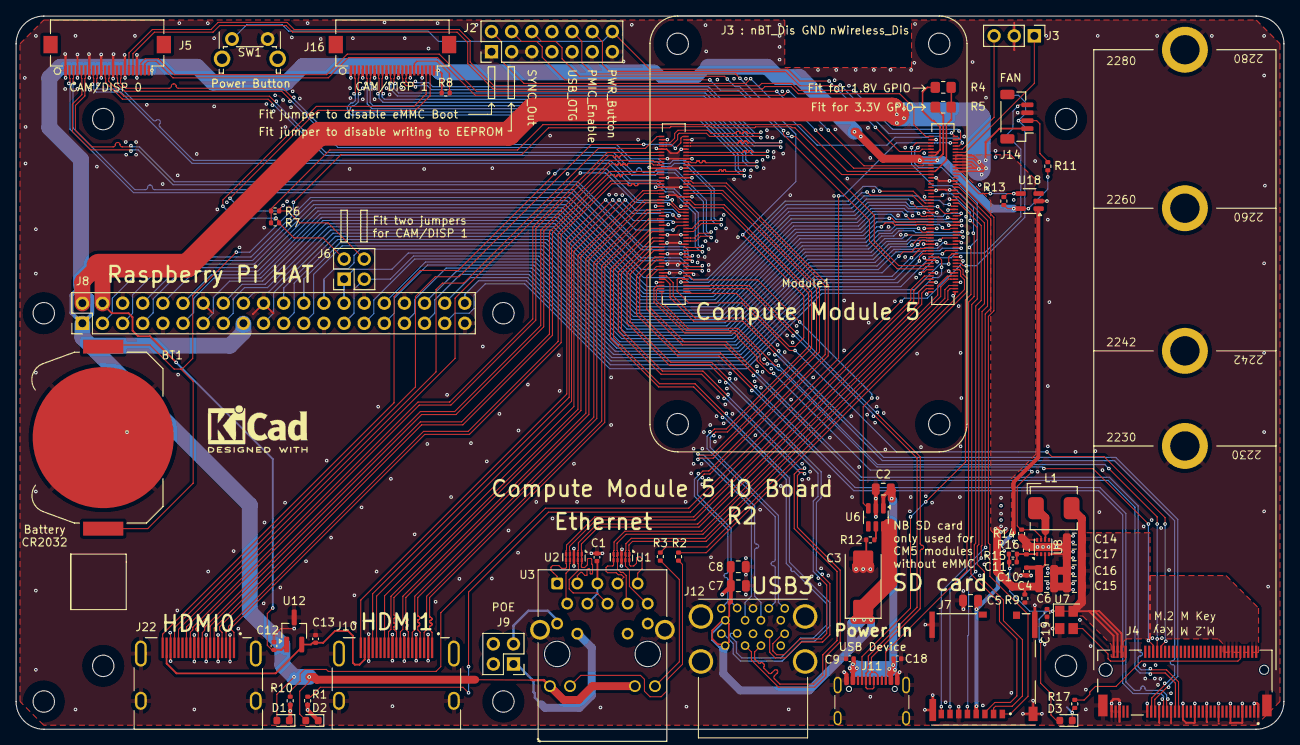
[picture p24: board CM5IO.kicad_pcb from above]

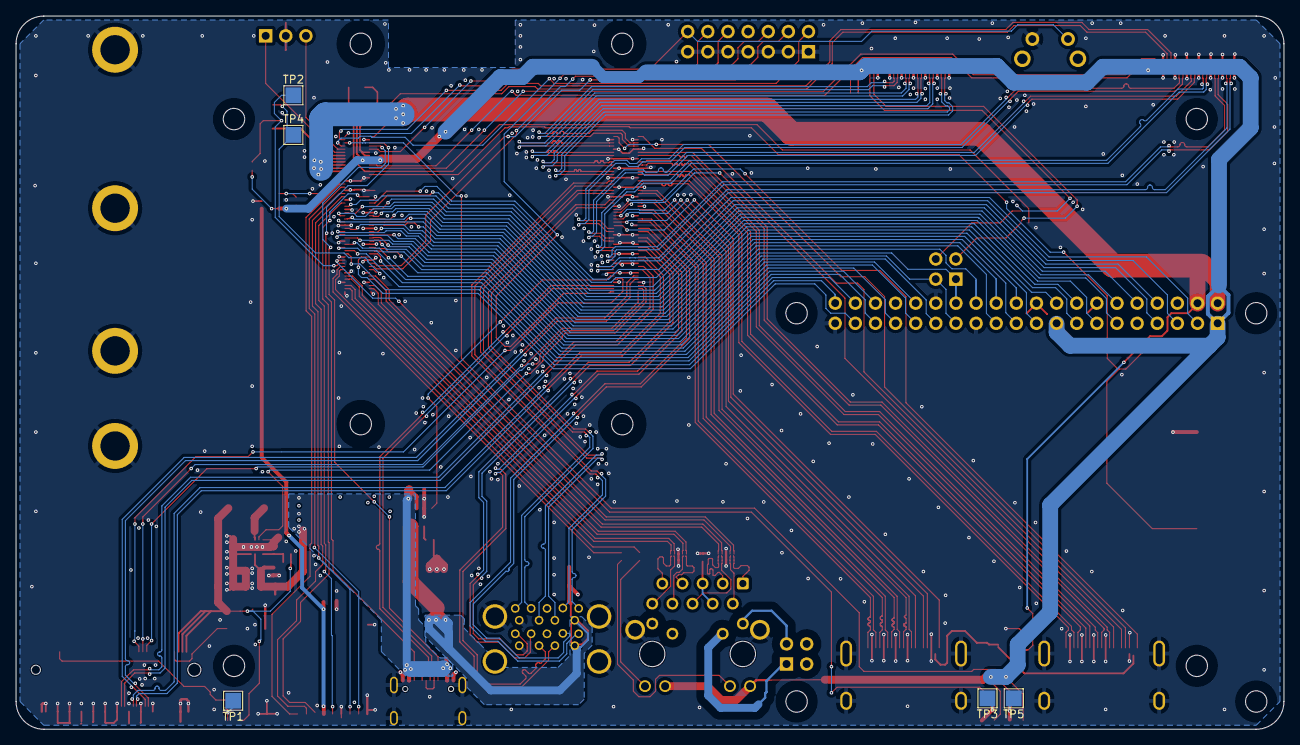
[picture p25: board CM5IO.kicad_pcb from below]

Board: 4 copper layers, 160.0 x 90.0 mm, 78 parts (5 on the bottom side), 160 nets.

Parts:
BT1: Battery_Cell; BatteryHolder_Keystone_3034_1x20mm
C1, C9, C10, C12, C13, C18, C19: 100n; C_0402_1005Metric
C2, C4, C5, C6, C7, C8, C14, C15, C16, C17: 10u; C_0805_2012Metric
C3: 100uF; CP_EIA-7343-31_Kemet-D
C11: 4.7nF; C_0402_1005Metric
D1: LED Red; LED_0603_1608Metric
D2, D3: LED Green; LED_0603_1608Metric
H1, H2, H3, H4, H5, H6, H7, H8: MountingHole; MountingHole_2.7mm_M2.5_DIN965
J2: Conn_02x07_Odd_Even; PinHeader_2x07_P2.54mm_Vertical
J3: Conn_01x03; PinHeader_1x03_P2.54mm_Vertical
J4: Bus_M.2_Socket_M; M.2 M Key socket
J5, J16: Conn_01x22_Female; Hirose_FH12-22S-0.5SH_1x22-1MP_P0.50mm_Horizontal
J6, J9: THD-02-R; PinHeader_2x02_P2.54mm_Vertical
J7: Micro_SD_Card_Det; SDCARD_MOLEX_503398-1892
J8: THD-20-R; PinHeader_2x20_P2.54mm_Vertical
J10, J22: 690-019-298-412; EDAC 690-019-298-412
J11: USB_C_Receptacle_USB2.0; USB_C_Receptacle_GCT_USB4105-xx-A_16P_TopMnt_Horizontal
J12: USB3_A; MTCONN_UBAF30-D2011
J14: JST_SHBM04B-SRSS-TB; JST_SH_BM04B-SRSS-TB_1x04-1MP_P1.00mm_Vertical
L1: 2.2uH; L_Bourns_SRP5030CC
Module1: ComputeModule5-CM5; Raspberry-Pi-5-Compute-Module
R1, R10, R17: 1k; R_0402_1005Metric
R2, R3: 470R; R_0402_1005Metric
R4: nf; R_0805_2012Metric_Pad1.20x1.40mm_HandSolder
R5: 0R; R_0805_2012Metric_Pad1.20x1.40mm_HandSolder
R6, R7, R8, R9, R16: 2.2K 1%; R_0402_1005Metric
R11, R13, R15: 10K 1%; R_0402_1005Metric
R12: 15K 1%; R_0402_1005Metric
R14: 100K 1%; R_0402_1005Metric
SW1: Right angle Tact button; SW_Tactile_SPST_Angled_PTS645Vx58-2LFS
TP1, TP2, TP3, TP4, TP5: TestPoint; TestPoint_Pad_2.0x2.0mm
U1, U2: TPD4EUSB30; USON-10_2.5x1.0mm_P0.5mm
U3: MagJack-A70-112-331N126; TRJG0926HENL
U6: AP22653W6; SOT-23-6
U7: ASEK-32.768KHZ-L-R-T; Crystal_SMD_3225-4Pin_3.2x2.5mm
U8: AP3441SHE-7B; DFN-8-1EP_2x2mm_P0.5mm_EP1.05x1.75mm
U12: RT9742SNGV; TSOT-23_HandSoldering
U18: RT9742GGJ5; SOT-23-5

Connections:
/+3.3v: D1.2 (A), D2.2 (A), J5.22, J8.1, J8.17, J16.22, Module1.84 (+3.3v_(Output)), Module1.86 (+3.3v_(Output)), R5.1, R8.1, R11.1, R13.1, U3.15 (LEDY_A), U3.17 (LEDG_A), U18.5 (IN)
/+5v: C2.1, C4.1, C6.1, C9.1, C10.1, C12.1, C18.1, J8.2, J8.4, J11.A4 (VBUS), J11.A9 (VBUS), J11.B4 (VBUS), J11.B9 (VBUS), J14.1, Module1.77 (+5v_(Input)), Module1.79 (+5v_(Input)), Module1.81 (+5v_(Input)), Module1.83 (+5v_(Input)), Module1.85 (+5v_(Input)), Module1.87 (+5v_(Input)), R9.1, U6.1 (IN), U8.3 (VIN), U12.1 (IN)
/CC1: J11.A5 (CC1), Module1.94 (CC1)
/CC2: J11.B5 (CC2), Module1.96 (CC2)
/CM5_GPIO ( Ethernet, GPIO, SDCARD)/+1.8v: Module1.88 (+1.8v_(Output)), Module1.90 (+1.8v_(Output)), R4.1
/CM5_GPIO ( Ethernet, GPIO, SDCARD)/BT_nDis: J3.3, Module1.91 (BT_nDisable)
/CM5_GPIO ( Ethernet, GPIO, SDCARD)/CAM_GPIO0: J5.17, Module1.97 (CAM_GPIO0)
/CM5_GPIO ( Ethernet, GPIO, SDCARD)/CAM_GPIO1: J5.18, Module1.100 (CAM_GPIO1)
/CM5_GPIO ( Ethernet, GPIO, SDCARD)/EEPROM_nWP: J2.4, Module1.20 (EEPROM_nWP)
/CM5_GPIO ( Ethernet, GPIO, SDCARD)/ETH_LEDG: Module1.17 (Ethernet_nLED2(3.3v)), R2.2
/CM5_GPIO ( Ethernet, GPIO, SDCARD)/ETH_LEDY: Module1.15 (Ethernet_nLED3(3.3v)), R3.2
/CM5_GPIO ( Ethernet, GPIO, SDCARD)/GPIO2: J8.3, Module1.58 (GPIO2)
/CM5_GPIO ( Ethernet, GPIO, SDCARD)/GPIO3: J8.5, Module1.56 (GPIO3)
/CM5_GPIO ( Ethernet, GPIO, SDCARD)/GPIO4: J8.7, Module1.54 (GPIO4)
/CM5_GPIO ( Ethernet, GPIO, SDCARD)/GPIO5: J8.29, Module1.34 (GPIO5)
/CM5_GPIO ( Ethernet, GPIO, SDCARD)/GPIO6: J8.31, Module1.30 (GPIO6)
/CM5_GPIO ( Ethernet, GPIO, SDCARD)/GPIO7: J8.26, Module1.37 (GPIO7)
/CM5_GPIO ( Ethernet, GPIO, SDCARD)/GPIO8: J8.24, Module1.39 (GPIO8)
/CM5_GPIO ( Ethernet, GPIO, SDCARD)/GPIO9: J8.21, Module1.40 (GPIO9)
/CM5_GPIO ( Ethernet, GPIO, SDCARD)/GPIO10: J8.19, Module1.44 (GPIO10)
/CM5_GPIO ( Ethernet, GPIO, SDCARD)/GPIO11: J8.23, Module1.38 (GPIO11)
/CM5_GPIO ( Ethernet, GPIO, SDCARD)/GPIO12: J8.32, Module1.31 (GPIO12)
/CM5_GPIO ( Ethernet, GPIO, SDCARD)/GPIO13: J8.33, Module1.28 (GPIO13)
/CM5_GPIO ( Ethernet, GPIO, SDCARD)/GPIO14: J8.8, Module1.55 (GPIO14)
/CM5_GPIO ( Ethernet, GPIO, SDCARD)/GPIO15: J8.10, Module1.51 (GPIO15)
/CM5_GPIO ( Ethernet, GPIO, SDCARD)/GPIO16: J8.36, Module1.29 (GPIO16)
/CM5_GPIO ( Ethernet, GPIO, SDCARD)/GPIO17: J8.11, Module1.50 (GPIO17)
/CM5_GPIO ( Ethernet, GPIO, SDCARD)/GPIO18: J8.12, Module1.49 (GPIO18)
/CM5_GPIO ( Ethernet, GPIO, SDCARD)/GPIO19: J8.35, Module1.26 (GPIO19)
/CM5_GPIO ( Ethernet, GPIO, SDCARD)/GPIO20: J8.38, Module1.27 (GPIO20)
/CM5_GPIO ( Ethernet, GPIO, SDCARD)/GPIO21: J8.40, Module1.25 (GPIO21)
/CM5_GPIO ( Ethernet, GPIO, SDCARD)/GPIO22: J8.15, Module1.46 (GPIO22)
/CM5_GPIO ( Ethernet, GPIO, SDCARD)/GPIO23: J8.16, Module1.47 (GPIO23)
/CM5_GPIO ( Ethernet, GPIO, SDCARD)/GPIO24: J8.18, Module1.45 (GPIO24)
/CM5_GPIO ( Ethernet, GPIO, SDCARD)/GPIO25: J8.22, Module1.41 (GPIO25)
/CM5_GPIO ( Ethernet, GPIO, SDCARD)/GPIO26: J8.37, Module1.24 (GPIO26)
/CM5_GPIO ( Ethernet, GPIO, SDCARD)/GPIO27: J8.13, Module1.48 (GPIO27)
/CM5_GPIO ( Ethernet, GPIO, SDCARD)/GPIO_VREF: Module1.78 (GPIO_VREF(1.8v/3.3v_Input)), R4.2, R5.2, R6.1, R7.1
/CM5_GPIO ( Ethernet, GPIO, SDCARD)/ID_SC: J6.1, J8.28, Module1.35 (ID_SC)
/CM5_GPIO ( Ethernet, GPIO, SDCARD)/ID_SD: J6.3, J8.27, Module1.36 (ID_SD)
/CM5_GPIO ( Ethernet, GPIO, SDCARD)/PMIC_ENABLE: J2.12, Module1.99 (PMIC_ENABLE)
/CM5_GPIO ( Ethernet, GPIO, SDCARD)/PWM: J14.2, Module1.19 (FAN_PWM), R11.2, TP2.1
/CM5_GPIO ( Ethernet, GPIO, SDCARD)/PWR_BUT: J2.14, Module1.92 (PWR_BUT), SW1.1
/CM5_GPIO ( Ethernet, GPIO, SDCARD)/SD_CLK: J7.5 (CLK), Module1.57 (SD_CLK)
/CM5_GPIO ( Ethernet, GPIO, SDCARD)/SD_CMD: J7.3 (CMD), Module1.62 (SD_CMD)
/CM5_GPIO ( Ethernet, GPIO, SDCARD)/SD_DAT0: J7.7 (DAT0), Module1.63 (SD_DAT0)
/CM5_GPIO ( Ethernet, GPIO, SDCARD)/SD_DAT1: J7.8 (DAT1), Module1.67 (SD_DAT1)
/CM5_GPIO ( Ethernet, GPIO, SDCARD)/SD_DAT2: J7.1 (DAT2), Module1.69 (SD_DAT2)
/CM5_GPIO ( Ethernet, GPIO, SDCARD)/SD_DAT3: J7.2 (DAT3/CD), Module1.61 (SD_DAT3)
/CM5_GPIO ( Ethernet, GPIO, SDCARD)/SD_PWR: C5.1, J7.4 (VDD), U18.1 (OUT)
/CM5_GPIO ( Ethernet, GPIO, SDCARD)/SD_PWR_ON: Module1.75 (SD_PWR_ON), R13.2, U18.4 (EN)
/CM5_GPIO ( Ethernet, GPIO, SDCARD)/SYNC_OUT: J2.6, Module1.18 (Ethernet_SYNC_OUT(3.3v))
/CM5_GPIO ( Ethernet, GPIO, SDCARD)/TACHO: J14.4, Module1.16 (FAN_TACHO), TP4.1
/CM5_GPIO ( Ethernet, GPIO, SDCARD)/TR0_TAP: J9.3, U3.11 (VC1)
/CM5_GPIO ( Ethernet, GPIO, SDCARD)/TR1_TAP: J9.1, U3.12 (VC2)
/CM5_GPIO ( Ethernet, GPIO, SDCARD)/TR2_TAP: J9.2, U3.13 (VC3)
/CM5_GPIO ( Ethernet, GPIO, SDCARD)/TR3_TAP: J9.4, U3.14 (VC4)
/CM5_GPIO ( Ethernet, GPIO, SDCARD)/TRD0_N: Module1.10 (Ethernet_Pair0_N), U2.4 (D2+), U2.7, U3.2 (TRD0-)
/CM5_GPIO ( Ethernet, GPIO, SDCARD)/TRD0_P: Module1.12 (Ethernet_Pair0_P), U2.5 (D2-), U2.6, U3.1 (TRD0+)
/CM5_GPIO ( Ethernet, GPIO, SDCARD)/TRD1_N: Module1.6 (Ethernet_Pair1_N), U2.2 (D1-), U2.9, U3.6 (TRD1-)
/CM5_GPIO ( Ethernet, GPIO, SDCARD)/TRD1_P: Module1.4 (Ethernet_Pair1_P), U2.1 (D1+), U2.10, U3.3 (TRD1+)
/CM5_GPIO ( Ethernet, GPIO, SDCARD)/TRD2_N: Module1.9 (Ethernet_Pair2_N), U1.4 (D2+), U1.7, U3.8 (TRD2-)
/CM5_GPIO ( Ethernet, GPIO, SDCARD)/TRD2_P: Module1.11 (Ethernet_Pair2_P), U1.5 (D2-), U1.6, U3.7 (TRD2+)
/CM5_GPIO ( Ethernet, GPIO, SDCARD)/TRD3_N: Module1.5 (Ethernet_Pair3_N), U1.2 (D1-), U1.9, U3.10 (TRD3-)
/CM5_GPIO ( Ethernet, GPIO, SDCARD)/TRD3_P: Module1.3 (Ethernet_Pair3_P), U1.1 (D1+), U1.10, U3.9 (TRD3+)
/CM5_GPIO ( Ethernet, GPIO, SDCARD)/USBOTG: J2.10, Module1.101 (USB_OTG_ID)
/CM5_GPIO ( Ethernet, GPIO, SDCARD)/VBAT: BT1.1 (+), Module1.76 (VBAT)
/CM5_GPIO ( Ethernet, GPIO, SDCARD)/WL_nDis: J3.1, Module1.89 (WiFi_nDisable)
/CM5_GPIO ( Ethernet, GPIO, SDCARD)/nPWR_LED: Module1.95 (LED_nPWR), R10.2
/CM5_GPIO ( Ethernet, GPIO, SDCARD)/nRPIBOOT: J2.2, Module1.93 (nRPIBOOT)
/CM5_HighSpeed/DPHY0_C_N: J5.8, Module1.127 (MIPI0_C_N)
/CM5_HighSpeed/DPHY0_C_P: J5.9, Module1.129 (MIPI0_C_P)
/CM5_HighSpeed/DPHY0_D0_N: J5.2, Module1.115 (MIPI0_D0_N)
/CM5_HighSpeed/DPHY0_D0_P: J5.3, Module1.117 (MIPI0_D0_P)
/CM5_HighSpeed/DPHY0_D1_N: J5.5, Module1.121 (MIPI0_D1_N)
/CM5_HighSpeed/DPHY0_D1_P: J5.6, Module1.123 (MIPI0_D1_P)
/CM5_HighSpeed/DPHY0_D2_N: J5.11, Module1.133 (MIPI0_D2_N)
/CM5_HighSpeed/DPHY0_D2_P: J5.12, Module1.135 (MIPI0_D2_P)
/CM5_HighSpeed/DPHY0_D3_N: J5.14, Module1.139 (MIPI0_D3_N)
/CM5_HighSpeed/DPHY0_D3_P: J5.15, Module1.141 (MIPI0_D3_P)
/CM5_HighSpeed/DPHY1_C_N: J16.8, Module1.187 (MIPI1_C_N)
/CM5_HighSpeed/DPHY1_C_P: J16.9, Module1.189 (MIPI1_C_P)
/CM5_HighSpeed/DPHY1_D0_N: J16.2, Module1.175 (MIPI1_D0_N)
/CM5_HighSpeed/DPHY1_D0_P: J16.3, Module1.177 (MIPI1_D0_P)
/CM5_HighSpeed/DPHY1_D1_N: J16.5, Module1.181 (MIPI1_D1_N)
/CM5_HighSpeed/DPHY1_D1_P: J16.6, Module1.183 (MIPI1_D1_P)
/CM5_HighSpeed/DPHY1_D2_N: J16.11, Module1.193 (MIPI1_D2_N)
/CM5_HighSpeed/DPHY1_D2_P: J16.12, Module1.195 (MIPI1_D2_P)
/CM5_HighSpeed/DPHY1_D3_N: J16.14, Module1.194 (MIPI1_D3_N)
/CM5_HighSpeed/DPHY1_D3_P: J16.15, Module1.196 (MIPI1_D3_P)
/CM5_HighSpeed/HDMI0_CEC: J22.13 (CEC), Module1.151 (HDMI0_CEC)
/CM5_HighSpeed/HDMI0_CK_N: J22.12 (CK-), Module1.190 (HDMI0_CLK_N)
/CM5_HighSpeed/HDMI0_CK_P: J22.10 (CK+), Module1.188 (HDMI0_CLK_P)
/CM5_HighSpeed/HDMI0_D0_N: J22.9 (D0-), Module1.184 (HDMI0_TX0_N)
/CM5_HighSpeed/HDMI0_D0_P: J22.7 (D0+), Module1.182 (HDMI0_TX0_P)
/CM5_HighSpeed/HDMI0_D1_N: J22.6 (D1-), Module1.178 (HDMI0_TX1_N)
/CM5_HighSpeed/HDMI0_D1_P: J22.4 (D1+), Module1.176 (HDMI0_TX1_P)
/CM5_HighSpeed/HDMI0_D2_N: J22.3 (D2-), Module1.172 (HDMI0_TX2_N)
/CM5_HighSpeed/HDMI0_D2_P: J22.1 (D2+), Module1.170 (HDMI0_TX2_P)
/CM5_HighSpeed/HDMI0_HOTPLUG: J22.19 (HPD/HEAC-), Module1.153 (HDMI0_HOTPLUG)
/CM5_HighSpeed/HDMI0_SCL: J22.15 (SCL), Module1.200 (HDMI0_SCL)
/CM5_HighSpeed/HDMI0_SDA: J22.16 (SDA), Module1.199 (HDMI0_SDA)
/CM5_HighSpeed/HDMI1_CEC: J10.13 (CEC), Module1.149 (HDMI1_CEC)
/CM5_HighSpeed/HDMI1_CK_N: J10.12 (CK-), Module1.166 (HDMI1_CLK_N)
/CM5_HighSpeed/HDMI1_CK_P: J10.10 (CK+), Module1.164 (HDMI1_CLK_P)
/CM5_HighSpeed/HDMI1_D0_N: J10.9 (D0-), Module1.160 (HDMI1_TX0_N)
/CM5_HighSpeed/HDMI1_D0_P: J10.7 (D0+), Module1.158 (HDMI1_TX0_P)
/CM5_HighSpeed/HDMI1_D1_N: J10.6 (D1-), Module1.154 (HDMI1_TX1_N)
/CM5_HighSpeed/HDMI1_D1_P: J10.4 (D1+), Module1.152 (HDMI1_TX1_P)
/CM5_HighSpeed/HDMI1_D2_N: J10.3 (D2-), Module1.148 (HDMI1_TX2_N)
/CM5_HighSpeed/HDMI1_D2_P: J10.1 (D2+), Module1.146 (HDMI1_TX2_P)
/CM5_HighSpeed/HDMI1_HOTPLUG: J10.19 (HPD/HEAC-), Module1.143 (HDMI1_HOTPLUG)
/CM5_HighSpeed/HDMI1_SCL: J10.15 (SCL), Module1.147 (HDMI1_SCL)
/CM5_HighSpeed/HDMI1_SDA: J10.16 (SDA), Module1.145 (HDMI1_SDA)
/CM5_HighSpeed/HDMI_5v: C13.1, J10.18 (+5V), J22.18 (+5V), U12.2 (OUT)
/CM5_HighSpeed/PCIE_CLK_N: J4.53 (REFCLKn), Module1.112 (PCIe_CLK_N)
/CM5_HighSpeed/PCIE_CLK_P: J4.55 (REFCLKp), Module1.110 (PCIe_CLK_P)
/CM5_HighSpeed/PCIE_PWR_EN: Module1.106 (PCIE_PWR_EN), R14.1, U8.7 (EN)
/CM5_HighSpeed/PCIE_RX_N: J4.43 (PETp0), Module1.118 (PCIe_RX_N)
/CM5_HighSpeed/PCIE_RX_P: J4.41 (PETn0), Module1.116 (PCIe_RX_P)
/CM5_HighSpeed/PCIE_TX_N: J4.49 (PERp0), Module1.124 (PCIe_TX_N)
/CM5_HighSpeed/PCIE_TX_P: J4.47 (PERn0), Module1.122 (PCIe_TX_P)
/CM5_HighSpeed/PCIE_nCLKREQ: J4.52 (~CLKREQ), Module1.102 (PCIe_nCLKREQ)
/CM5_HighSpeed/PCIE_nRST: J4.50 (~PERST), Module1.109 (PCIe_nRST)
/CM5_HighSpeed/PCIE_nWAKE: J4.54 (~PEWAKE), Module1.104 (PCIE_nWAKE)
/CM5_HighSpeed/SCL0: J5.20, Module1.80 (SCL0)
/CM5_HighSpeed/SCL1: J6.2, J16.20, R7.2
/CM5_HighSpeed/SDA0: J5.21, Module1.82 (SDA0)
/CM5_HighSpeed/SDA1: J6.4, J16.21, R6.2
/CM5_HighSpeed/USB3-0-D_N: J12.A2 (D-), Module1.136 (USB3-0-D_N)
/CM5_HighSpeed/USB3-0-D_P: J12.A3 (D+), Module1.134 (USB3-0-D_P)
/CM5_HighSpeed/USB3-0-RX_N: J12.A6 (SSRX+), Module1.128 (USB3-0-RX_N)
/CM5_HighSpeed/USB3-0-RX_P: J12.A5 (SSRX-), Module1.130 (USB3-0-RX_P)
/CM5_HighSpeed/USB3-0-TX_N: J12.A9 (SSTX+), Module1.140 (USB3-0-TX_N)
/CM5_HighSpeed/USB3-0-TX_P: J12.A8 (SSTX-), Module1.142 (USB3-0-TX_P)
/CM5_HighSpeed/USB3-1-D_N: J12.B2 (D-), Module1.165 (USB3-1-D_N)
/CM5_HighSpeed/USB3-1-D_P: J12.B3 (D+), Module1.163 (USB3-1-D_P)
/CM5_HighSpeed/USB3-1-RX_N: J12.B6 (SSRX+), Module1.157 (USB3-1-RX_N)
/CM5_HighSpeed/USB3-1-RX_P: J12.B5 (SSRX-), Module1.159 (USB3-1-RX_P)
/CM5_HighSpeed/USB3-1-TX_N: J12.B9 (SSTX+), Module1.169 (USB3-1-TX_N)
/CM5_HighSpeed/USB3-1-TX_P: J12.B8 (SSTX-), Module1.171 (USB3-1-TX_P)
/CM5_HighSpeed/VBUS: C3.1, C7.1, C8.1, J12.A1 (VBUS), J12.B1 (VBUS), U6.6 (OUT)
/CM5_HighSpeed/VBUS_EN: Module1.111 (VBUS_EN), U6.3 (EN)
/PCIe-M2/FB: C11.2, R15.2, R16.1, U8.1 (FB)
/PCIe-M2/M2_3v3: C11.1, C14.1, C15.1, C16.1, C17.1, C19.1, D3.2 (A), J4.2 (3.3V), J4.4 (3.3V), J4.12 (3.3V), J4.14 (3.3V), J4.16 (3.3V), J4.18 (3.3V), J4.70 (3.3V), J4.72 (3.3V), J4.74 (3.3V), L1.2, R15.1, U7.1 (EN), U7.4 (VDD)
/USB2_N: J11.A7 (D-), J11.B7 (D-), Module1.103 (USB2_N)
/USB2_P: J11.A6 (D+), J11.B6 (D+), Module1.105 (USB2_P)
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

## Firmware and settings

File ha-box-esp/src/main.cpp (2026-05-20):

#include <Arduino.h>
#include <Wire.h>
#include "driver/rtc_io.h"
#include "config.h"
#include "settings_persistence.h"
#include "buzzer.h"
#include "BME280.h"
#include "TMP102.h"
#include "PowerButton.h"
#include "FanController.h"


#include <GxEPD2_BW.h>
#include "gdey/GxEPD2_370_GDEY037T03.h"
#include "touch_ft6336.h"
#include "model/model.h"
#include "ui/ui_manager.h"

//*******************************************
GxEPD2_BW<GxEPD2_370_GDEY037T03, GxEPD2_370_GDEY037T03::HEIGHT> display(GxEPD2_370_GDEY037T03(PIN_CS, PIN_DC, PIN_RST, PIN_BUSY));
TouchFT6336 touch(0x38);

Model model;
UIManager<GxEPD2_BW<GxEPD2_370_GDEY037T03, GxEPD2_370_GDEY037T03::HEIGHT>> uiManager(display, model);

#include "ui/ui_entry.h"

//*******************************************
static uint32_t lastSensMs = 0;
static uint32_t lastBmeMs = 0;
static float lastTc = 0.0f, lastPPa = 0.0f, lastHPct = 0.0f;

// petits buffers pour convertir float -> string
static char tBuf[16];
static char hBuf[16];
static char pBuf[16];
static char boxTcBuf[16];

AsciiProto proto(Serial);

BME280Min bme(0x76);
TMP102    tmp102(TMP102_ADDR);
static bool s_tmp102Ok = false;
static bool s_bmeOk    = false;

PowerButton::Config pbCfg{
  .btnPin = BTN_PIN,
  .j2Pin  = J2_PULSE_PIN,
  .j2ActiveHigh = true,
  .j2PulseMs = 150,
  .j2ResetMs = 5500,
  .debounceMs = 30,
  .minClickMs = 120,
  .maxClickMs = 2000,
  .longPressMs = 5000,
  .hbTimeoutMs = 300000,
  .shutdownPendingTimeoutMs = 60000,
  .haltingTimeoutMs = 15000,
  .piAlivePin = PIN_PI_ALIVE,
  .token = "changeme"
};

PowerButton powerBtn(pbCfg, proto);

FanController::Config fanCfg{
  .pwmPin = PWM_PIN,
  .pwmFreqHz = PWM_FREQ_HZ,
  .pwmResBits = PWM_RES_BITS,
  .tFanOff = 25.0f,
  .tFanOn  = 28.0f,
  .tFull   = 35.0f,
  .dutyMin = 10,
  .dutyMax = 255,
  .safeDuty = 255
};

FanController fan(fanCfg);

static bool authorizeIncoming(const AsciiProto::Message& msg, void* user, const char** err) {
  // Allowlist of commands accepted from the Pi
  if (strcmp(msg.verb, "READY") == 0) return true;
  if (strcmp(msg.verb, "HALTED") == 0) return true;
  if (strcmp(msg.verb, "SHUTDOWN_ACCEPTED") == 0) return true;
  if (strcmp(msg.verb, "STATUS") == 0) return true;
  if (strcmp(msg.verb, "WEATHER") == 0) return true;
  if (strcmp(msg.verb, "CLOCK") == 0) return true;
  if (strcmp(msg.verb, "LANG") == 0) return true;
  if (strcmp(msg.verb, "FAN") == 0) return true;
  if (strcmp(msg.verb, "VERSION") == 0) return true;
  if (strcmp(msg.verb, "OTA") == 0) return true;
  if (strcmp(msg.verb, "DAYMODE") == 0) return true;
  *err = "unknown_cmd";
  return false;
}

// ---- Per-verb message handlers ----

static void handleReady(const AsciiProto::Message& msg) {
  (void)msg;
  powerBtn.setPiState(PowerButton::PiState::ON);
  setLoadingProfileDefault(uiManager);
  model.setLoadingReason(i18n::loading().reasonDefault);
  const PageId cur = uiManager.getCurrentPageId();
  if (cur == PageId::Loading || cur == PageId::Shutdown) {
    uiManager.navigateTo(PageId::Home);
  }
}

static void handleHalted(const AsciiProto::Message& msg) {
  (void)msg;
  powerBtn.setPiState(PowerButton::PiState::OFF);
  model.setNet(false);
  model.setLan(false);
  model.setWifi(false);
  model.setExt(false);
  fan.setEnabled(false);
  uiManager.navigateTo(PageId::Shutdown);
}

static void handleWeather(const AsciiProto::Message& msg) {
  for (uint8_t i = 0; i < msg.kvCount; i++) {
    if (strcmp(msg.kv[i].key, "code") == 0) {
      model.setWeather((uint8_t)constrain(atoi(msg.kv[i].val), 0, WEATHER_CODE_MAX));
    } else if (strcmp(msg.kv[i].key, "tOut") == 0) {
      model.setTempOutX10((int16_t)atoi(msg.kv[i].val));
    }
  }
}

static void handleClock(const AsciiProto::Message& msg) {
  uint8_t hh = 0, mm = 0, ss = 0;
  for (uint8_t i = 0; i < msg.kvCount; i++) {
    if (strcmp(msg.kv[i].key, "hh") == 0) { int v = atoi(msg.kv[i].val); hh = (v >= 0 && v <= 23) ? (uint8_t)v : 0; }
    if (strcmp(msg.kv[i].key, "mm") == 0) { int v = atoi(msg.kv[i].val); mm = (v >= 0 && v <= 59) ? (uint8_t)v : 0; }
    if (strcmp(msg.kv[i].key, "ss") == 0) { int v = atoi(msg.kv[i].val); ss = (v >= 0 && v <= 59) ? (uint8_t)v : 0; }
  }
  model.setClock(hh, mm, ss, millis());
}

static void handleLang(const AsciiProto::Message& msg) {
  for (uint8_t i = 0; i < msg.kvCount; i++) {
    if (strcmp(msg.kv[i].key, "id") == 0) {
      uint8_t langId = (uint8_t)constrain(atoi(msg.kv[i].val), 0, 1);
      if (langId == model.settings.language) return;
      model.setLanguage(langId);
      saveSettingsIfChanged(model);
      rebuildPageAfterLanguageChange(langId, uiManager);
      Serial2.printf("[cmd] LANG set to %s (id=%u)\n", langId == 0 ? "FR" : "EN", (unsigned)langId);
      break;
    }
  }
}

static void handleFan(const AsciiProto::Message& msg) {
  bool hasEn = false, hasTOn = false, hasTFull = false;
  bool en = false;
  float tOn = 0.0f, tFull = 0.0f;
  for (uint8_t i = 0; i < msg.kvCount; i++) {
    if (strcmp(msg.kv[i].key, "en") == 0) {
      en = atoi(msg.kv[i].val) != 0; hasEn = true;
    } else if (strcmp(msg.kv[i].key, "tOn") == 0) {
      tOn = atof(msg.kv[i].val); hasTOn = true;
    } else if (strcmp(msg.kv[i].key, "tFull") == 0) {
      tFull = atof(msg.kv[i].val); hasTFull = true;
    }
  }
  if (hasEn) fan.setEnabled(en);
  if (hasTOn && hasTFull && tFull > tOn) fan.setCurve(tOn, tFull);
  Serial2.printf("[FAN] en=%d tOn=%.1f tFull=%.1f\n", (int)en, tOn, tFull);
  // Persist only when we have a complete config (all three keys present).
  if (hasEn && hasTOn && hasTFull && tFull > tOn) {
    saveFanConfig({ .enabled = en, .tOn = tOn, .tFull = tFull });
  }
}

static void handleVersion(const AsciiProto::Message& msg) {
  (void)msg;
  AsciiProto::KV verKv[] = { {"ver", ""} };
  strncpy(verKv[0].val, FIRMWARE_VERSION, sizeof(verKv[0].val) - 1);
  proto.sendCommand("VERSION", verKv, 1);
}

static void handleOta(const AsciiProto::Message& msg) {
  (void)msg;
  setLoadingProfileFirmwareUpdate(uiManager);
  model.setLoadingAnimFrame(0);
  model.setLoadingReason(i18n::loading().reasonFirmwareUpdate);
  uiManager.navigateTo(PageId::Loading);
}

static void handleDaymode(const AsciiProto::Message& msg) {
  for (uint8_t i = 0; i < msg.kvCount; i++) {
    if (strcmp(msg.kv[i].key, "mode") == 0) {
      uint8_t m = (uint8_t)constrain(atoi(msg.kv[i].val), 0, 1);
      model.setDayMode(m);
      Serial2.printf("[cmd] DAYMODE set to %s\n", m == 0 ? "day" : "night");
      break;
    }
  }
}

// STATUS: optional KV (core, sup, net, lan, wifi, ext, zigbee, thread, matter). If no KV, heartbeat only.
static void handleStatus(const AsciiProto::Message& msg) {
  for (uint8_t i = 0; i < msg.kvCount; i++) {
    const bool ok = (atoi(msg.kv[i].val) != 0);
    if      (strcmp(msg.kv[i].key, "core")   == 0) model.setCore(ok);
    else if (strcmp(msg.kv[i].key, "sup")    == 0) model.setSup(ok);
    else if (strcmp(msg.kv[i].key, "net")    == 0) model.setNet(ok);
    else if (strcmp(msg.kv[i].key, "lan")    == 0) model.setLan(ok);
    else if (strcmp(msg.kv[i].key, "wifi")   == 0) model.setWifi(ok);
    else if (strcmp(msg.kv[i].key, "ext")    == 0) model.setExt(ok);
    else if (strcmp(msg.kv[i].key, "zigbee") == 0) model.setZigbee(ok);
    else if (strcmp(msg.kv[i].key, "thread") == 0) model.setThread(ok);
    else if (strcmp(msg.kv[i].key, "matter") == 0) model.setMatter(ok);
    else if (strcmp(msg.kv[i].key, "mhz433") == 0) model.setMhz433(ok);
    else if (strcmp(msg.kv[i].key, "warn")   == 0) model.setWarnings((uint8_t)atoi(msg.kv[i].val));
    else if (strcmp(msg.kv[i].key, "err")    == 0) model.setErrors((uint8_t)atoi(msg.kv[i].val));
  }
}

// ---- Dispatcher ----

static void onMsg(const AsciiProto::Message& msg, void* user) {
  (void)user;
  Serial2.printf("[RX] id=%lu verb=%s\n", (unsigned long)msg.id, msg.verb);
  for (uint8_t i = 0; i < msg.kvCount; i++)
    Serial2.printf("  %s=%s\n", msg.kv[i].key, msg.kv[i].val);
  powerBtn.touchHeartbeat();

  if (strcmp(msg.verb, "READY")   == 0) return handleReady(msg);
  if (strcmp(msg.verb, "HALTED")  == 0) return handleHalted(msg);
  if (strcmp(msg.verb, "WEATHER") == 0) return handleWeather(msg);
  if (strcmp(msg.verb, "CLOCK")   == 0) return handleClock(msg);
  if (strcmp(msg.verb, "LANG")    == 0) return handleLang(msg);
  if (strcmp(msg.verb, "FAN")     == 0) return handleFan(msg);
  if (strcmp(msg.verb, "VERSION") == 0) return handleVersion(msg);
  if (strcmp(msg.verb, "OTA")     == 0) return handleOta(msg);
  if (strcmp(msg.verb, "DAYMODE") == 0) return handleDaymode(msg);
  if (strcmp(msg.verb, "STATUS")  == 0) return handleStatus(msg);
}

static void onRawLine(const char* line, void* user) {
  Serial2.printf("[RX raw] %s\n", line);
  powerBtn.onUartLine(line);
}

static void onSettingsBackClick(void* user) {
  (void)user;
  saveSettingsIfChanged(model);
  setupUI_rebuildAndGoHome(uiManager, model);
}

static void onAck(const AsciiProto::Ack& ack, void* user) {
  Serial2.printf("[RX] ACK id=%lu %s %s\n",
              (unsigned long)ack.id,
              ack.ok ? "OK" : "ERR",
              ack.ok ? "" : ack.err);
  powerBtn.touchHeartbeat();
}

static void onPiStateChange(PowerButton::PiState st) {
  // Log simple
  if (st == PowerButton::PiState::ON) {
    Serial2.println("PiState=ON");
    model.setWifi(true);
    // Release the RTC hold set before deep sleep so LEDC can drive the pin again.
    rtc_gpio_hold_dis((gpio_num_t)PWM_PIN);
    fan.setEnabled(true);
  }
  else if (st == PowerButton::PiState::OFF) {
    Serial2.println("PiState=OFF");
    model.setNet(false);
    model.setLan(false);
    model.setWifi(false);
    model.setExt(false);

    // Stop fan and hold PWM_PIN LOW during deep sleep.
    // LEDC stops when the ESP enters deep sleep; without holding the pin it floats
    // and the MOSFET gate can rise above Vth, keeping the fan on.
    // GPIO 25 is RTC-capable so rtc_gpio_hold_en retains the LOW state during sleep.
    fan.setEnabled(false);
    ledcDetach(PWM_PIN);
    gpio_set_direction((gpio_num_t)PWM_PIN, GPIO_MODE_OUTPUT);
    gpio_set_level((gpio_num_t)PWM_PIN, 0);
    rtc_gpio_hold_en((gpio_num_t)PWM_PIN);

    // Navigate to Shutdown from any page (condition was previously Home/Settings only,
    // which failed when the page was already Loading after SHUTDOWN_PENDING).
    if (uiManager.getCurrentPageId() != PageId::Shutdown) {
      uiManager.navigateTo(PageId::Shutdown);
    }
  }
  else if (st == PowerButton::PiState::SHUTDOWN_PENDING) {
    Serial2.println("PiState=SHUTDOWN_PENDING");
    // Show loading page immediately with shutdown reason so the screen updates
    // without waiting for HALTED (which can take up to shutdownPendingTimeoutMs).
    setLoadingProfileDefault(uiManager);
    model.setLoadingReason(i18n::loading().reasonShutdown);
    uiManager.navigateTo(PageId::Loading);
  }
  else {
    Serial2.println("PiState=HALTING");
    // Pi acknowledged shutdown — stay on Loading, wait for heartbeat silence.
    // No navigateTo here; transition to Shutdown happens when setPiState(OFF) fires.
  }
}



void setup() {

  // UART0: Pi communication (and bootloader flashing via esptool on the same lines).
  Serial.begin(115200, SERIAL_8N1);
  delay(200);

  // UART2: debug output only (GPIO16=RX, GPIO17=TX). Not connected to Pi.
  Serial2.begin(115200, SERIAL_8N1, DEBUG_RX, DEBUG_TX);

  proto.begin();
  proto.setRawLineCallback(onRawLine, nullptr);
  proto.setAuthorizeCallback(authorizeIncoming, nullptr);
  proto.setMessageCallback(onMsg, nullptr);
  proto.setAckCallback(onAck, nullptr);

  bme.beginWire(Wire, 21, 22, 100000);
  s_bmeOk = bme.begin();
  if (!s_bmeOk) {
    Serial2.println("BME280 init failed - continuing without ambient sensor");
  }

  tmp102.beginWire(Wire);
  s_tmp102Ok = tmp102.begin();
  if (!s_tmp102Ok) {
    Serial2.println("TMP102 init failed - fan will run at safe duty");
  }

  powerBtn.setOnStateChange(onPiStateChange);
  powerBtn.begin();

  fan.begin();

  // Restore fan config from NVS (set by Pi on previous connection).
  // This ensures the correct curve is applied before the Pi reconnects.
  {
    FanPersistConfig fanNvs{};
    if (loadFanConfig(fanNvs)) {
      fan.setEnabled(fanNvs.enabled);
      fan.setCurve(fanNvs.tOn, fanNvs.tFull);
    }
  }

  // Front-light starts off; applyFrontLight will set the correct level after setupUI.
  pinMode(PIN_FRONT_LIGHT, OUTPUT);
  digitalWrite(PIN_FRONT_LIGHT, LOW);

  SPI.begin(PIN_SCK, -1, PIN_MOSI, PIN_CS);
  display.init(0); // 0 = disable GxEPD2 Serial diagnostics (Serial is used for Pi UART)
  pinMode(PIN_BUSY, INPUT);
  pinMode(PIN_BUZZER, OUTPUT);
  digitalWrite(PIN_BUZZER, LOW);

  // Rotation: selon ton montage (0/1/2/3). Ajuste si besoin.
  display.setRotation(2);

  // Force: PAS de fast partial update (differential)
  // (GxEPD2 expose ce flag sur le driver)
  //display.epd2.hasFastPartialUpdate;


  touch.begin(PIN_I2C_SDA, PIN_I2C_SCL, PIN_TOUCH_IRQ);
  touch.setDisplayWidth(240);   // invert X so touch matches display (rotation 2)
  touch.setDisplayHeight(display.height());  // invert Y so touch matches display

  setupUI(uiManager, model, onSettingsBackClick, nullptr, &proto);
  applyFrontLight(model.settings.brightness);  // restore saved brightness

  Serial2.println("Boot OK");

  // Let the UART settle and any ROM boot noise flush before sending to Pi.
  delay(1000);
  proto.sendCommand("READY", nullptr, 0);

  // Send firmware version immediately after READY so Pi can detect mismatches.
  AsciiProto::KV verKv[] = { {"ver", ""} };
  strncpy(verKv[0].val, FIRMWARE_VERSION, sizeof(verKv[0].val) - 1);
  proto.sendCommand("VERSION", verKv, 1);
}

void loop() {
  proto.poll();
  powerBtn.update();
  uint32_t now = millis(); // captured after poll so setClock's clockReceivedAtMs <= now
  model.updateClockDisplay(now);

  // Debug commands via Serial2 — wrapped in a lambda so that early return
  // exits the command handler only, not loop() itself. Without this, returning
  // here would skip uiManager.update(), sensor reads, and touch polling.
  if (Serial2.available() > 0)
  {
    [&]() {
      char inputBuf[64];
      int n = (int)Serial2.readBytesUntil('\n', inputBuf, (int)sizeof(inputBuf) - 1);
      while (n > 0 && (inputBuf[n - 1] == '\r' || inputBuf[n - 1] == ' ')) --n;
      inputBuf[n] = '\0';

      if (n == 0) return;

      char cmd = inputBuf[0];

      // Front-light test: f<0-4>  e.g. f0=off, f4=max
      if (cmd == 'f' && n > 1)
      {
        uint8_t level = (uint8_t)constrain(atoi(inputBuf + 1), 0, 4);
        applyFrontLight(level);
        Serial2.printf("[cmd] front-light level=%u/4\n", level);
        return;
      }

      // Raw GPIO test: g0=LOW, g1=HIGH (no LEDC, direct digitalWrite)
      if (cmd == 'g' && n > 1)
      {
        int val = atoi(inputBuf + 1);
        ledcDetach(PIN_FRONT_LIGHT);
        pinMode(PIN_FRONT_LIGHT, OUTPUT);
        digitalWrite(PIN_FRONT_LIGHT, val ? HIGH : LOW);
        Serial2.printf("[cmd] GPIO%d -> %s\n", PIN_FRONT_LIGHT, val ? "HIGH" : "LOW");
        return;
      }

      // TMP102 read: 't' -> print current temperature
      if (cmd == 't' && n == 1)
      {
        float tC = 0.0f;
        if (!s_tmp102Ok) {
          Serial2.println("[cmd] TMP102 not initialized");
        } else if (!tmp102.read(tC)) {
          Serial2.println("[cmd] TMP102 read failed");
        } else {
          Serial2.printf("[cmd] TMP102 = %.2f C\n", tC);
        }
        return;
      }

      // Fan manual control: v<0-255>  e.g. v0=stop, v128=50%, v255=full
      // Bypasses temperature logic; the automatic loop will resume control on next sensor read.
      if (cmd == 'v' && n > 1)
      {
        uint8_t duty = (uint8_t)constrain(atoi(inputBuf + 1), 0, 255);
        if (duty == 0) {
          fan.stop();
        } else {
          ledcWrite(PWM_PIN, duty);
        }
        Serial2.printf("[cmd] fan duty=%u/255\n", duty);
        return;
      }

      // Language: l0 = FR, l1 = EN. Only if language actually changed: save and rebuild.
      if (cmd == 'l' && n > 1)
      {
        uint8_t langId = (uint8_t)constrain(atoi(inputBuf + 1), 0, 1);
        if (langId != model.settings.language) {
          model.setLanguage(langId);
          saveSettingsIfChanged(model);
          rebuildPageAfterLanguageChange(langId, uiManager);
          Serial2.printf("[cmd] language set to %s\n", langId == 0 ? "FR" : "EN");
        }
        return;
      }

      // Test weather icon: w<0-15>  e.g. w12=sunny, w9=rainy, w0=N/A
      if (cmd == 'w' && n > 1)
      {
        uint8_t code = (uint8_t)constrain(atoi(inputBuf + 1), 0, WEATHER_CODE_MAX);
        Serial2.printf("[cmd] weather test - code: %u\n", code);
        model.setWeather(code);
        model.setTempOutX10(225);
        uiManager.update();
        return;
      }

      // Handle single character commands
      switch (cmd)
      {
        case 'c':
          Serial2.println("[cmd] clear");
          break;
        case 's':
          Serial2.println("[cmd] sleep");
          break;
        case 'j':
          model.setNet(true);
          model.setWifi(true);
          model.setExt(true);
          model.setZigbee(true);
          model.setThread(true);
          model.setIr(true);
          model.setMhz433(true);
          model.setMatter(true);
          break;
        case 'p':
          uiManager.navigateTo(PageId::Onboarding);
          break;
        case 'o':
          uiManager.navigateTo(PageId::Home);
          break;
        case 'm':
          uiManager.navigateTo(PageId::Loading);
          break;
        case 'w':
          Serial2.println("[cmd] weather test - usage: w0-w15");
          Serial2.println("  0=N/A, 1=night, 2=cloudy, 3=fog, 4=hail");
          Serial2.println("  5=lightning, 6=lightning-rain, 7=partlycloudy");
          Serial2.println("  8=pouring, 9=rainy, 10=snowy, 11=snowy-rain");
          Serial2.println("  12=sunny, 13=windy, 14=windy-cloudy, 15=alert");
          break;
        default:
          Serial2.println("[cmd] unknown");
          break;
      }
    }();
  }

  // Sensors + model + fan: every 5 s.
  // TMP102 -> box temperature -> fan control.
  // BME280 -> ambient temperature/humidity/pressure -> display + SENS.
  if (now - lastBmeMs >= BME_PERIOD_MS) {
    lastBmeMs = now;

    // TMP102: box temperature drives the fan
    float boxTc = 0.0f;
    if (s_tmp102Ok) {
      if (!tmp102.read(boxTc)) {
        Serial2.println("TMP102 read failed -> fan safe 100%");
        fan.safeMode();
      } else {
        fan.updateFromTemperature(boxTc);
      }
    }

    // BME280: ambient temperature/humidity/pressure for display and Pi
    float tC, pPa, hPct;
    if (bme.read(tC, pPa, hPct)) {
      lastTc = tC;
      lastPPa = pPa;
      lastHPct = hPct;
      model.setTempInX10((int16_t)constrain((int)(tC * 10.0f), -32768, 32767));
      model.setHumidity((uint8_t)constrain((int)hPct, 0, 100));
    }
  }

  // Send sensors every 30 s to Pi (uses last BME values + TMP102 case temp).
  if (powerBtn.getPiState() == PowerButton::PiState::ON) {
    if (now - lastSensMs >= SENS_PERIOD_MS) {
      lastSensMs = now;

      // BME280: ambient temperature, humidity, pressure (only if sensor initialised)
      if (s_bmeOk) {
        snprintf(tBuf, sizeof(tBuf), "%.2f", lastTc);
        snprintf(hBuf, sizeof(hBuf), "%.2f", lastHPct);
        snprintf(pBuf, sizeof(pBuf), "%.0f", lastPPa);
        AsciiProto::KV kv[] = {
          {"tC",  ""}, {"hum", ""}, {"pPa", ""}
        };
        strncpy(kv[0].val, tBuf, sizeof(kv[0].val) - 1);
        strncpy(kv[1].val, hBuf, sizeof(kv[1].val) - 1);
        strncpy(kv[2].val, pBuf, sizeof(kv[2].val) - 1);
        proto.sendCommand("SENS", kv, 3);
      }

      // TMP102: case (box) temperature – separate verb to avoid mixing with BME280
      if (s_tmp102Ok) {
        float caseBoxTc = 0.0f;
        if (tmp102.read(caseBoxTc)) {
          snprintf(boxTcBuf, sizeof(boxTcBuf), "%.2f", caseBoxTc);
          AsciiProto::KV caseKv[] = { {"tC", ""} };
          strncpy(caseKv[0].val, boxTcBuf, sizeof(caseKv[0].val) - 1);
          proto.sendCommand("CASE", caseKv, 1);
        }
      }
    }
  }

  // UI Update (automatic rendering)
  uiManager.update();

  //Serial.printf("T=%.2fC Fan=%s duty=%u/255\n",
  //            tC, fan.isFanActive() ? "ON" : "OFF", fan.currentDuty());

  // Poll touch every loop, with non-blocking cooldown to debounce rapid taps.
  static uint32_t lastTouchMs = 0;
  TouchFT6336::State st;
  if ((now - lastTouchMs >= TOUCH_COOLDOWN_MS) && touch.read(st) && st.count > 0)
  {
    lastTouchMs = now;
    int16_t tx = (int16_t)st.p0.x;
    int16_t ty = (int16_t)st.p0.y;
    Serial2.printf("[touch] x=%d y=%d page=%d\n", tx, ty, (int)uiManager.getCurrentPageId());
    bool consumed = uiManager.handleTouch(tx, ty);
    if (consumed) Serial2.println("[touch] consumed by page");
  }

  delay(20);  // small yield, loop stays responsive
}

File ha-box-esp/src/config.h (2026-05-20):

#pragma once

#include <stdint.h>

// Display (e-paper)
static constexpr uint8_t PIN_BUSY = 13;
static constexpr uint8_t PIN_RST  = 12;
static constexpr uint8_t PIN_DC   = 14;
static constexpr uint8_t PIN_CS   = 27;
static constexpr uint8_t PIN_SCK  = 18;
static constexpr uint8_t PIN_MOSI = 23;

// Touch
static constexpr uint8_t PIN_TOUCH_IRQ = 36;
static constexpr uint8_t PIN_I2C_SDA   = 21;
static constexpr uint8_t PIN_I2C_SCL   = 22;

// Front-light
static constexpr uint8_t PIN_FRONT_LIGHT = 19;

// UART0 (Serial)  → Pi communication + bootloader flashing (GPIO1=TX, GPIO3=RX)
// UART2 (Serial2) → debug output only (GPIO17=TX, GPIO16=RX)
static constexpr uint8_t DEBUG_TX = 17;
static constexpr uint8_t DEBUG_RX = 16;

// Firmware version reported via VERSION verb on boot.
static constexpr const char* FIRMWARE_VERSION = "0.1.1";

// Button
static constexpr uint8_t BTN_PIN = 34;

// Buzzer (active high)
static constexpr uint8_t PIN_BUZZER = 32;
static constexpr uint16_t BUZZER_BEEP_MS = 100;

// Pi start/stop (J2)
static constexpr uint8_t J2_PULSE_PIN = 33;

// Pi alive signal — GPIO5 (VEN pad).
// Pi GPIO17 (pin 11) driven HIGH by systemd; floats LOW on shutdown.
// ESP32 reads LOW → Pi is off → enter deep sleep.
static constexpr uint8_t PIN_PI_ALIVE = 5;

// TMP102 case temperature sensor (for fan control).
// I2C address: ADD0=GND->0x48, ADD0=V+->0x49, ADD0=SDA->0x4A, ADD0=SCL->0x4B
static constexpr uint8_t TMP102_ADDR = 0x48;

// Front-light PWM (AO3400A gate on PIN_FRONT_LIGHT)
// Recommended: 1-10 kHz to avoid visible flicker; 8-bit resolution (0-255).
static constexpr uint16_t FRONT_LIGHT_FREQ_HZ  = 5000;
static constexpr uint8_t  FRONT_LIGHT_RES_BITS = 8;

// Fan PWM
static constexpr uint8_t PWM_PIN = 25;
static constexpr uint8_t PWM_PIN_FAN_SPEED = 26;
static constexpr uint16_t PWM_FREQ_HZ = 25000;
static constexpr uint8_t PWM_RES_BITS = 8;

// Timing
static constexpr uint16_t SENS_PERIOD_MS = 30000;
static constexpr uint16_t BME_PERIOD_MS   = 5000;

// Weather
static constexpr uint8_t WEATHER_CODE_MAX = 15;

// Touch
static constexpr uint16_t TOUCH_COOLDOWN_MS = 200;

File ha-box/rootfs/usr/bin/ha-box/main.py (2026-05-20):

#!/usr/bin/env python3
"""
HA Box - Main application entry point.

This is the main entry point for the HA Box App.
"""

import sys
import time
from pathlib import Path
from typing import Optional

# Add the ha-box package to the path
sys.path.insert(0, str(Path(__file__).parent))

from core import Config, load_options, setup_logging, parse_log_level, get_translator
from communication import ESP32Comm, Ack, ConnectionManager, ConnectionState, MessageHandler, KV
from communication.ota_manager import OTAManager, find_bundled_firmware
from api import HomeAssistantAPI
from handlers import SensorHandler, WeatherHandler, ClockHandler, StatusHandler, DayNightHandler, RF433Handler


# Setup logging
logger = setup_logging()

# Constants
INITIALIZATION_LOOP_INTERVAL = 5.0  # Check connection every 5 seconds during initialization
MAIN_LOOP_INTERVAL = 5.0  # Check disconnection every 5 seconds during normal operation
OTA_NOTICE_DISPLAY_DELAY_S = 2.5  # Let e-paper refresh OTA notice before flashing


def handle_esp32_ack(ack: Ack) -> None:
    """
    Handle ACK from ESP32.

    Args:
        ack: ACK received from ESP32.
    """
    if ack.ok:
        logger.debug("ACK OK received: id=%d", ack.id)
    else:
        logger.warning("ACK ERR received: id=%d, error=%s", ack.id, ack.err)


def _read_bundled_version() -> Optional[str]:
    """
    Read the bundled ESP32 firmware version from the firmware filename.

    Returns:
        Version string (e.g. "0.1.1") or None if not found.
    """
    path, version = find_bundled_firmware()
    if version is None:
        logger.warning("No bundled firmware file found (expected firmware-<version>.bin)")
    else:
        logger.info("Bundled firmware: %s (version %s)", path, version)
    return version


def _check_and_run_ota(
    message_handler: MessageHandler,
    ota_manager: Optional[OTAManager],
    esp32_comm: Optional["ESP32Comm"] = None,
    force_flash: bool = False,
) -> bool:
    """
    Compare ESP32 firmware version with bundled version and flash if different.

    Sends up to _OTA_VERSION_RETRIES VERSION queries to the ESP32, waiting
    _OTA_VERSION_TIMEOUT_S seconds for a reply each time. If the versions
    differ and OTA is available, flashes the firmware.

    Args:
        message_handler: Message handler (stores esp32_firmware_version).
        ota_manager: OTA manager (None if OTA is disabled).
        esp32_comm: ESP32 comm used to (re)send VERSION queries.

    Returns:
        True if OTA was performed (caller should re-enter init loop).
        False if no OTA was needed or OTA is not available.
    """
    _OTA_VERSION_TIMEOUT_S = 5.0
    _OTA_VERSION_RETRIES = 3

    if ota_manager is None or not ota_manager.is_available:
        return False

    bundled = _read_bundled_version()
    if bundled is None:
        logger.warning("Bundled firmware version unknown, skipping OTA check")
        return False

    # Query VERSION with retries: send the query, wait for a reply, repeat if needed.
    esp32_ver = None
    for attempt in range(1, _OTA_VERSION_RETRIES + 1):
        if message_handler.esp32_firmware_version is not None:
            break  # already received from a previous send (e.g. from _initialization_loop)

        if esp32_comm is not None:
            try:
                msg_id = esp32_comm.send_command("VERSION")
                logger.info(
                    "VERSION query sent (attempt %d/%d, id=%d)",
                    attempt, _OTA_VERSION_RETRIES, msg_id,
                )
            except Exception as e:
                logger.warning("Failed to send VERSION query (attempt %d): %s", attempt, e)

        deadline = time.time() + _OTA_VERSION_TIMEOUT_S
        while time.time() < deadline:
            if message_handler.esp32_firmware_version is not None:
                break
            time.sleep(0.25)

        if message_handler.esp32_firmware_version is not None:
            break

        logger.warning(
            "No VERSION reply (attempt %d/%d)",
            attempt, _OTA_VERSION_RETRIES,
        )

    esp32_ver = message_handler.esp32_firmware_version
    if esp32_ver is None:
        logger.warning(
            "ESP32 did not respond to VERSION after %d attempts, skipping OTA check",
            _OTA_VERSION_RETRIES,
        )
        return False

    logger.info("Version check: bundled=%s, esp32=%s", bundled, esp32_ver)

    if bundled == esp32_ver and not force_flash:
        logger.info("ESP32 firmware is up to date (%s)", esp32_ver)
        return False

    if force_flash and bundled == esp32_ver:
        logger.info("force_flash=True — bypassing version check, flashing anyway")
    else:
        logger.info(
            "Firmware mismatch (bundled=%s, esp32=%s): starting OTA flash",
            bundled, esp32_ver,
        )
    if esp32_comm is not None:
        try:
            esp32_comm.send_command("OTA")
            logger.info("OTA notice sent to ESP32 (show firmware update screen)")
            time.sleep(OTA_NOTICE_DISPLAY_DELAY_S)
        except Exception as e:
            logger.warning("Failed to send OTA notice to ESP32: %s", e)
    ok = ota_manager.flash()
    if ok:
        logger.info("OTA flash succeeded. Reconnecting to ESP32...")
        message_handler.esp32_firmware_version = None  # reset for next connection
    else:
        logger.error("OTA flash failed. Continuing with current firmware.")
    return ok


def _esp32_lang_id(config_lang: str) -> int:
    """ESP32 lang id: 0 = French, 1 = English."""
    if config_lang == "fr":
        return 0
    if config_lang == "en":
        return 1
    lang = get_translator().language
    return 0 if lang == "fr" else 1
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

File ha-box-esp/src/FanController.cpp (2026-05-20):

#include "FanController.h"

FanController::FanController(const Config& cfg) : m_cfg(cfg) {}

void FanController::begin() {
  ledcAttach(m_cfg.pwmPin, m_cfg.pwmFreqHz, m_cfg.pwmResBits);
  stop();
}

void FanController::setEnabled(bool enabled) {
  m_enabled = enabled;
  if (!m_enabled) stop();
}

void FanController::setCurve(float tOn, float tFull) {
  if (tFull <= tOn) {
    Serial2.println("[FanCtrl] Invalid curve: tFull <= tOn, ignoring");
    return;
  }
  m_cfg.tFanOn  = tOn;
  m_cfg.tFull   = tFull;
  m_cfg.tFanOff = tOn - 3.0f;
}

bool FanController::isEnabled() const {
  return m_enabled;
}

void FanController::stop() {
  m_fanActive = false;
  setDuty(0);
}

uint8_t FanController::currentDuty() const {
  return m_duty;
}

bool FanController::isFanActive() const {
  return m_fanActive;
}

void FanController::safeMode() {
  if (!m_enabled) return;
  m_fanActive = true;
  setDuty(m_cfg.safeDuty);
}

void FanController::updateFromTemperature(float tC) {
  if (!m_enabled) return;

  // Hysteresis ON/OFF
  if (!m_fanActive) {
    if (tC >= m_cfg.tFanOn) m_fanActive = true;
  } else {
    if (tC <= m_cfg.tFanOff) m_fanActive = false;
  }

  uint8_t duty = m_fanActive ? mapDuty(tC) : 0;
  setDuty(duty);
}

uint8_t FanController::mapDuty(float tC) const {
  if (tC >= m_cfg.tFull) return m_cfg.dutyMax;
  if (tC <= m_cfg.tFanOn) return m_cfg.dutyMin;

  float x = (tC - m_cfg.tFanOn) / (m_cfg.tFull - m_cfg.tFanOn);
  float duty = m_cfg.dutyMin + x * (m_cfg.dutyMax - m_cfg.dutyMin);

  if (duty < 0) duty = 0;
  if (duty > 255) duty = 255;
  return (uint8_t)(duty + 0.5f);
}

void FanController::setDuty(uint8_t duty) {
  m_duty = duty;
  ledcWrite(m_cfg.pwmPin, duty); // ESP32 core 3.x => ledcWrite(pin, duty)
}

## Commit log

2026-01-19 added hardware selection & 3d design
    [CM5IO.kicad_pcb, CM5IO.kicad_sch, CM5_GPIO.kicad_sch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]
2026-01-20 Refactor documentation to English, update project descriptions, and enhance configuration options. Added testing guide and improved error handling in API client. Updated README, CONTRIBUTING, and var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
    [config.yaml, main.py]
2026-02-19 Add AsciiProto, BME280, FanController, PowerButton, and i18n modules for enhanced hardware interaction and multilingual support. Implemented configuration options for buzzer and display, and establis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
    [BME280.cpp, config.h]
2026-02-20 Refactor comments and variable names in ESPHOMEASSISTANT codebase for improved clarity and consistency. Updated language-related identifiers and documentation comments to enhance readability. Removed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
2026-02-23 Enhance compliance with Home Assistant Apps documentation by adding detailed guidelines in .cursorrules. Introduce new documentation files for HA Apps compliance and architecture of ESP32 communicati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
2026-03-05 Update version to 0.1.38 and add StatusHandler for system status updates. Introduce new status fetchers for Core, Supervisor, network, and various integrations (Zigbee, Thread, Matter, etc.). Enhance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
2026-03-05 Remove EpdUc8253 class implementation and header files from ESPHOMEASSISTANT. Update model to include new connectivity status flags for core, supervisor, network, LAN, WiFi, and external access. Intr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
2026-03-05 Update documentation and configuration for NFC integration and hardware specifications
    - Changed references from PN532 to PN7161 for the NFC reader in various documentation files, including README.md, HARDWARE.md, and translations.
    - Updated the communication and features documentation to reflect the new NFC module and its configuration.
    - Added a new document detailing the status communication between Home Assistant and the ESP32.
    - Adjusted the requirements.txt to specify the PN7161 library for future NFC integration.
    - Enhanced the architecture documentation to clarify the ESP32's role in handling NFC communications.
    Files modified:
    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
2026-03-16 Update README.md and add hardware files for HA Box project
    - Expanded the README.md to include a hardware overview section detailing the custom enclosure and PCB design.
    - Added new 3D model files for the HA Box components, including STL and STEP files for various parts.
    - Included images of the HA Box enclosure and PCB to enhance documentation.
    - README.md
    - hardware/3D plan/Box parts/Backplate.stl
    - hardware/3D plan/Box parts/Box.gcode
    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
    [Backplate.stl, Button.stl, Home assistant box side.step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]
2026-03-27 Add new STEP files for HA Box components and update STL files
    - Introduced new STEP files for various components of the HA Box, including Backplate, Box, Button, Foot, and Support.
    - Updated existing STL files for the Box and Button components to reflect the latest designs.
    - Removed the obsolete Box.gcode file and the Pied.stl file.
    - hardware/3D plan/Box parts/Backplate.step
    - hardware/3D plan/Box parts/Box.step
    - hardware/3D plan/Box parts/Button.step
    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
    [BOUTON.step, BOUTONPLEIN.step, Backplate.step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]
2026-03-29 Enhance documentation and add new features for HA Box project
    - Updated README.md to provide a comprehensive project overview, including hardware layers and detailed descriptions of components.
    - Added a Bill of Materials (BOM) document listing all components required for building the HA Box V0.1, including pricing and links.
    - Introduced new features in the ESP32 firmware, including support for the TMP102 temperature sensor and front-light control.
    - Enhanced the user interface with a new shutdown page and corresponding language support for shutdown messages.
    - ha-box/README.md
    - ha-box-esp-fw/ESPHOMEASSISTANT/config.h
    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
2026-03-31 Update ESP32 firmware documentation and enhance fan control features
    - Revised the ESP32_RASP_COM.md to include detailed descriptions of the new case temperature sensor (TMP102) and fan PWM control features.
    - Added a new README.md for the ESP32 firmware, outlining prerequisites, build instructions, and OTA update plans.
    - Implemented fan configuration persistence in the firmware, allowing runtime adjustments via the Pi.
    - Introduced new icons for the user interface, including power plug icons for enhanced visual feedback.
    - docs/ESP32_RASP_COM.md
    - ha-box-esp-fw/README.md
    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
2026-05-20 Release v0.2.0
    Squash merge of develop into main for the v0.2.0 release.
    Key additions:
    - OTA firmware update (auto-flash, blind recovery, VERSION verb retry)
    - Shutdown detection with HALTING state and accelerated heartbeat
    - Pi alive hardware signal via GPIO5
    - CC1101 433 MHz RF module (experimental, RFLink TCP port 5557)
    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
    [BOUTONPLEIN_FLAT.step, Button_power.stl, Cover.step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]

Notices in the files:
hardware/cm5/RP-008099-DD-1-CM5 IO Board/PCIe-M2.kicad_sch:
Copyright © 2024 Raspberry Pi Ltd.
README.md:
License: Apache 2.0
